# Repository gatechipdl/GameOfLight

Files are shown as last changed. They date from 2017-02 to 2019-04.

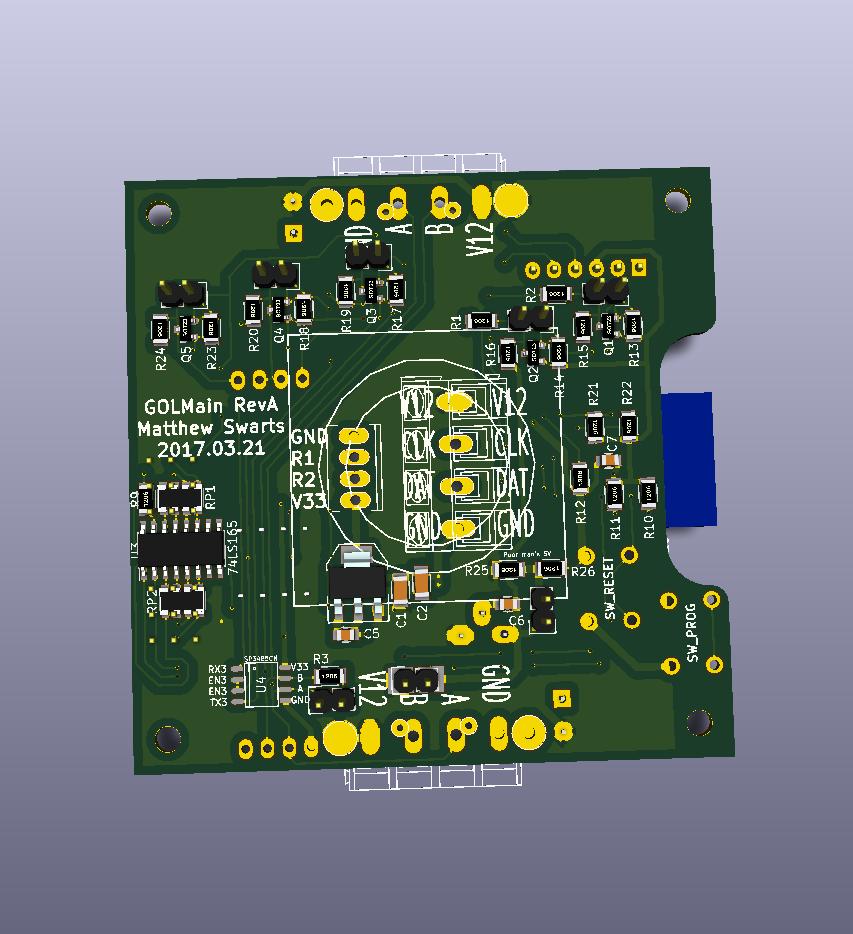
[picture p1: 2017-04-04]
electronics/GOLMain_RevA/GOLMain_RevA-render1.jpg

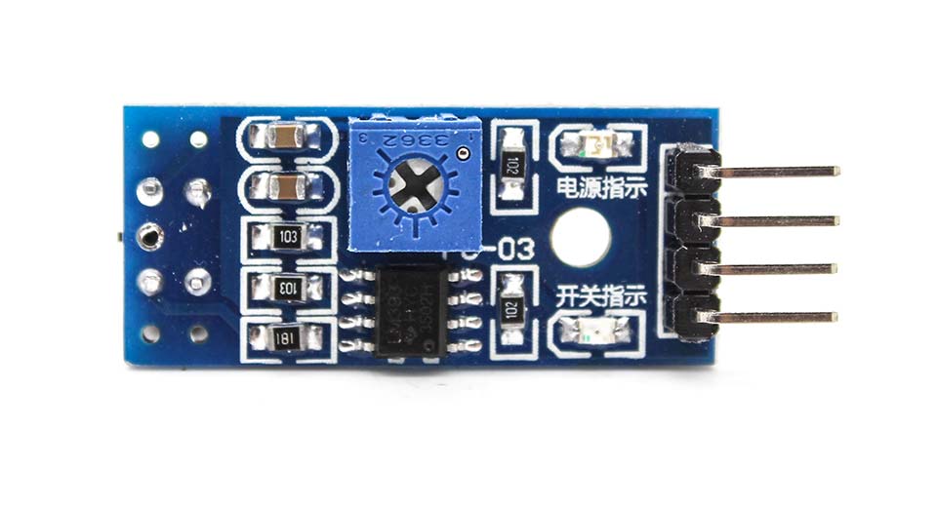
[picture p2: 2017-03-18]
electronics/TCRT5000/1506503-1.jpg

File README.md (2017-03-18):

# GameOfLight
Game of Light Installation

## Requirements
- 36 stations
- each station 1m in lenght covered in leds
- 5 sections of lamp to create a 'species'
- automatic identification of each lamp 'species'

## Location
- Hyatt Regency Denver at Co Convention Center
    - [Floorplans](https://denver.regency.hyatt.com/hyatt/images/hotels/dencc/floorplan.pdf)

## Main Power Supply
- 12,24V power supply recommended with a buck converter (for leds and mcu) or linear regulator (if for just mcu) at each location
- typical computer psu will have several 12V rails. A [modular](https://www.amazon.com/EVGA-Supernova-120-G1-1000-VR-Modular-Supply/dp/B00CGYCNG2) psu would be best for ensuring enough 12V rails without extra wiring.
- if there is 5m of leds with 30 leds/meter wrapped around a tube, then that is 150 leds. 150 leds at 60mA is 9A running at around 3V. This is around 27-30W assuming an efficient local conversion of power, which is likely embedded within the addressable chip.
- 36 stations of 30W is a total max draw of 1080W. So a 800W-1000W-1200W power supply should be fine.

## Local Power Regulation
- Switch mode power supply for high current, such as this [300W Step Down Regulator](https://www.aliexpress.com/item/DC-CC-12A-300W-Step-Down-Buck-Converter-7-32V-To-0-8-28V-Power-module/32247251105.html)
- Linear regulator for low current needs (eg. if using 12V main power supply and 12V leds)

## Power Distribution Connectors
- ribbon cable (40 pin), using most pins for power and ground
- RJ45 can only handle up to 1A
- RJ11 can only handle up to 1A
- 5557 molex need to crimp; not designed to be removed often;
- DC Barrel Jack 5.5mm, most connectors designed for 3A, but can get special ones for laptaps that can handle 8A
- [6 pin Pluggable Screw Terminal](https://www.aliexpress.com/item/Free-shipping-5-sets-ht5-08-6pin-Terminal-plug-type-300V-10A-5-08mm-pitch-connector/32667091061.html)
    - 12V - GND - DataMinus - DataPlus - GND - 12V
- [7 pin Pluggable Screw Terminal](https://www.aliexpress.com/item/Free-shipping-5-sets-ht5-08-7pin-Terminal-plug-type-300V-10A-5-08mm-pitch-connector/32665369867.html)
    - 12V - GND - DataMinus - GND - DataPlus - GND - 12V
    - extra ground in middle is for connecting ground to the main controller in the case that the main controller is not using the same ground as the stations' ground from the main power supply. For example if the main controller is run by or powered by a laptop.

## Power Distribution Wiring
- [$27 100 ft. 14/2 White Solid SIMpull NM-B Wire](http://www.homedepot.com/p/Romex-100-ft-14-2-White-Solid-SIMpull-NM-B-Wire-28827428/202316379)
- [$38 100 ft. 14-2 Black Stranded Landscape Lighting Cable](http://www.homedepot.com/p/Southwire-100-ft-14-2-Black-Stranded-Landscape-Lighting-Cable-55213243/202316247)
- [$16 100' Feet 14 Gauge Red Black Stranded 2 Conductor Speaker Wire Car Home Audio Ga](https://www.amazon.com/Gauge-Black-Stranded-Conductor-Speaker/dp/B00J36SUWC)
- [$26 eXtreme Products 2 Conductor 14 Gauge Stranded Copper Core Speaker Wire (No Aluminum Core) for Home Theater Speakers Radio Speakers Car Audio or Any Audio Interface - 100 Foot Clear Coat](https://www.amazon.com/eXtreme-Conductor-Speaker-Wire-Interface/dp/B01HBWJ1HM)

## Signal Distribution Wiring
- for RS485 we need overall impedance of 120 ohms. For our distances, lighter gauges are fine, but [this](http://www.chipkin.com/rs485-cables-why-you-need-3-wires-for-2-two-wire-rs485/) recommends 24AWG or heavier. [Here are more recommendations](http://www.bb-elec.com/Learning-Center/All-White-Papers/Serial/Cable-Selection-for-RS422-and-RS485-Systems/Cable-Selection-for-RS-422-and-RS-485-Systems.PDF).
- Two wire or Three wire. May need three wire to include an additional ground in the case that the main controller is not using the same ground as the stations' power ground from the main power supply. This could be the case with a laptop for example.
- [$13 Ethernet Cable (100 Feet)](https://www.amazon.com/Mediabridge-Ethernet-Cable-100-Feet/dp/B003RCEAB8), cut and pull out twisted pair wires
- [$23 100-Feet 24-Gauge 4 Pair Cat 5e](https://www.amazon.com/Southwire-56917643-100-Feet-Outdoor-CMR-75-Degree/dp/B005V0BJ1S)

## LEDs
- addressable color leds
- could use 1 2m strip folded over
- could use 1 5m strip wrapped around a pole (this will provide more light)
- WS2811 with 3 color leds on each section, each led is rgb, but in clusters of 3. This is fine for our applications. Also these are 12V, which is better for current draw. [$8-10 per 5m strip](https://www.aliexpress.com/item/best-price-5m-DC12V-ws2811ic-5050-RGB-SMD-individually-addressable-ws2811-led-pixels-strip/32385533484.html)

## Control
- recommended individual controller for each station; otherwise refresh rate is likely to be very slow
- attiny85 possible? may not have enough pins; but might
- atmega328p?
- arduino pro mini clone ($1-2)
- 1 master device with 36 other devices. The master controls the CA simulation and dictates the animation colors and patterns to each of the 36 stations.
    - however, it is possible to have the 36 devices run the simulation themselves, with each device getting data about it's neighbors, and computing the next step and selecting it's own animation. This would also require that they all synchronize, to some degree on an update algorithm. This could be done. Would be really nice to have. This is something we could first develop in the master/slave configuration, and then later spend time developing the slave-only method if there is time. The slave-only would really connect conceptually rather than having any kind of single master.

## Recognition
- manual input (what a drag)
- infrared linear quadrature encoder or similar to recognize the lamp 'species' as a barcode when the lamp shade is slide over the rod
    - this would argue for a separate controller on each station
- IR Distance Sensor
    - [XK-GK-5010A](https://www.aliexpress.com/item/Hot-Sale-Short-Distance-Sensor-Induction-Switch-Dual-Functions-Ir-Sensor-Switch-Active-Performance-Modules-Board/32769983297.html)
    - [TCRT5000 Sensor](https://www.aliexpress.com/item/20-pcs-TCRT5000L-TCRT5000-Reflective-Optical-Sensor-Infrared-IR-Photoelectric-Switch/1909098476.html)
    - [TCRT5000 Module with Pot](https://www.aliexpress.com/item/Free-shipping-Line-Track-Sensor-TCRT5000-Infrared-Reflective-IR-Photoelectric-Switch-Barrier/32517344067.html) [3D model](http://www.stlfinder.com/model/line-finder-tcrt5000/4505787) 32mmx14mm
    - [TCRT5000 Module Digital Only](https://www.aliexpress.com/item/New-TCRT5000-Line-Track-Sensor-Module-Reflection-Infrared-Sensor-Switch-Module-For-Arduino-5pcs-lot-Free/32359412782.html)
    - [TCRT5000 Module Analog Only](https://www.aliexpress.com/item/10PCS-IR-Infrared-Line-Track-Follower-Sensor-TCRT5000-Obstacle-Avoidanc-For-Arduino/32672744833.html)
    - [4 Channel Line Follower](https://www.aliexpress.com/item/Free-shipping-4-way-infrared-tracing-line-follow-tracking-obatacle-avoidance-Sensor-Module-for-Aduino-Robot/32645816426.html)
    - [8 Channel Line Follower](https://www.aliexpress.com/item/8-Channel-High-Precision-Infrared-Detection-Tracking-Sensor-Moudle-For-Arduino-Raspberry-Pi-Car-Robot-TCRT5000/32714804808.html)

## Communication
- if using multiple controllers, one on each station, using a [multidrop bus](https://en.wikipedia.org/wiki/Multidrop_bus) rather than a shift/ring topology
- I2C can go about [20ft](http://forum.arduino.cc/index.php?topic=57604.0) without additional driver or buffers
- RS-232 can go about [50ft](https://www.lammertbies.nl/comm/info/RS-232_specs.html)
- RS-422 can go about 5000ft, but is single driver/master, and up to 10 receivers. It is differential, so it's more noise immune than rs232, but the primary downside is it is one directional communcation
- RS-485 can go about [4000ft](http://www.bb-elec.com/Learning-Center/All-White-Papers/Serial/Basics-of-the-RS-485-Standard.aspx)
    - RS-485 to ttl converter using the MAX485CSA
    - $0.38 [Module](https://www.aliexpress.com/item/MAX485-Module-RS-485-TTL-to-RS485-MAX485CSA-Converter-Module-For-Arduino-Integrated-Circuits-Products/32667981058.html)
    - needs twisted pair wire (same as RS422); actually can go without twisted pair if run is shorter, so this isn't completely necessary
    - downside is that RS485 supports up to 32 devices. But I don't think that is built into the protocol. We should be able to go over that. As each device will have it's own way of identifying itself. I think 32 devices is more of a guideline.
    - RS-485 might need a 3.3V version like the [SP3485 Module](https://www.aliexpress.com/item/3-3V-UART-serial-to-RS485-SP3485-Transceiver-Converter-Communication-Module/32224154908.html). This board is lower cost than if we were to purchase just the chip and integrate it into our own design.

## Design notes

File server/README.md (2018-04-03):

# Light Orchard Server
Light Orchard Server

## System Architecture
### Components
|Component|Purpose|
|---|---|
|Web Client|Connects to Web Server through Socket.IO and POST|
|Web Server|Routes requests between Web Clients and Stations|
|Station|Displays colors and senses capcitive touch leves|
### Orchard Analogy?
|Analogy|System Component|
|---|---|
|Orchard|System|
|Orchardist|Web Server|
|Tree|Station|
|Branch/Frond/Fruit|Pixel (5/Station)|
|Leaf/Frond/Fruit/Seed/Bud|LED (45/Station)|

## Web Client API
### Helper/Wrapper Methods (actual API)
|Status|Method Name|Description|
|---|---|---|
|planned1|RGB2HSV()|or just use npm color|
|planned1|HSV2RGB()|or just use npm color|
|planned2|orchard-client.setStationColors()||
|planned2|orchard-client.setStationColor()||
|planned2|orchard-client.setPixelColor()||
|planned2|orchard-client.listGroup()||
|planned2|orchard-client.listGroups()||
|planned2|orchard-client.createGroup()||
|planned2|orchard-client.renameGroup()||
|planned2|orchard-client.deleteGroup()||
|planned2|orchard-client.addToGroup()||
|planned2|orchard-client.setGroupColor()||
|planned2|orchard-client.requestDataModel()||
|planned2|orchard-client.setCapMode()||
|planned2|orchard-client.setCapFreq()||
|planned2|orchard-client.onCapSenseTouch(<event handler delegate>)||
|planned2|orchard-client.onCapSenseUnTouch(<event handler delegate>)||
|planned2|orchard-client.onCapSenseHold(<event handler delegate>)||
|planned2|orchard-client.onCapSenseUnHold(<event handler delegate>)||
|planned2|orchard-client.onCapSenseDoubleTap(<event handler delegate>)||
|planned2|orchard-client.onGroupList(<event handler delegate>=)||
|planned2|orchard-client.onDataModel(<event handler delegate>=)||
### Incoming Socket.IO Events from Web Server
see Web Server API - Outgoing Socket.IO Events
### Outgoing Socket.IO Events to Web Server
see Web Server API - Incoming Socket.IO Events
### Example Use
```javascript
var socket = io.connect('/');

socket.on('connect', function() {
    socket.emit('subscribe', 'browsers'); //to receive CapSenseEvent, CapSenseTouch, CapSenseUnTouch
});

function setStationColor() {
    var tData = {};
    tData['station_id'] = '1'; //station number 1; strings allow more flexibility in naming
    tData['colors'] = [
        [255,0,0], //bottom is red
        [255,255,0], //yellow
        [0,255,0], //green
        [0,255,255], //cyan
        [0,0,255] //top is blue
        ];
    socket.emit('SetFiveColors', tData);
}
setStationColor();

function CapSenseEventListener(socket){
    socket.on('CapSenseEvent', function(data) {
        console.log(
            'station '+data['station_id']+
            ' on sensor '+data['sensor_id']+
            ' has a value of '+data['value']
        );
    });
}
CapSenseEventListener(socket);

function CapSenseTouchListener(socket){
    socket.on('CapSenseTouch', function(data) {
        console.log(
            'station '+data['station_id']+
            ' on sensor '+data['sensor_id']+
            ' was touched'
        );
    });
}
CapSenseTouchListener(socket);
```

## Web Server API
### Incoming Socket.IO Events from Web Client
|Status|Message Name|Description|
|---|---|---|
|active|'SetFiveColors'|{'station_id":<#>, 'colors':[ [255(R),255(G),255(B)](bottom),[0,0,0],[0,0,0],[0,0,0],[0,0,0] ]}|
|active|'SetMode'||
|planned1|'setStationColors'|renaming of 'SetFiveColors'|
|planned1|'setMode'|renaming of 'setMode'|
|planned2|'setStationColor'|just one color|
|planned2|'setPixelColor'|just one pixel on one station|
|planned2|'listGroup'|list members of one group|
|planned2|'listGroups'|list groups|
|planned2|'createGroup'|create group|
|planned2|'renameGroup'|rename group|
|planned2|'deleteGroup'|delete group|
|planned2|'addToGroup'|add stations and/or pixels to a group|
|planned2|'setGroupColor'|change color of pixels in stations in the group|
|planned2|'requestDataModel'|submits request for current data model with pixel colors, groups, states, and capsense values|
|planned2|'setCapMode'|Set capsense mode between event based or stream. Default is event based.|
|planned2|'setCapFreq'|Set capsense emission frequency. Default 10 Hz|
### Outgoing Socket.IO Events to Web Client
|Status|Message Name|Description|
|---|---|---|
|active|'CapSenseEvent'|{'station_id':<#>,'sensor_id':<#>,'value':<#>}|
|active|'CapSenseTouch'|{'station_id':<#>,'sensor_id':<#>}|
|active|'CapSenseUnTouch'|{'station_id':<#>,'sensor_id':<#>}|
|planned1|'capSenseTouch'|rename from 'CapSenseTouch'|
|planned1|'capSenseUnTouch'|rename from 'CapSenseUnTouch'|
|planned1|'capSenseHold'||
|planned1|'capSenseUnHold'||
|planned1|'capSenseDoubleTap'||
|planned2|'groupList'||
|planned2|'dataModel'|emits current data model with pixel colors, groups, states, and capsense values|
### Incoming Socket.IO Events from Stations
see Firmware Level API - Outgoing Socket.IO Events
### Outgoing Socket.IO Events to Stations
see Firmware Level API - Incoming Socket.IO Events
### Incoming UDP Events from Stations
see Firmware Level API - Outgoing UDP Events
### Outgoing UDP Events to Stations
see Firmware Level API - Incoming UDP Events

## Firmware Level API
### Incoming Socket.IO Events from Web Server
|Status|Message Name|Description|
|---|---|---|
|active|'connect'|Called on connection to websocket server. Emits "subscribeStation" message with station ID.|
|active|'getInfo'|Request to send "idhostnameipmac"|
|active|'clear'|Sets all colors to black and does FastLED.show()|
|active|'fillSolid'|Sets all 45 leds to same color using FastLED.fill_solid()|
|active|'setColor'|Sets one led to one color using leds[index].r,leds[index].g,leds[index].b|
|active|'setColors'|Sets a set of leds to colors based on sets of 3 bytes in the payload|
|active|'setFives'|Sets groups of 9 leds to one of 5 colors from a 15 byte payload|
|active|'checkForUpdate'|Calls ESPhttpUpdate.update() to check for new firmware|
|active|'setMode'|Changes the Operate function deleate to a new operationMode index|
|active|'setStationId'|Sets the provided 16 bit integer at the new stationId and commits it to EEPROM|
|planned1|'getNetworkInfo'|request network settings of the station|
|planned1|'setUDP'|Set UDP port and addresses|
|planned2|'setCapMode'|Set capsense mode between event based or stream. Default is event based.|
|planned2|'setCapFreq'|Set capsense emission frequency. Default 10 Hz|
### Outgoing Socket.IO Events to Web Server
|Status|Message Name|Description|
|---|---|---|
|active|'capSense'|Sends current value of a changed capsense along with stationId|
|active|'subscribeStation'|Sends request to Subscribe to the stationId channel and the 'station' channel too|
|active|'idhostnameipmac'|Message with station Id, hostname, IP address, mac address, and firmware version.|
|planned1|'networkInfo'|sent network settings|
### Incoming UDP Events from Web Server
|Status|Message Name|Description|
|---|---|---|
|planned1|SetFivesUDP(data)|{'station_id":<#>, 'colors':[ [255(R),255(G),255(B)](bottom),[0,0,0],[0,0,0],[0,0,0],[0,0,0] ]}|
|planned2|SetOneUDP(data)|Set 1 of 5 pixels on the station|
### Outgoing UDP Events to Web Server
|Status|Message Name|Description|
|---|---|---|
|planned1|onTouchTrigger|Send capsense id with a value of 255|
|planned1|onUnTouchTrigger|Send capsense id with a value of 0|
|planned2|onCapsense|Stream out all capsense values at specified frequency|

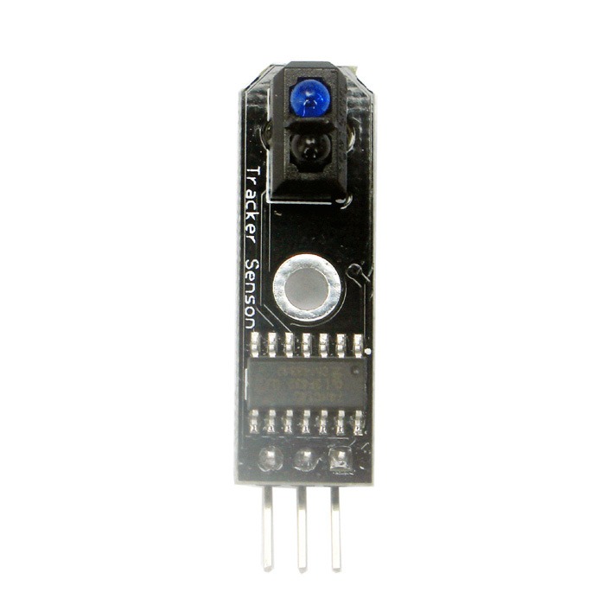
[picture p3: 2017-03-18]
electronics/TCRT5000/edd2342158aee075606fc3c7e305d2cc.jpeg

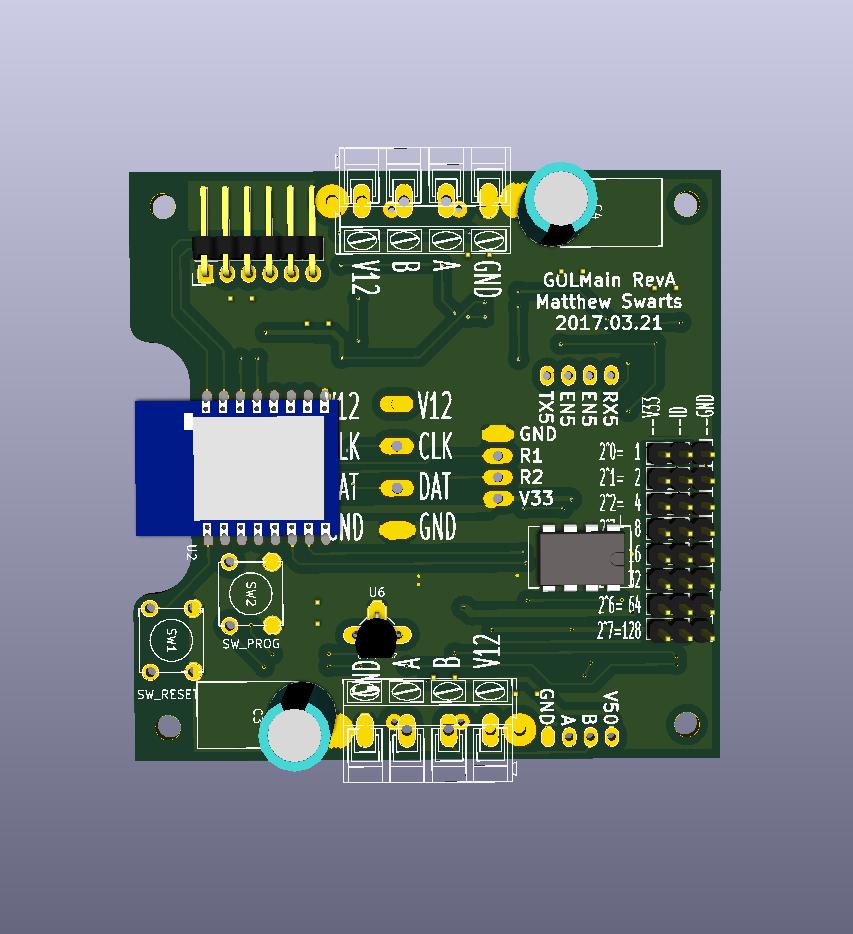
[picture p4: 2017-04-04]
electronics/GOLMain_RevA/GOLMain_RevA-render2.jpg

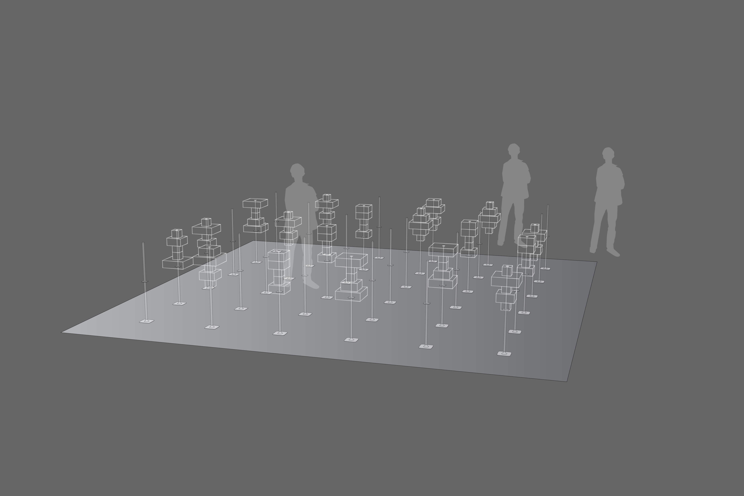
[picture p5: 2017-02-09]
idea renders/standing game of light_render-02.png

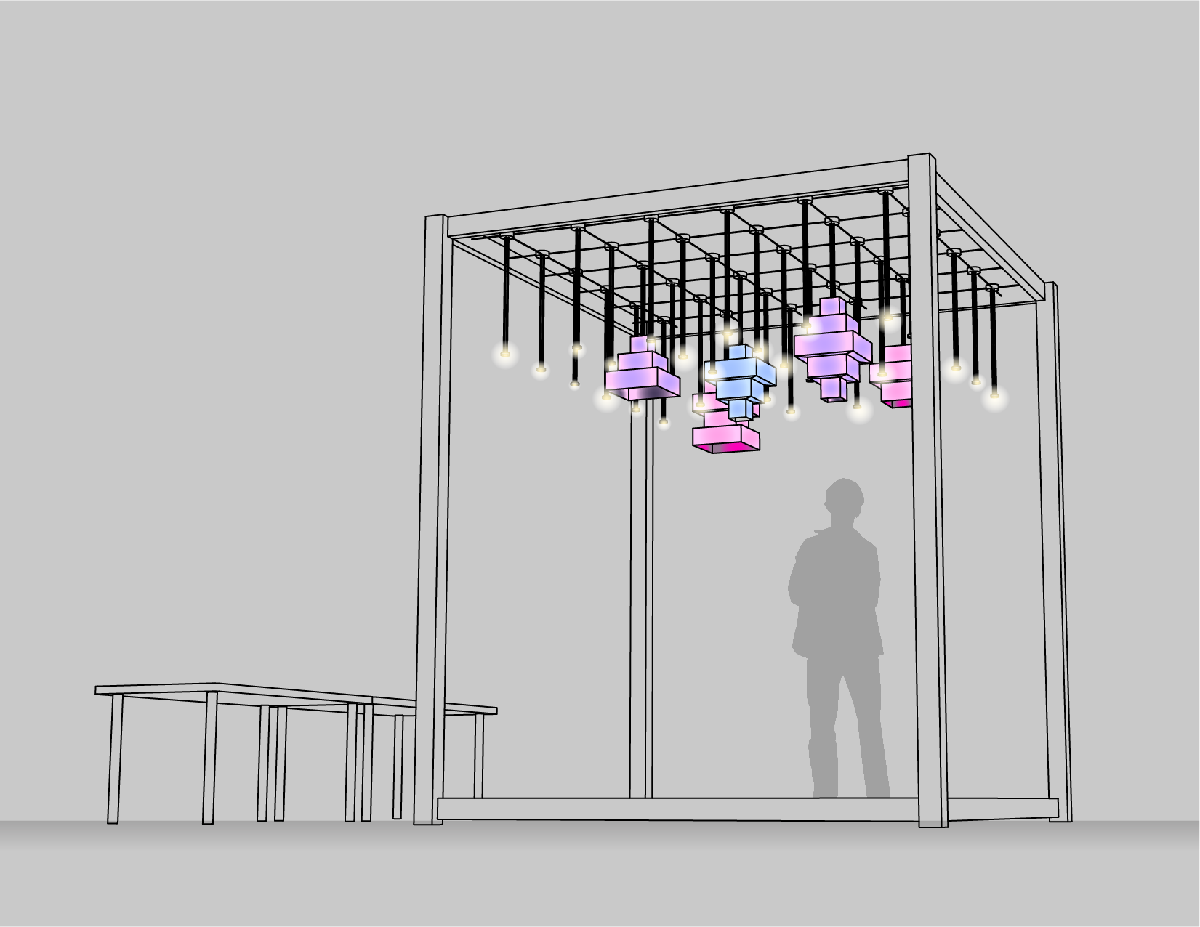
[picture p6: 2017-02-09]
idea renders/hanging game of light_render-02.png

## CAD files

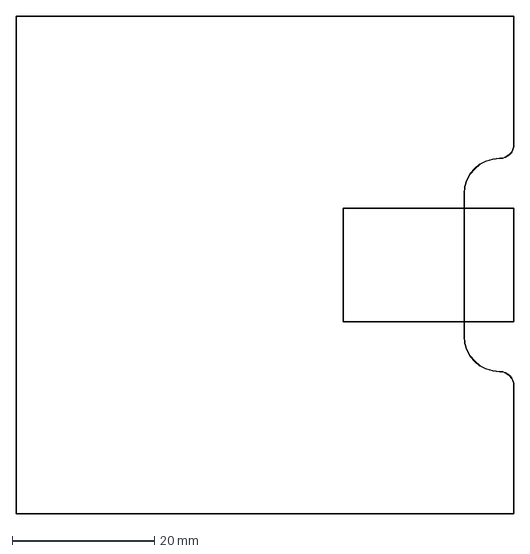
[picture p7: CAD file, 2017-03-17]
electronics/LO_Main_RevB/LO_Main_RevB-outline.dxf
70.0 x 70.0 mm

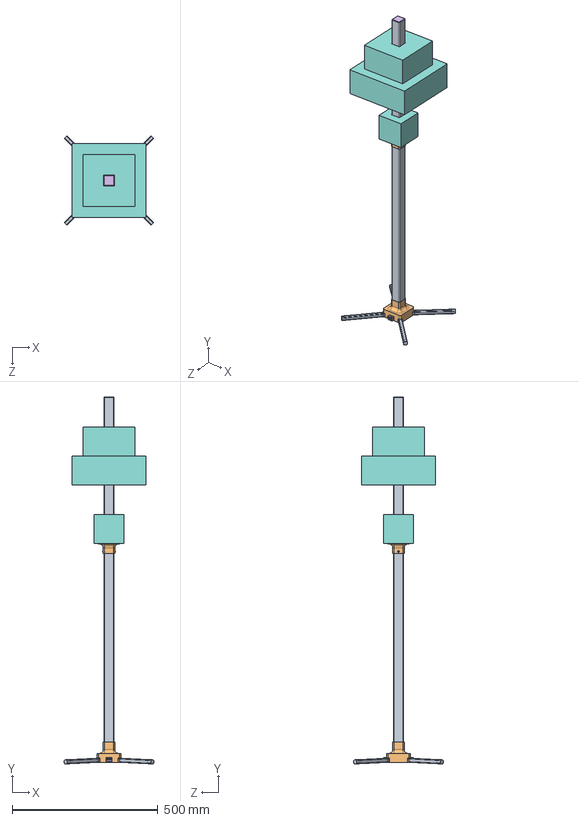
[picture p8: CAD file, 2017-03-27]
Solidworks/LampV3/GameOfLightLamp_V3.SLDASM
307.2 x 1257.8 x 307.2 mm
Tube
BottomCap^GameOfLightLamp_V3
MainBoard
Part1^MainBoard
BottomLid^GameOfLightLamp_V3
TopCap^GameOfLightLamp_V3
PVC^GameOfLightLamp_V3
LegTube x 3
HoldingCap^GameOfLightLamp_V3
94500A223_TYPE 316 SS BUTTON-HEAD SOCKET CAP SCREW x 6

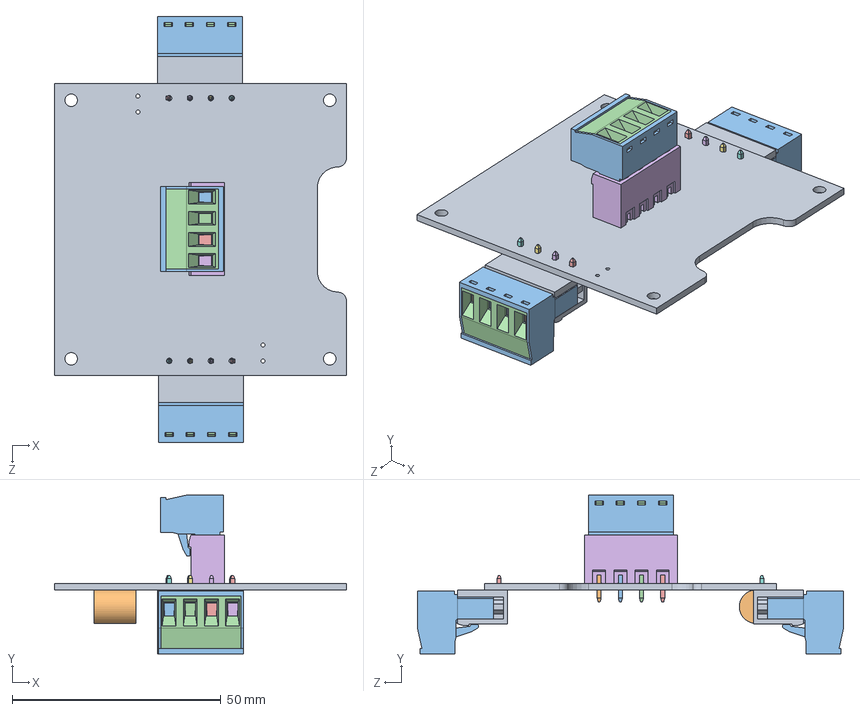
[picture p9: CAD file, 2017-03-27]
Solidworks/LampV3/MainBoard.SLDASM
70.0 x 38.1 x 102.2 mm
MainBoard
Part1^MainBoard

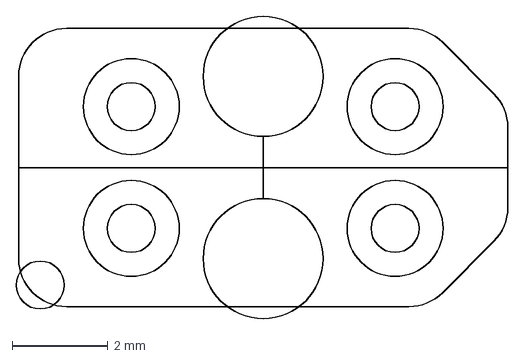
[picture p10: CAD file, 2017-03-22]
electronics/TCRT5000/TCRT5000-comp.dxf
10.2 x 6.30 mm

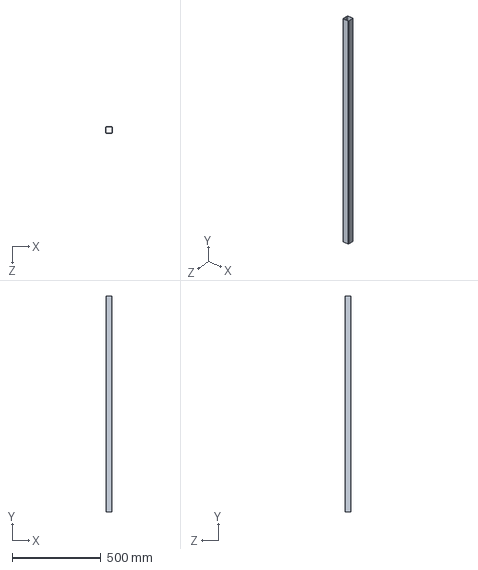
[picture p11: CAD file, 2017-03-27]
Solidworks/LampV3/Tube.SLDPRT
35.6 x 1219.2 x 35.6 mm

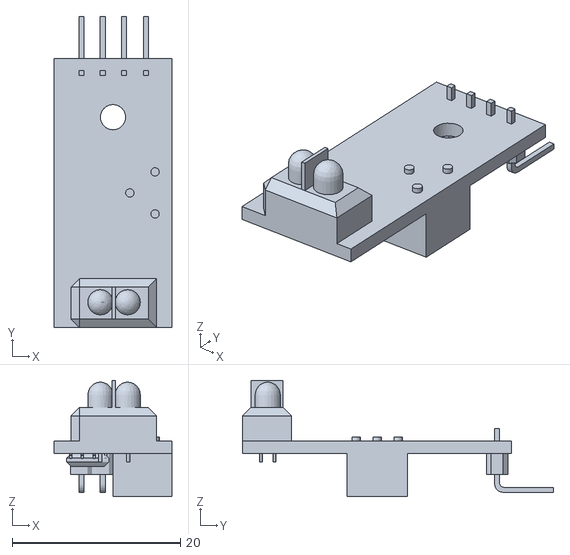
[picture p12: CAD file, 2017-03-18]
electronics/TCRT5000/TCRT5000.stl
14.0 x 37.0 x 13.8

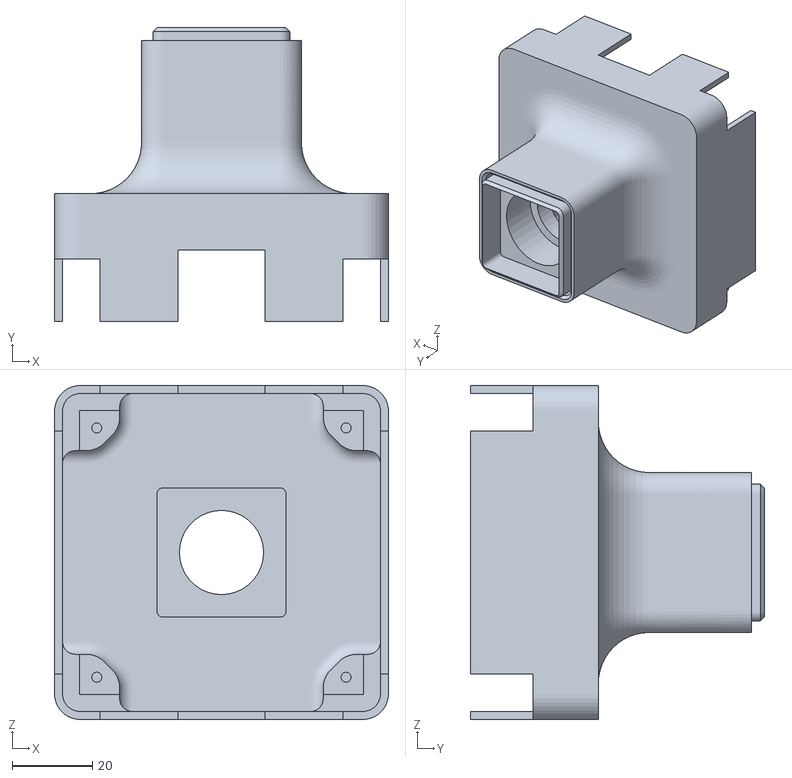
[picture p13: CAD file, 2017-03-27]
Solidworks/LampV3/GameOfLightLamp_V3 - BottomCap^GameOfLightLamp_V3-1.STL
83.0 x 73.0 x 83.0

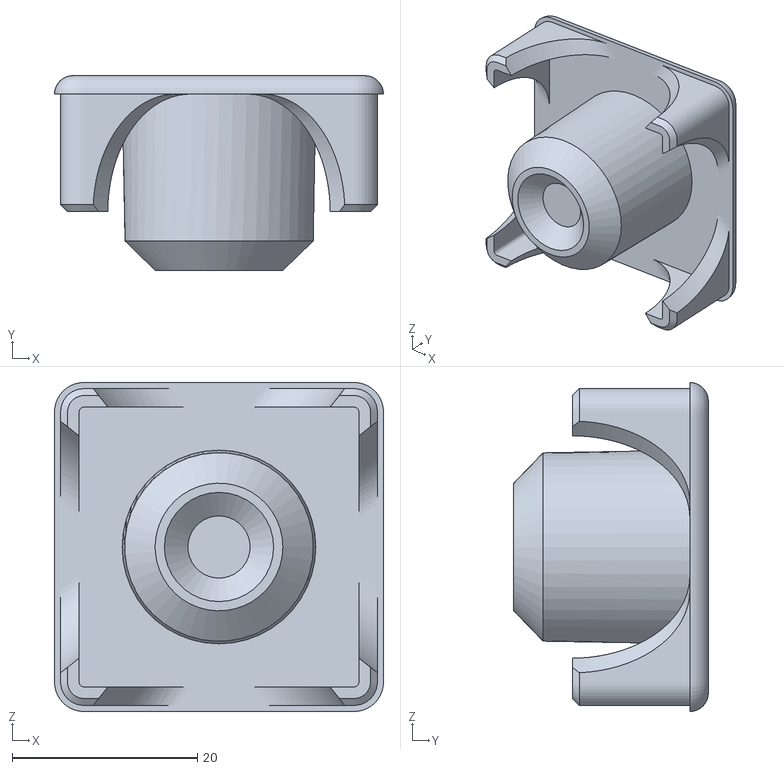
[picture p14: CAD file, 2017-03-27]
Solidworks/LampV3/GameOfLightLamp_V3 - TopCap^GameOfLightLamp_V3-1.STL
35.6 x 21.0 x 35.6

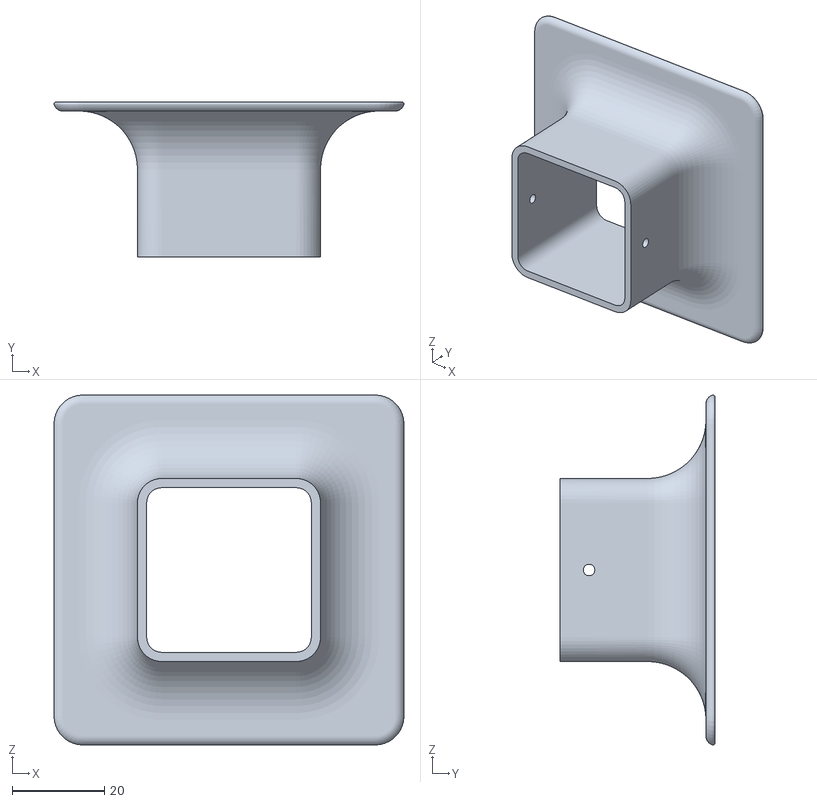
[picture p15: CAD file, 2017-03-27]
Solidworks/LampV3/GameOfLightLamp_V3 - HoldingCap^GameOfLightLamp_V3-1.STL
76.0 x 33.8 x 76.0

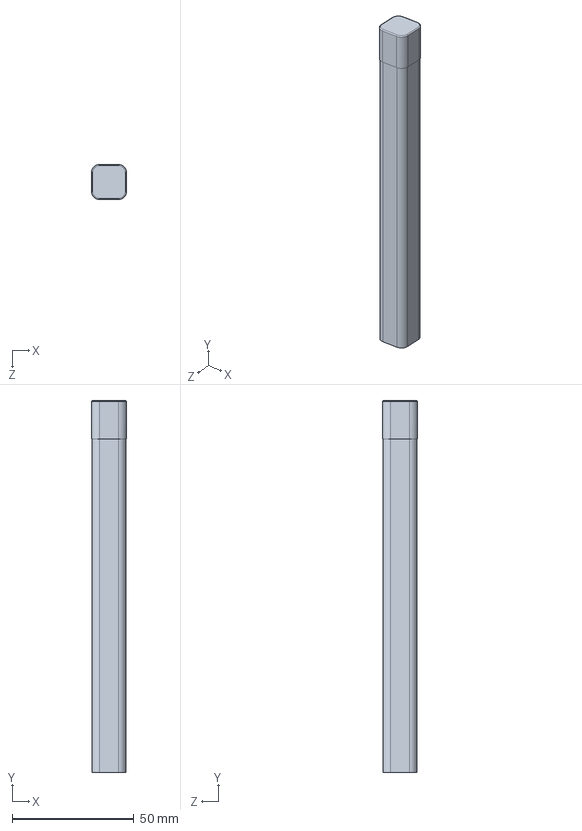
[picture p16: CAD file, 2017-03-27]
Solidworks/LampV3/LegTube.SLDPRT
14.5 x 152.9 x 14.5 mm

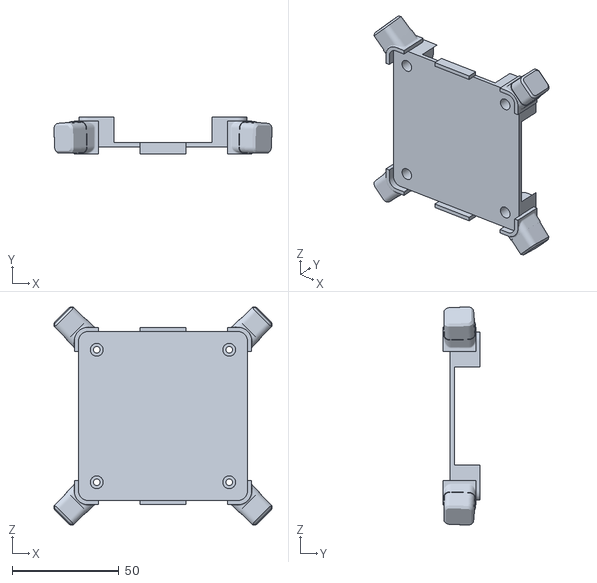
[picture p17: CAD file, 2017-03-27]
Solidworks/LampV3/GameOfLightLamp_V3 - BottomLid^GameOfLightLamp_V3-1.STL
102.0 x 17.3 x 102.0

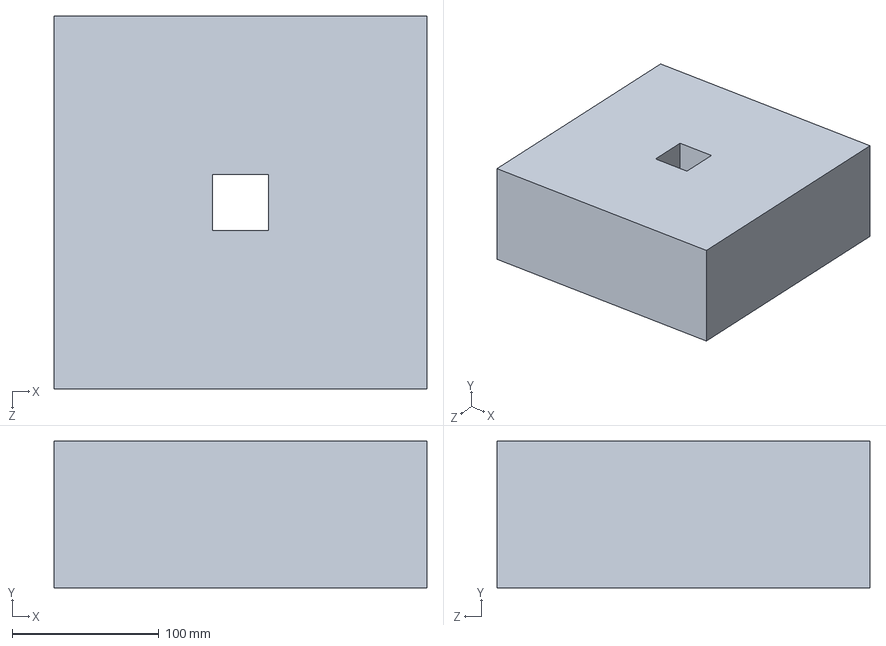
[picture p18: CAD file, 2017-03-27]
Solidworks/LampV3/LampShade.SLDPRT
254.0 x 100.0 x 254.0 mm

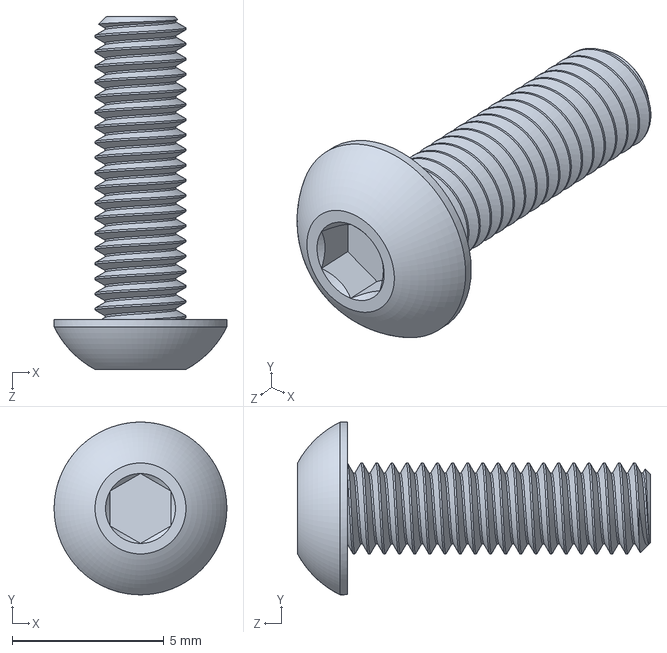
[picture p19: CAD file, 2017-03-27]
Solidworks/LampV3/94500A223_TYPE 316 SS BUTTON-HEAD SOCKET CAP SCREW.SLDPRT
5.70 x 5.70 x 11.6 mm

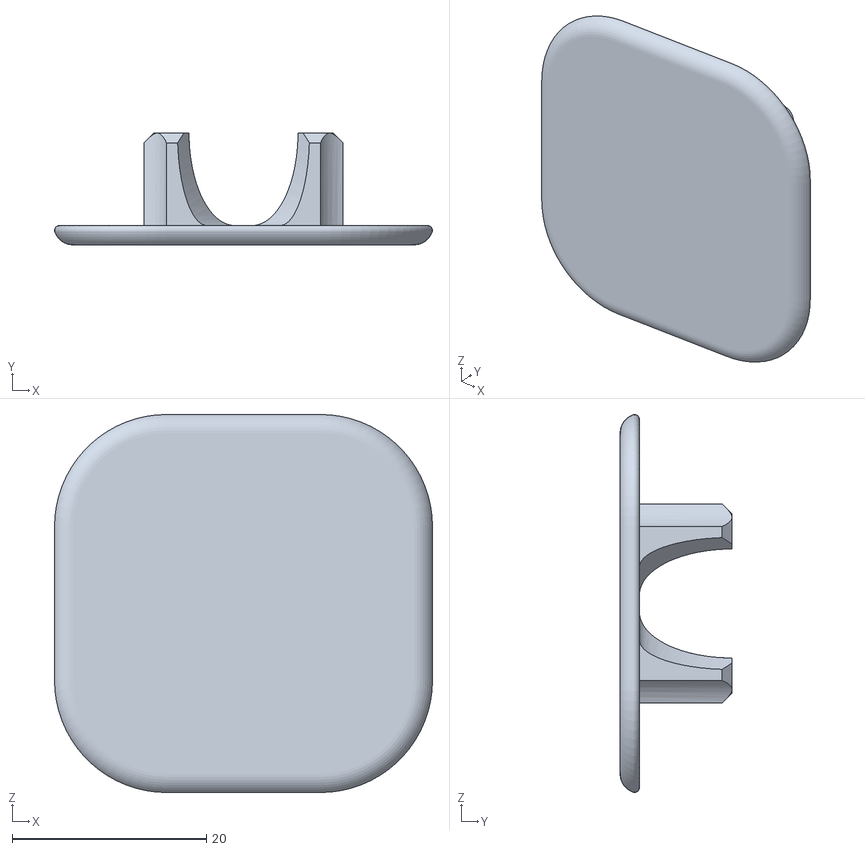
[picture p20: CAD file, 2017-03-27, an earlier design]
Solidworks/LampV2/LampBlock_V2_BottomPlate_Fuller.STL
39.0 x 11.5 x 39.0

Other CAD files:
electronics/TCRT5000/TCRT5000-layout.dwg
Solidworks/LampV1/LampBlock_V1_Top.sldprt
Solidworks/LampV2/LampBlock_V2_Bottom.sldprt
Solidworks/LampV1/LampBlock_V1_Hook.sldprt
Solidworks/LampV1/LampBlock_V1.SLDPRT
Solidworks/LampV1/LampBlock_V1_Bottom.STL
Solidworks/LampV1/LampBlock_V1_Bottom.sldprt
Solidworks/LampV1/LampBlock_V1_Hook.STL
Solidworks/LampV1/LampBlock_V1_Top.STL
Solidworks/LampV2/LampBLock_V2_Hook4.STL
Solidworks/LampV2/LampBLock_V2_Hook4.sldprt
Solidworks/LampV2/LampBLock_V2_PlateSupport.STL
Solidworks/LampV2/LampBLock_V2_PlateSupport.sldprt
Solidworks/LampV2/LampBlock_V2.SLDPRT
Solidworks/LampV2/LampBlock_V2_Bottom.STL
Solidworks/LampV2/LampBlock_V2_BottomPlate.STL
Solidworks/LampV2/LampBlock_V2_BottomPlate.sldprt
Solidworks/LampV2/LampBlock_V2_BottomPlate_Draft.STL
Solidworks/LampV2/LampBlock_V2_BottomPlate_DraftPart.STL
Solidworks/LampV2/LampBlock_V2_BottomPlate_Fillet.STL
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

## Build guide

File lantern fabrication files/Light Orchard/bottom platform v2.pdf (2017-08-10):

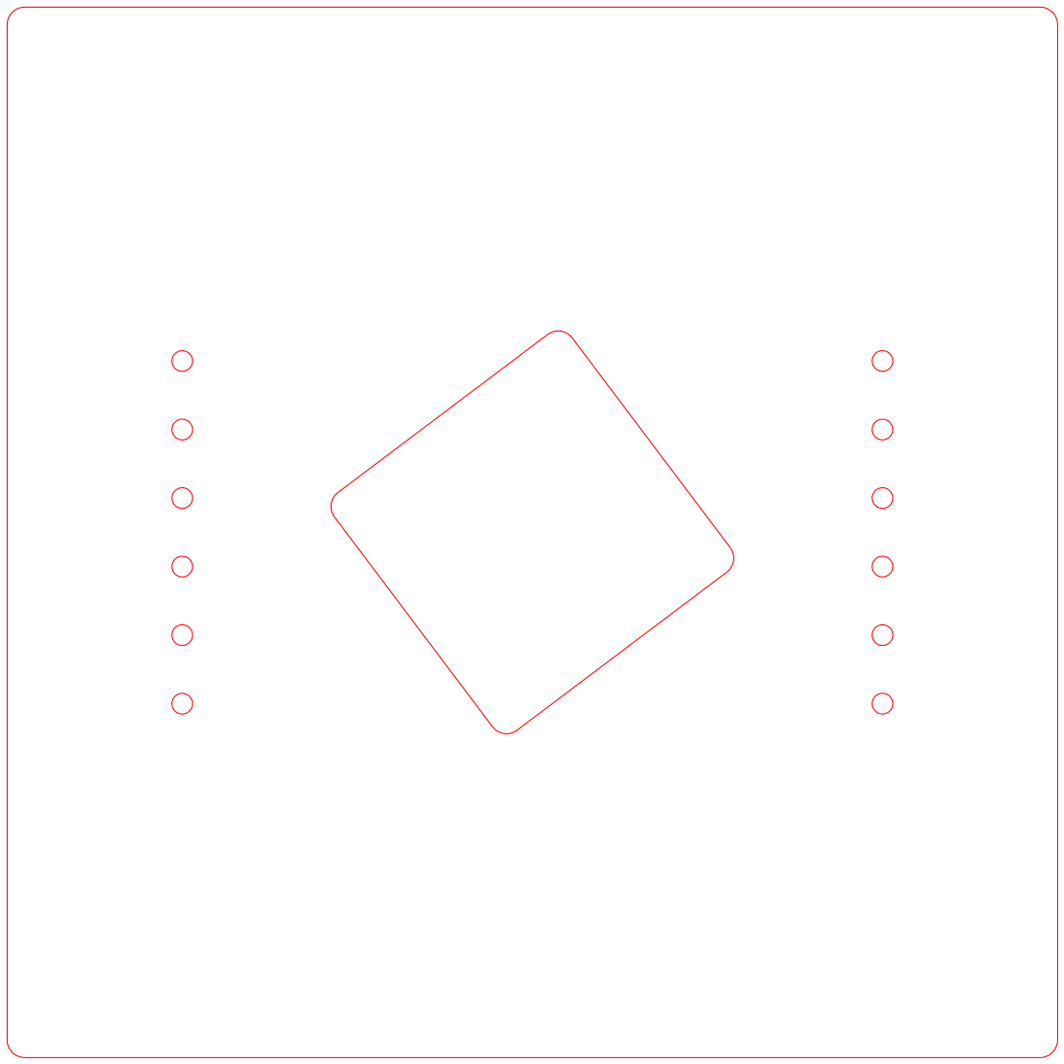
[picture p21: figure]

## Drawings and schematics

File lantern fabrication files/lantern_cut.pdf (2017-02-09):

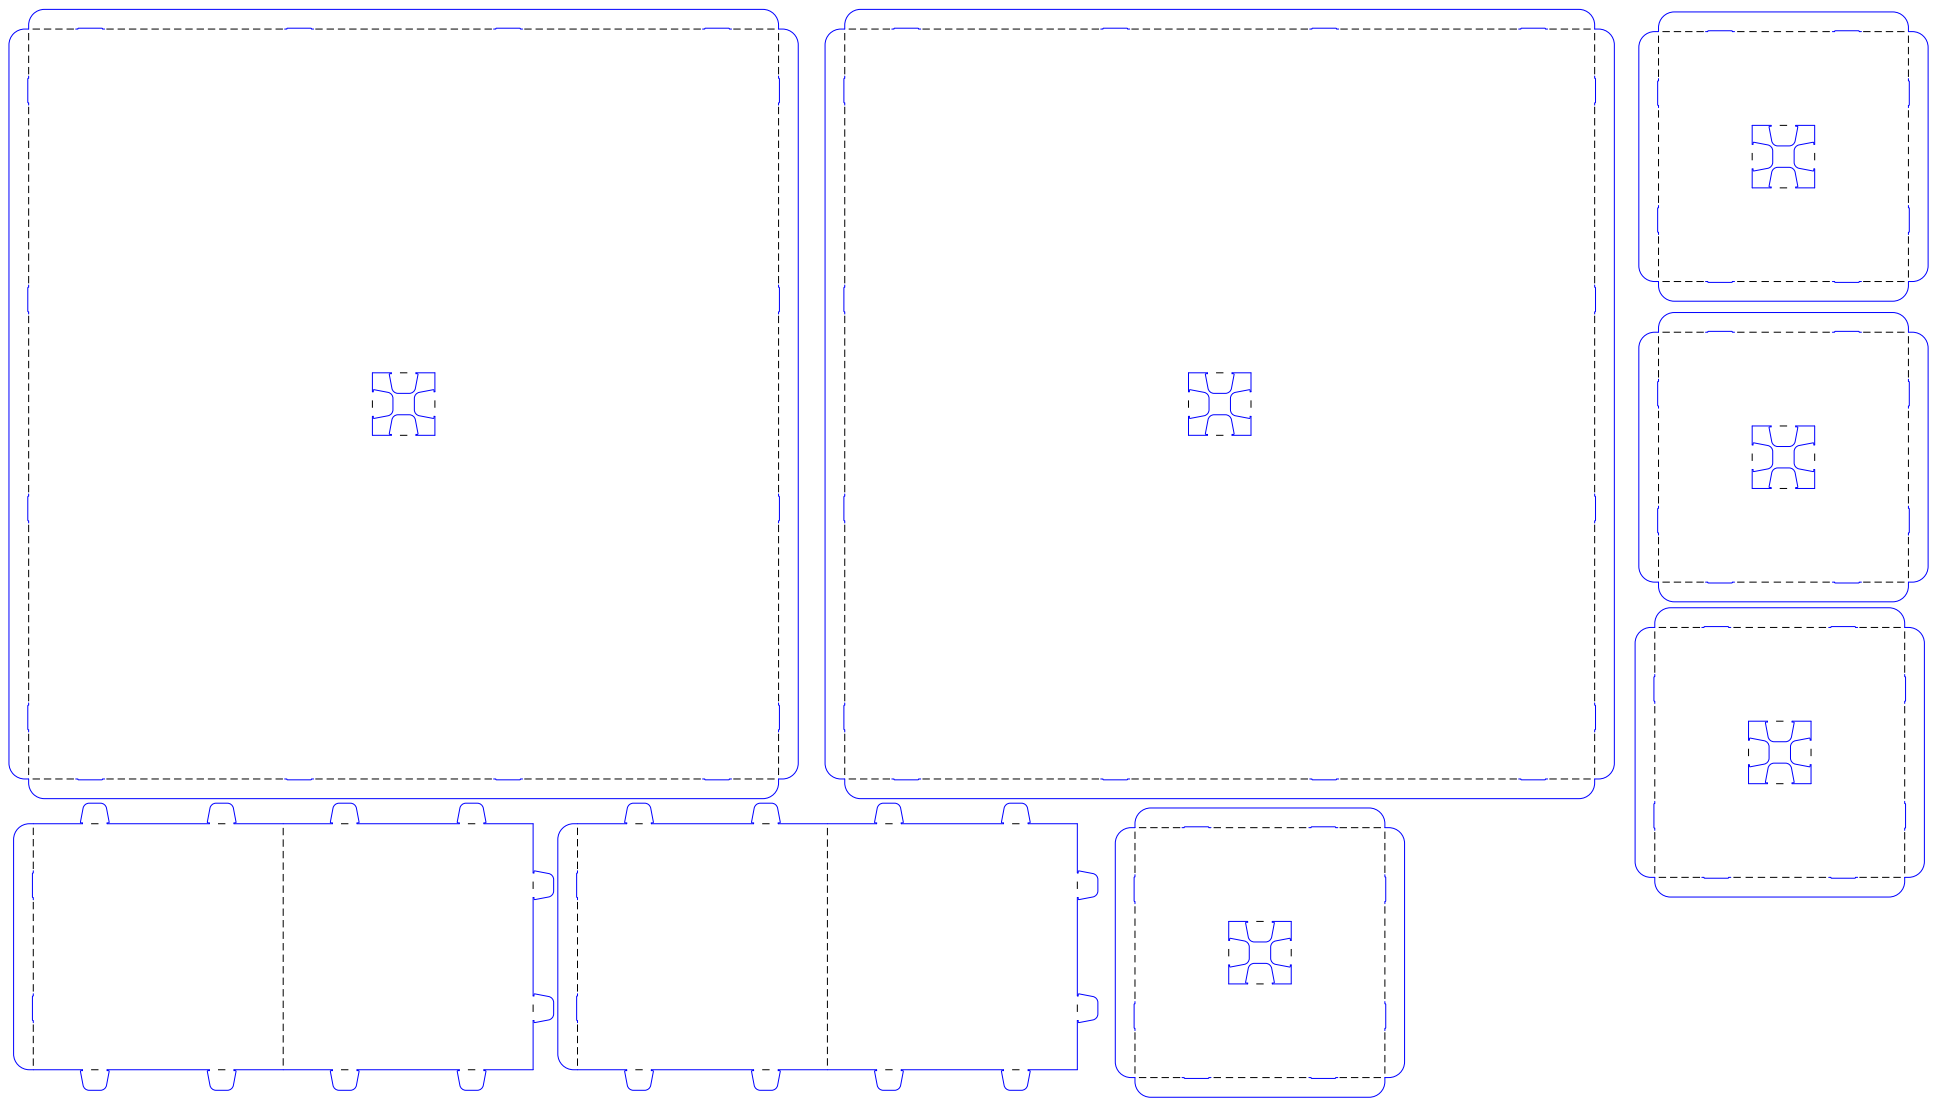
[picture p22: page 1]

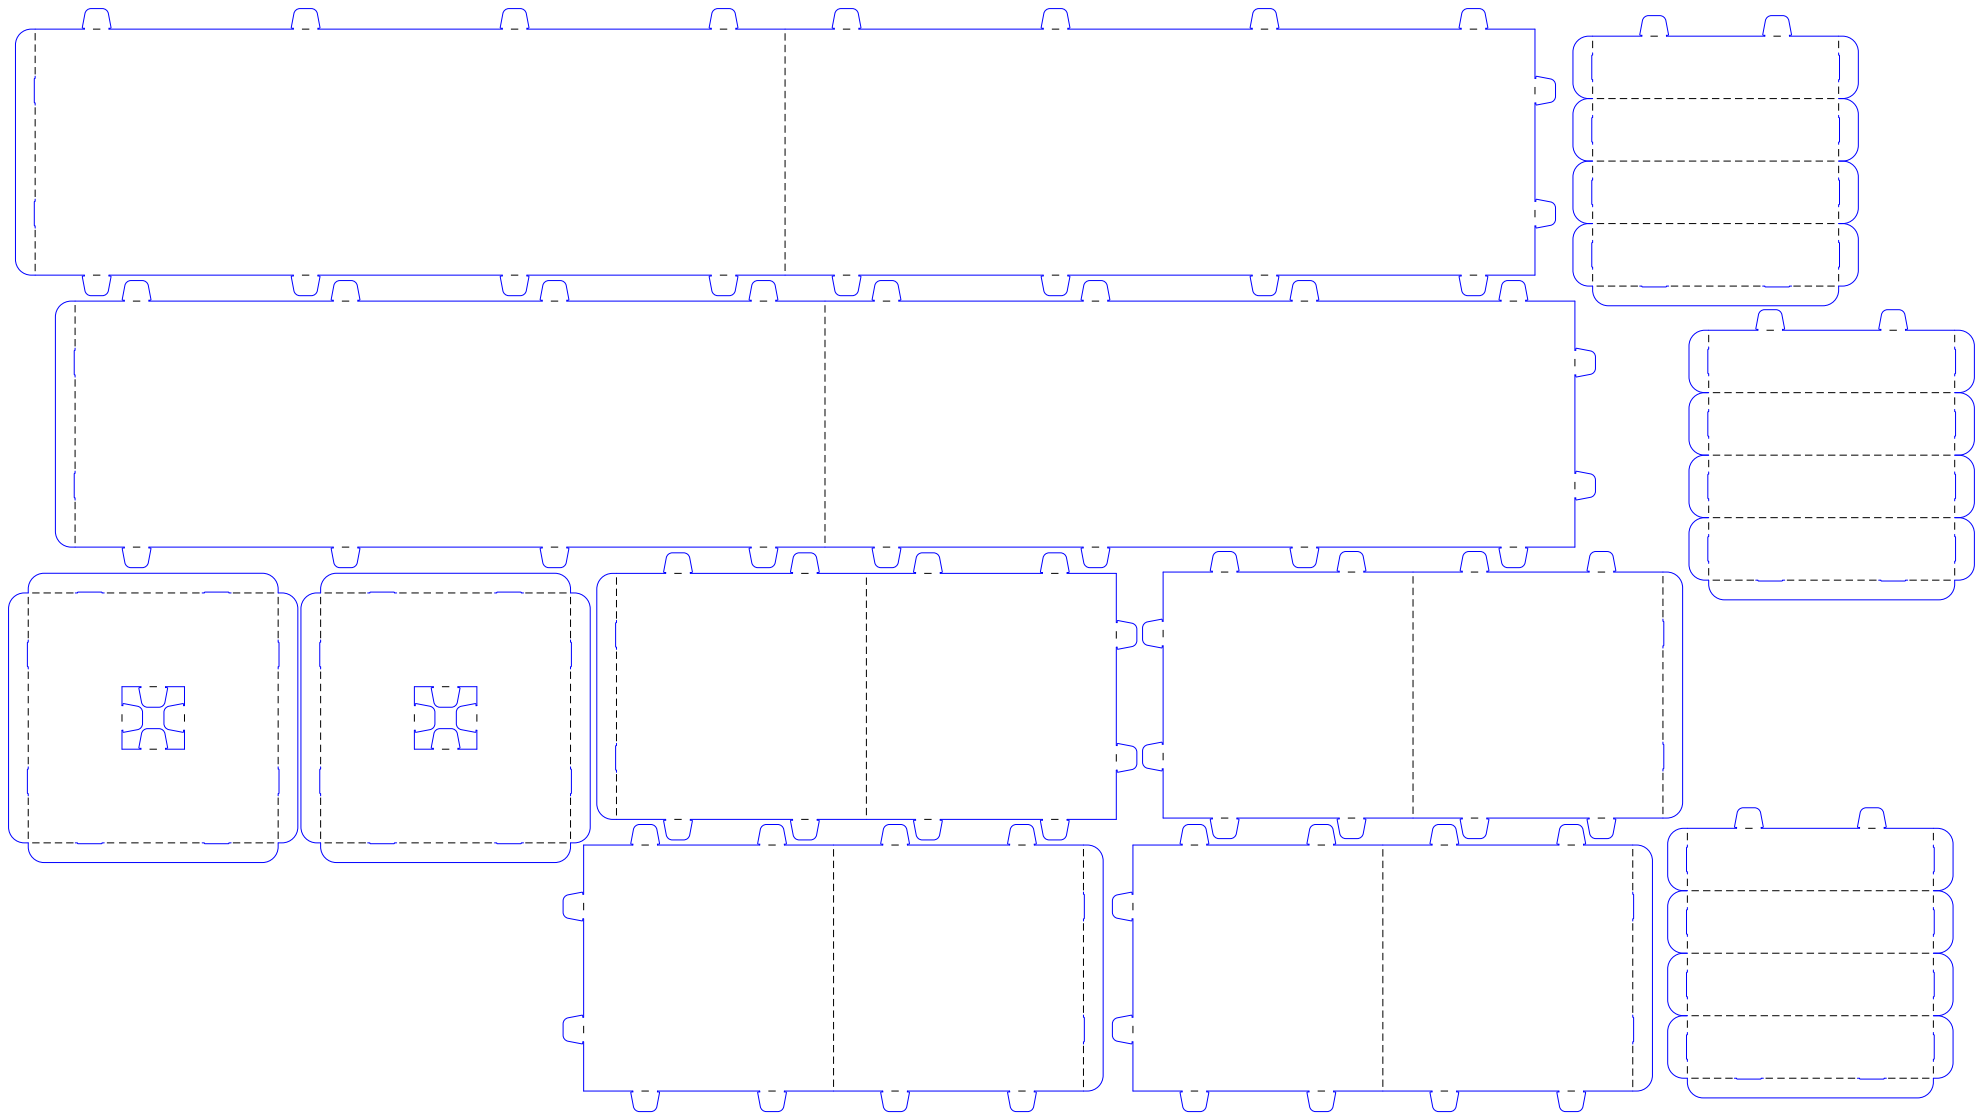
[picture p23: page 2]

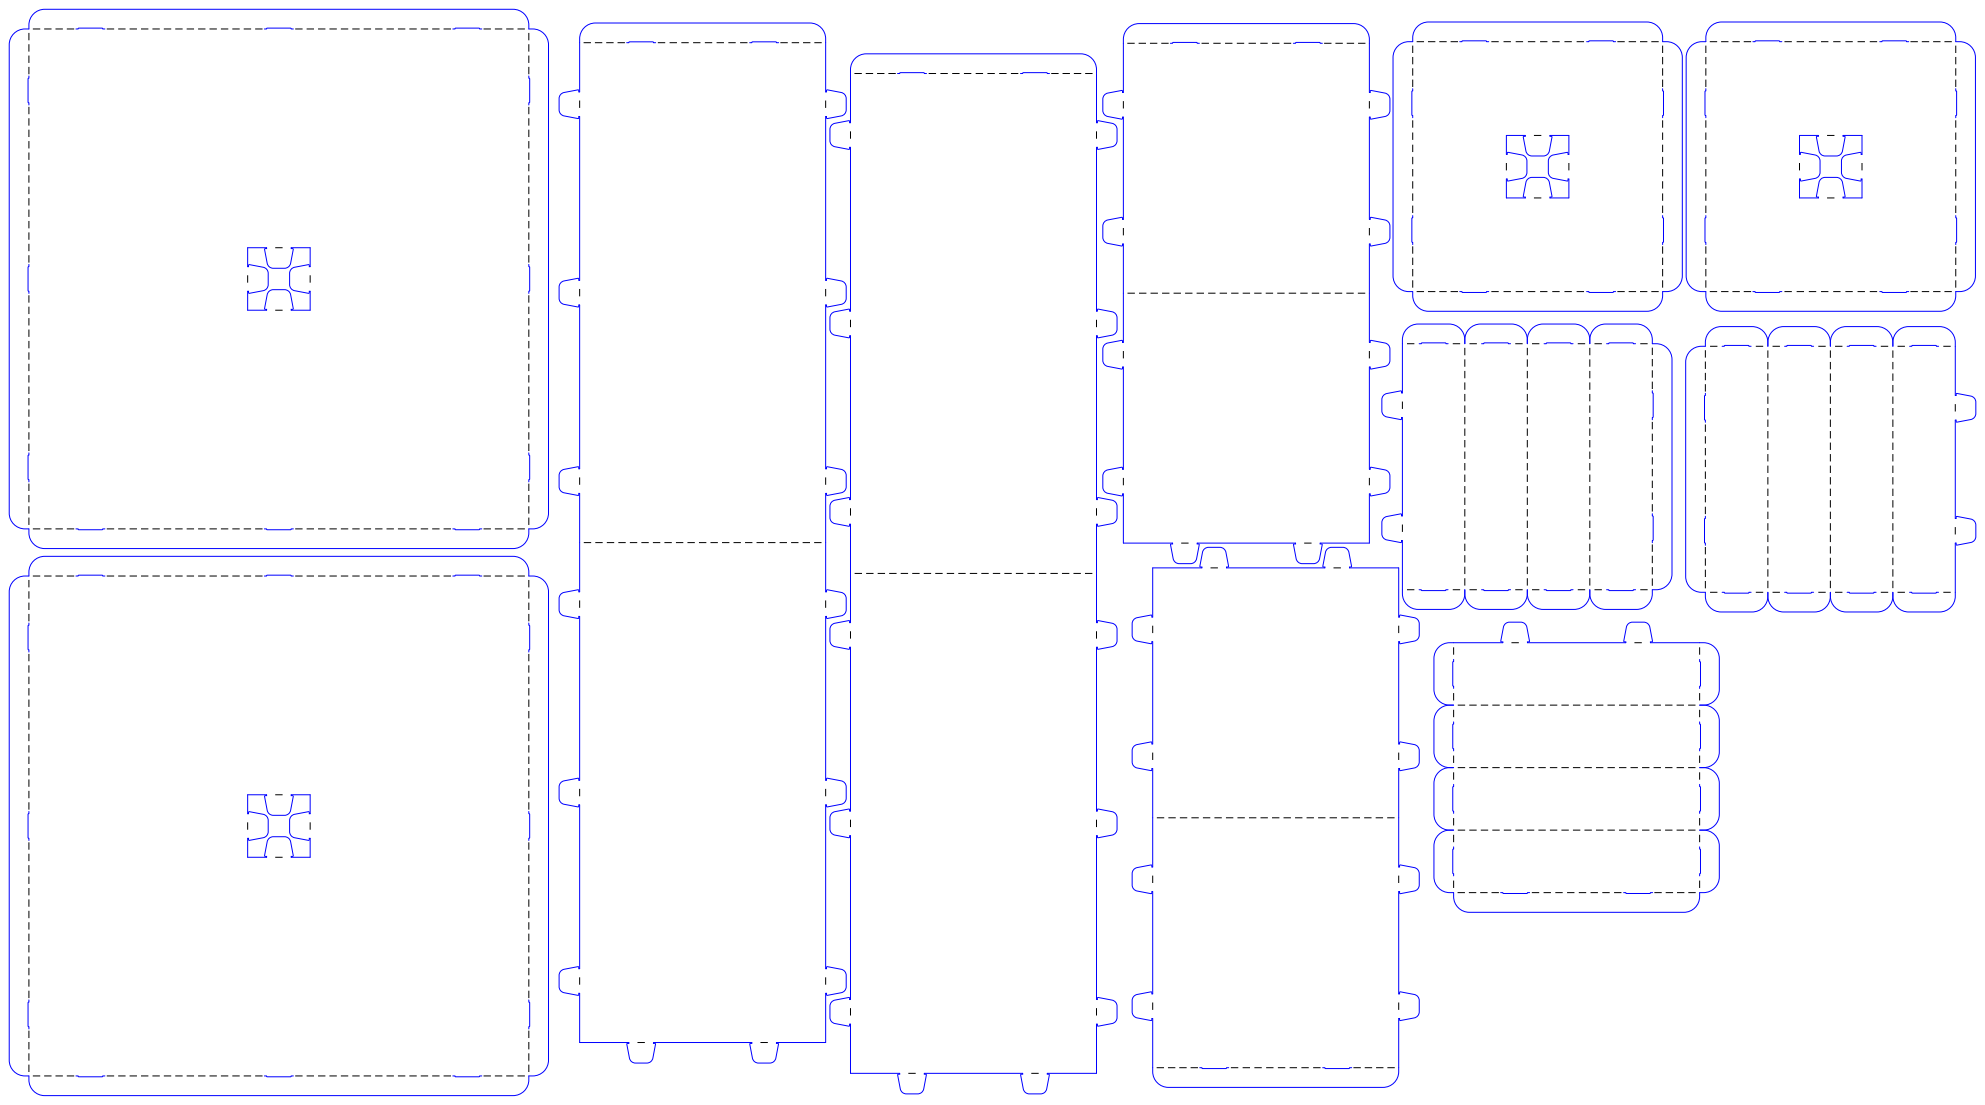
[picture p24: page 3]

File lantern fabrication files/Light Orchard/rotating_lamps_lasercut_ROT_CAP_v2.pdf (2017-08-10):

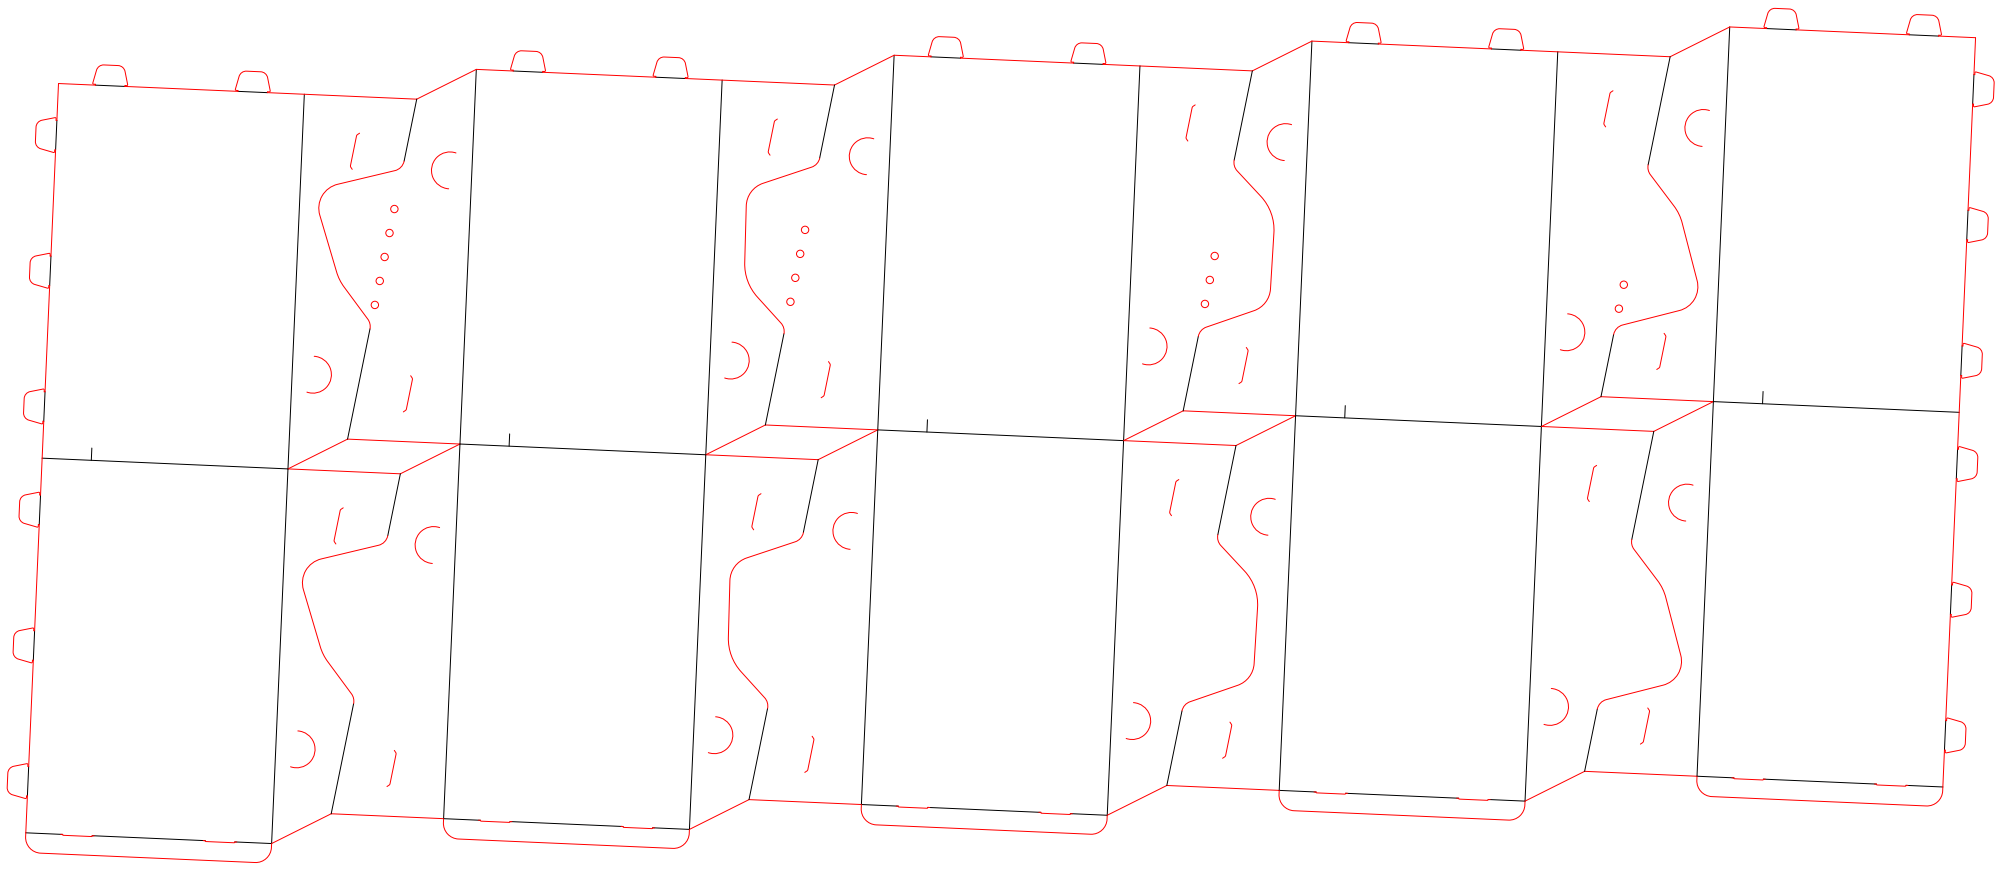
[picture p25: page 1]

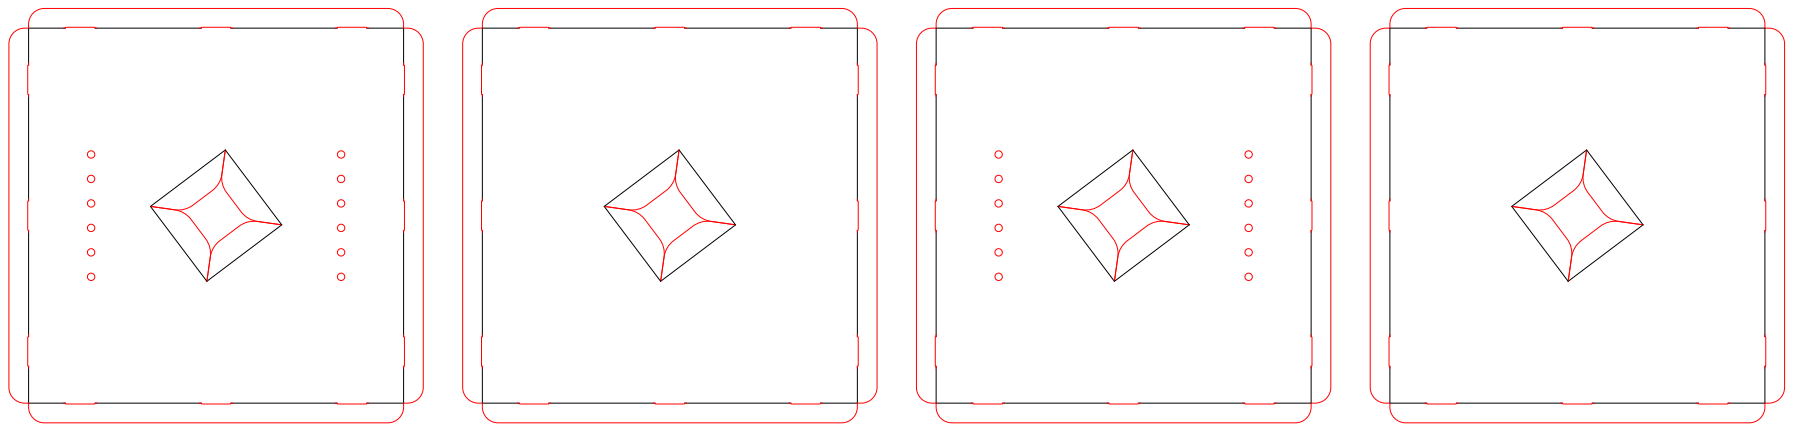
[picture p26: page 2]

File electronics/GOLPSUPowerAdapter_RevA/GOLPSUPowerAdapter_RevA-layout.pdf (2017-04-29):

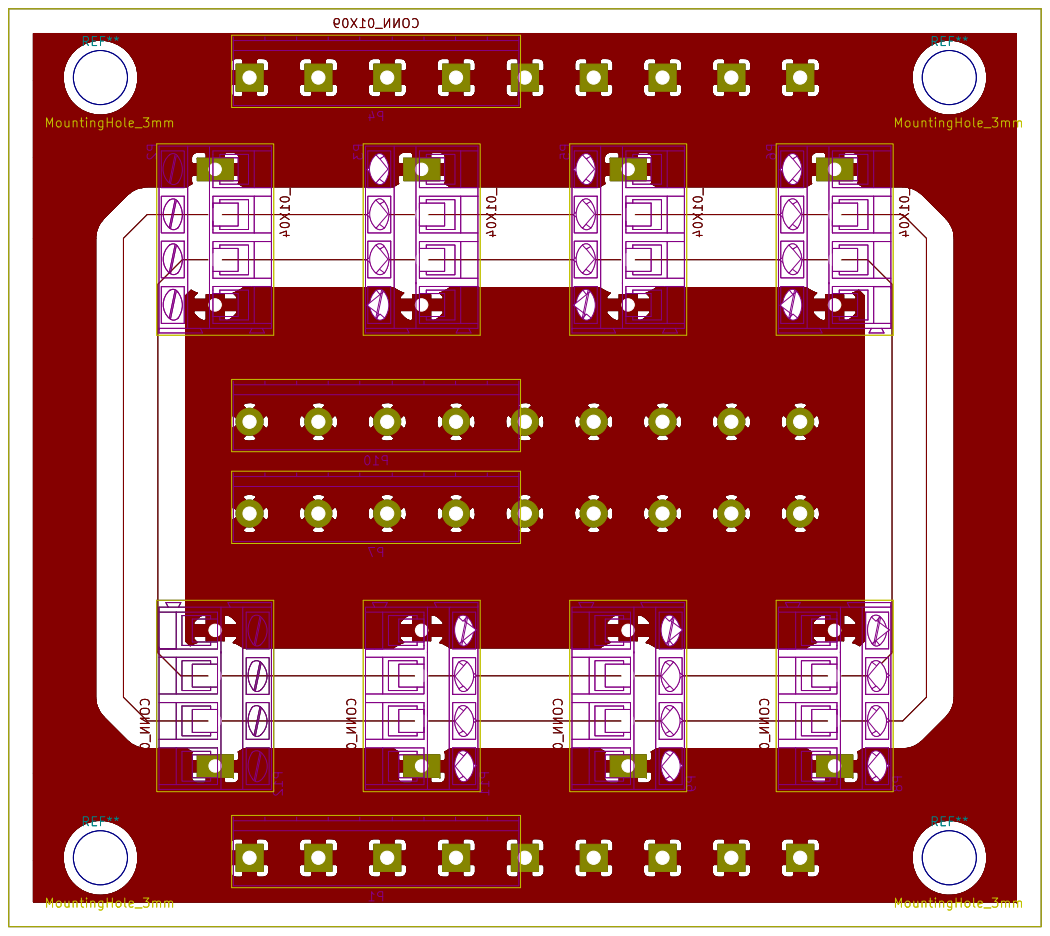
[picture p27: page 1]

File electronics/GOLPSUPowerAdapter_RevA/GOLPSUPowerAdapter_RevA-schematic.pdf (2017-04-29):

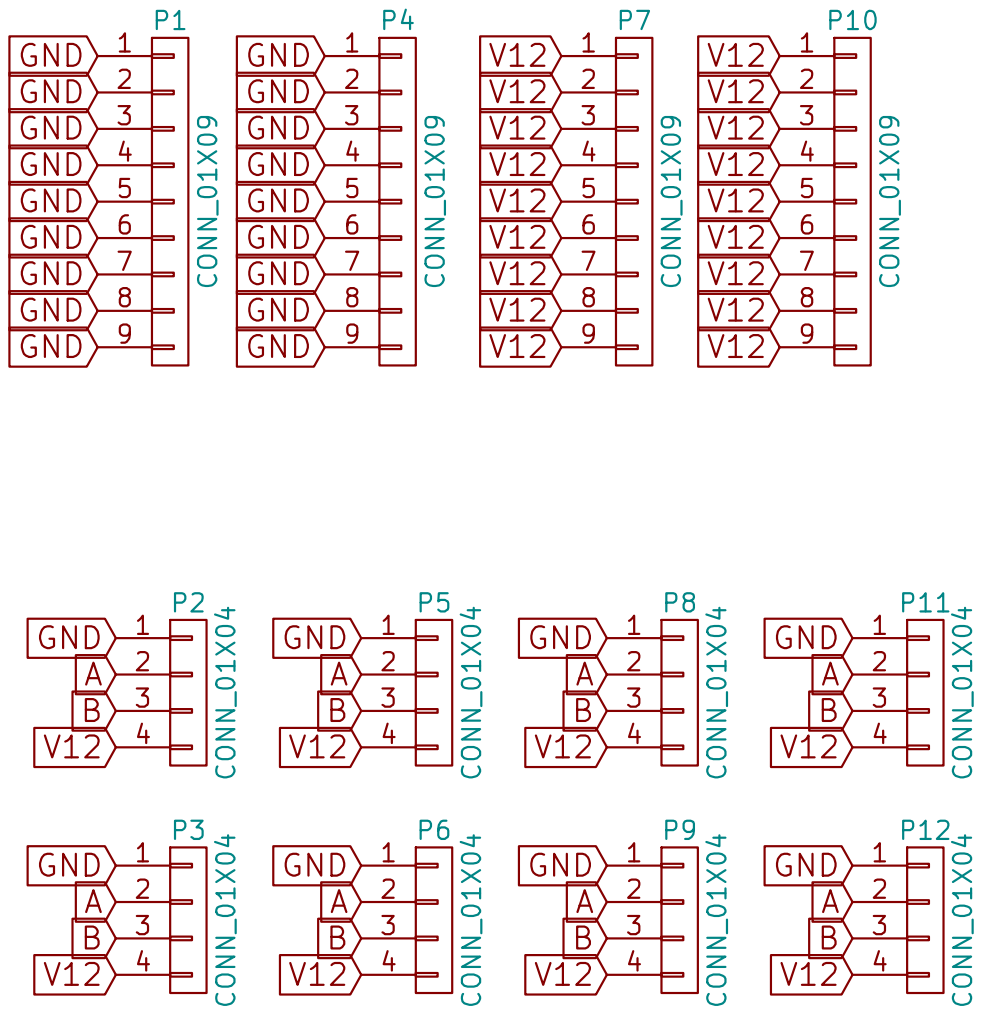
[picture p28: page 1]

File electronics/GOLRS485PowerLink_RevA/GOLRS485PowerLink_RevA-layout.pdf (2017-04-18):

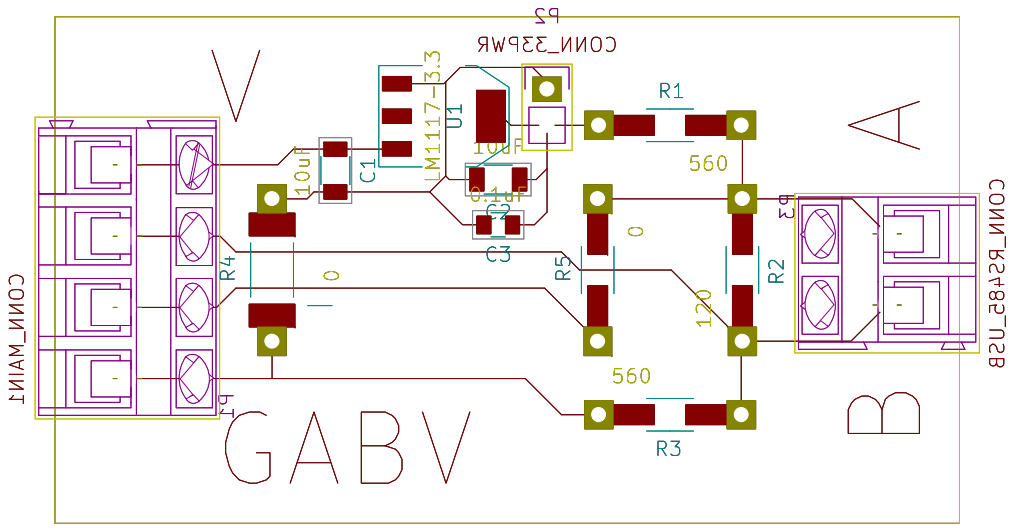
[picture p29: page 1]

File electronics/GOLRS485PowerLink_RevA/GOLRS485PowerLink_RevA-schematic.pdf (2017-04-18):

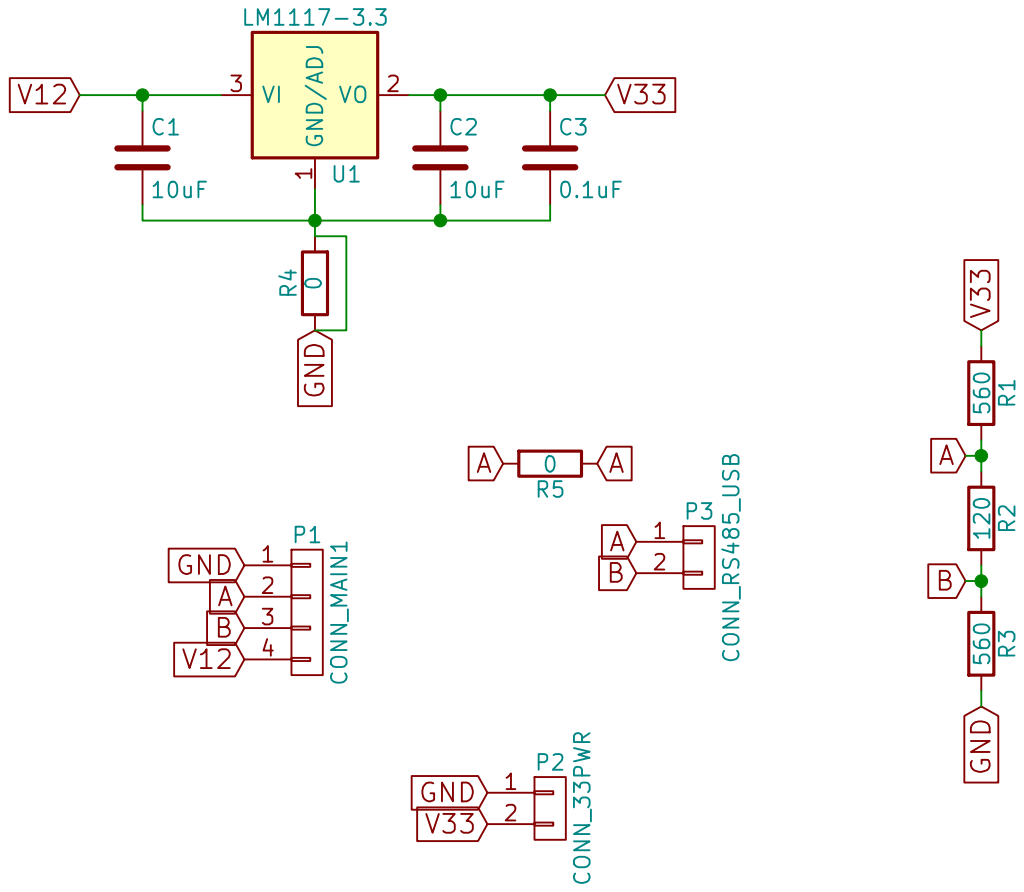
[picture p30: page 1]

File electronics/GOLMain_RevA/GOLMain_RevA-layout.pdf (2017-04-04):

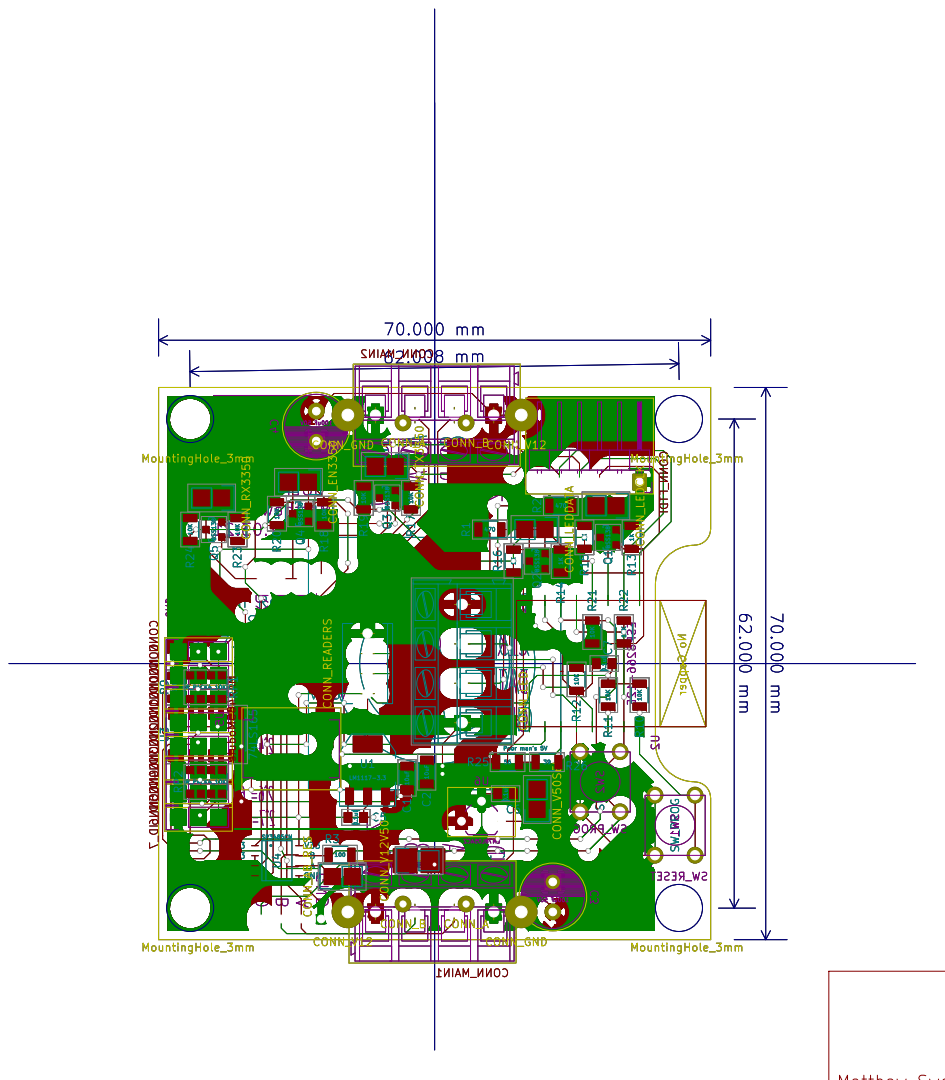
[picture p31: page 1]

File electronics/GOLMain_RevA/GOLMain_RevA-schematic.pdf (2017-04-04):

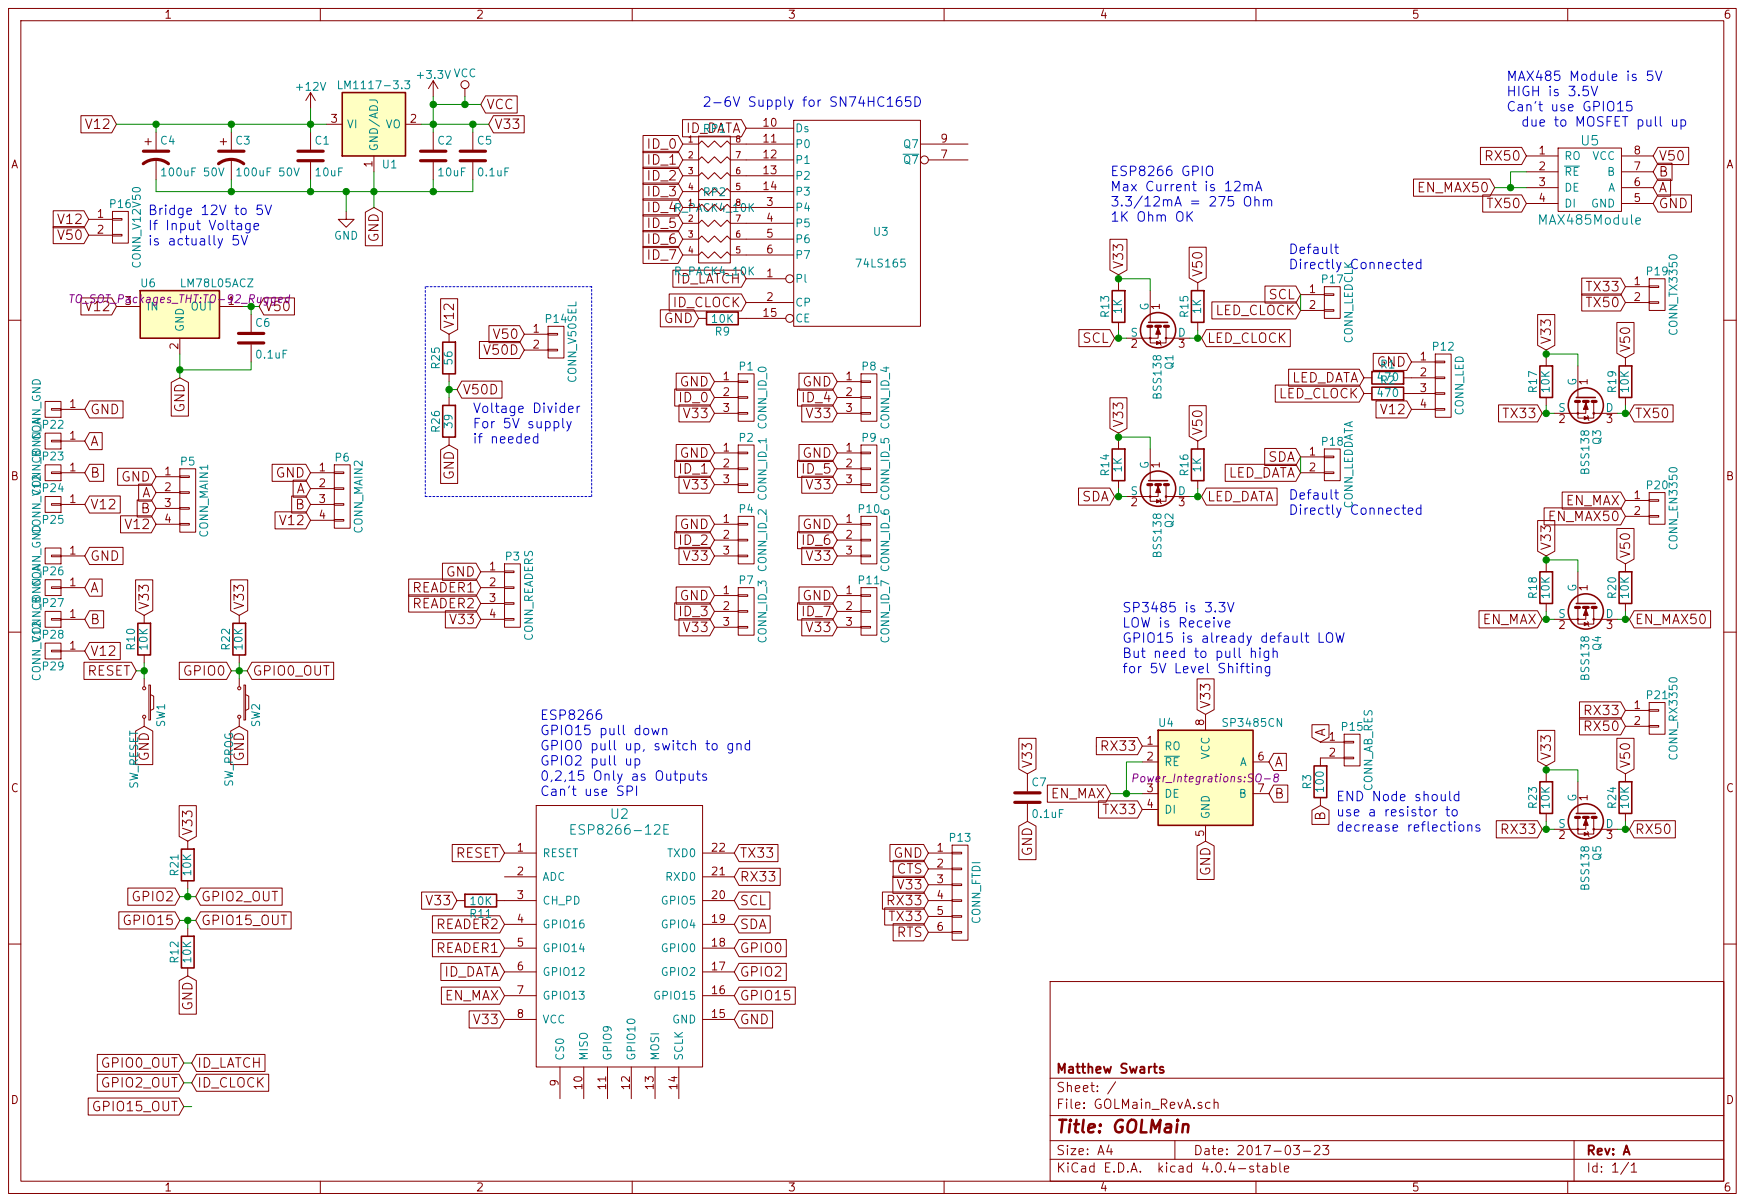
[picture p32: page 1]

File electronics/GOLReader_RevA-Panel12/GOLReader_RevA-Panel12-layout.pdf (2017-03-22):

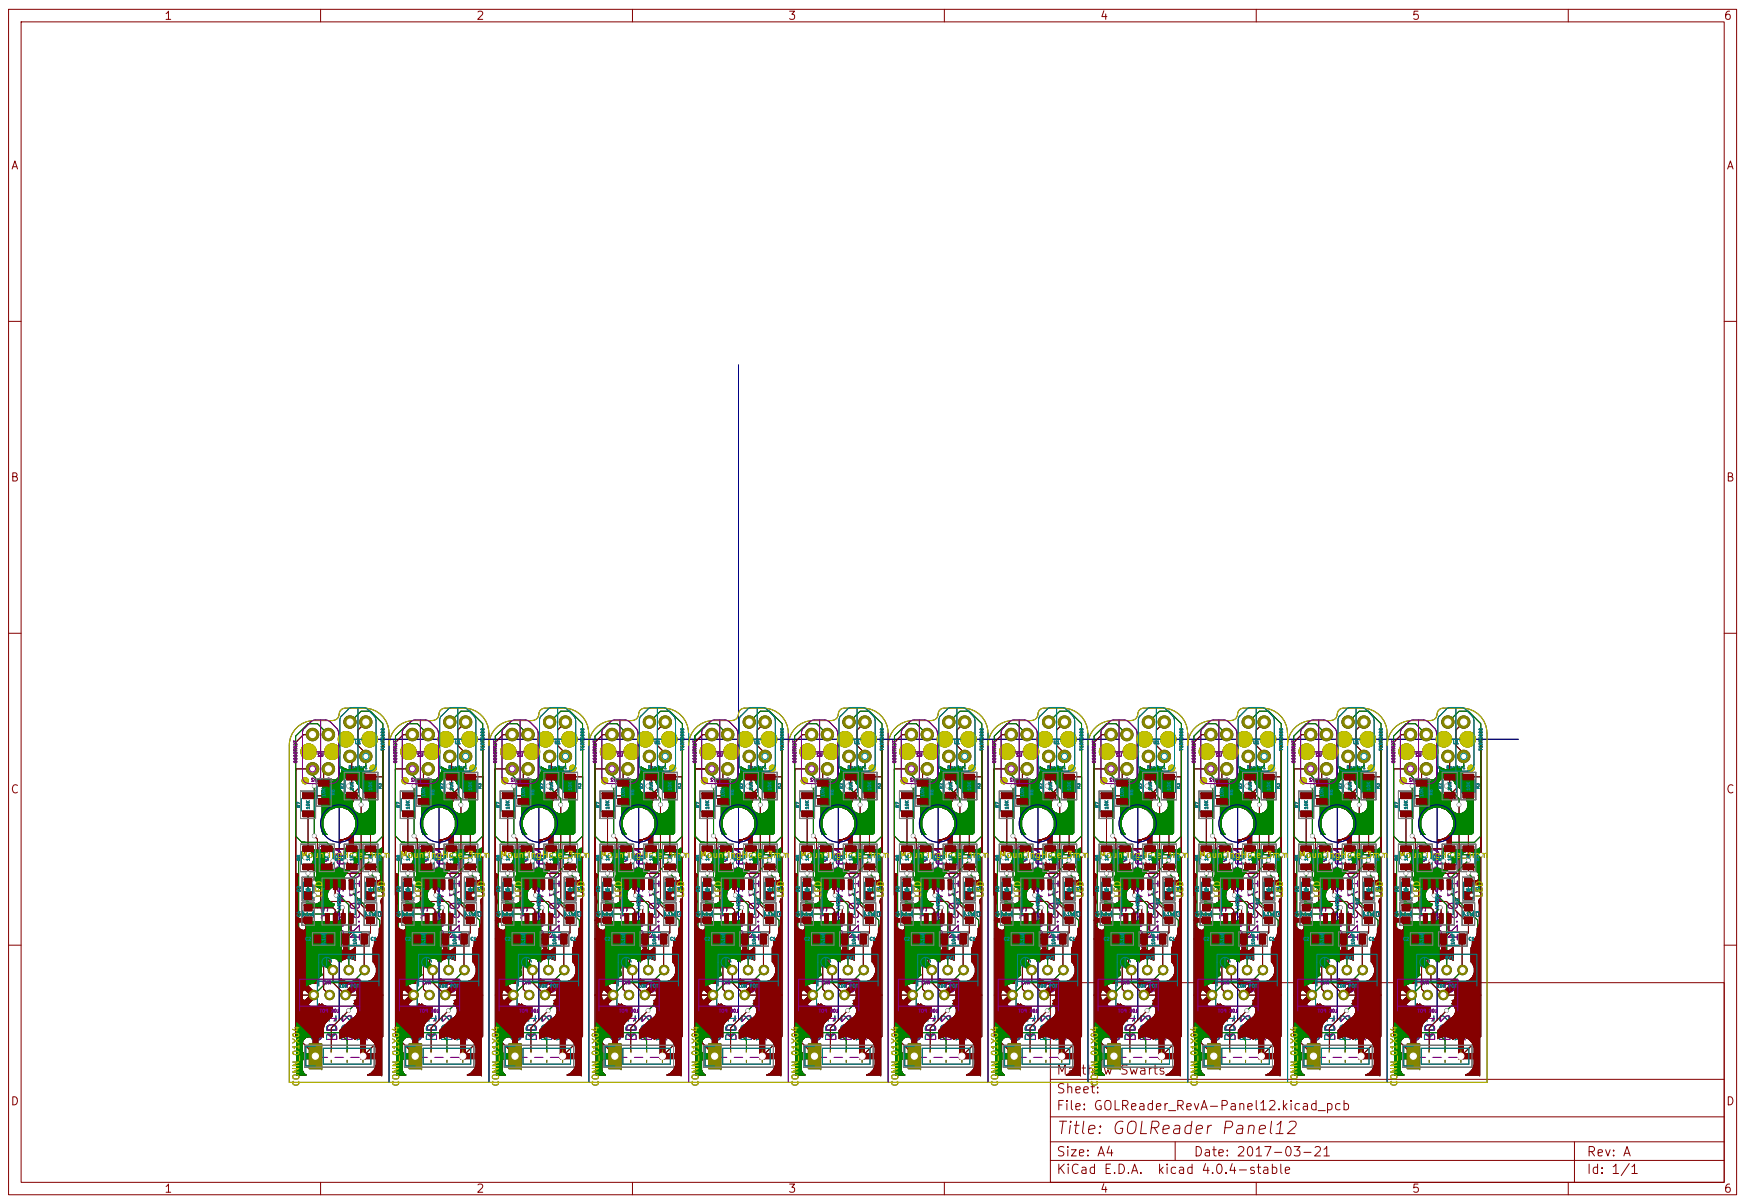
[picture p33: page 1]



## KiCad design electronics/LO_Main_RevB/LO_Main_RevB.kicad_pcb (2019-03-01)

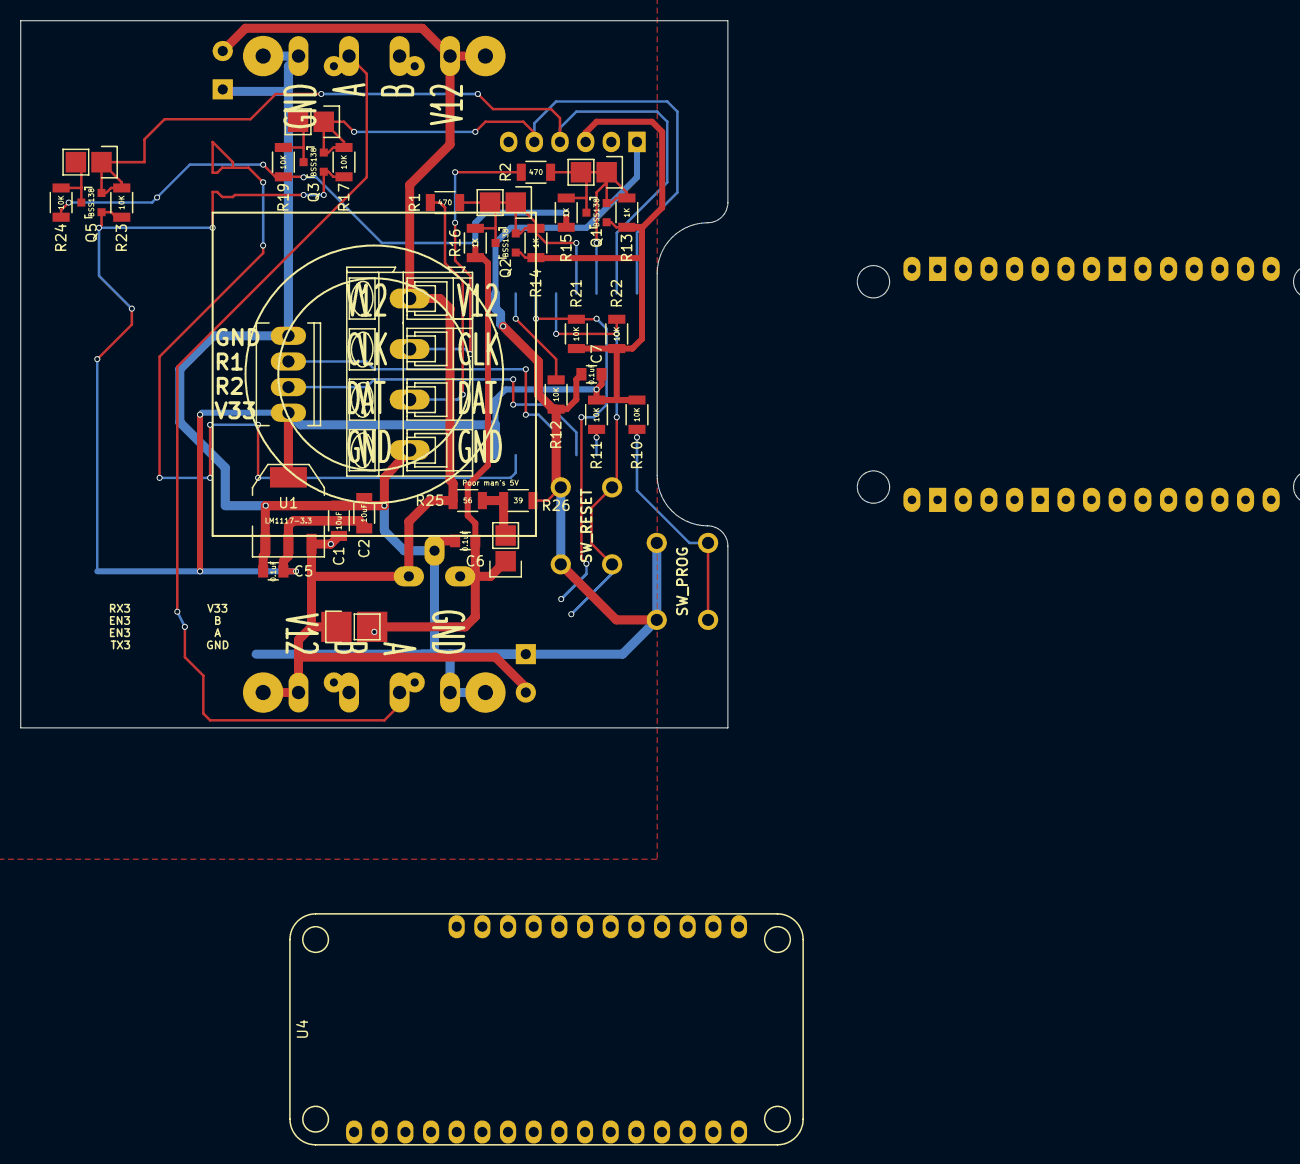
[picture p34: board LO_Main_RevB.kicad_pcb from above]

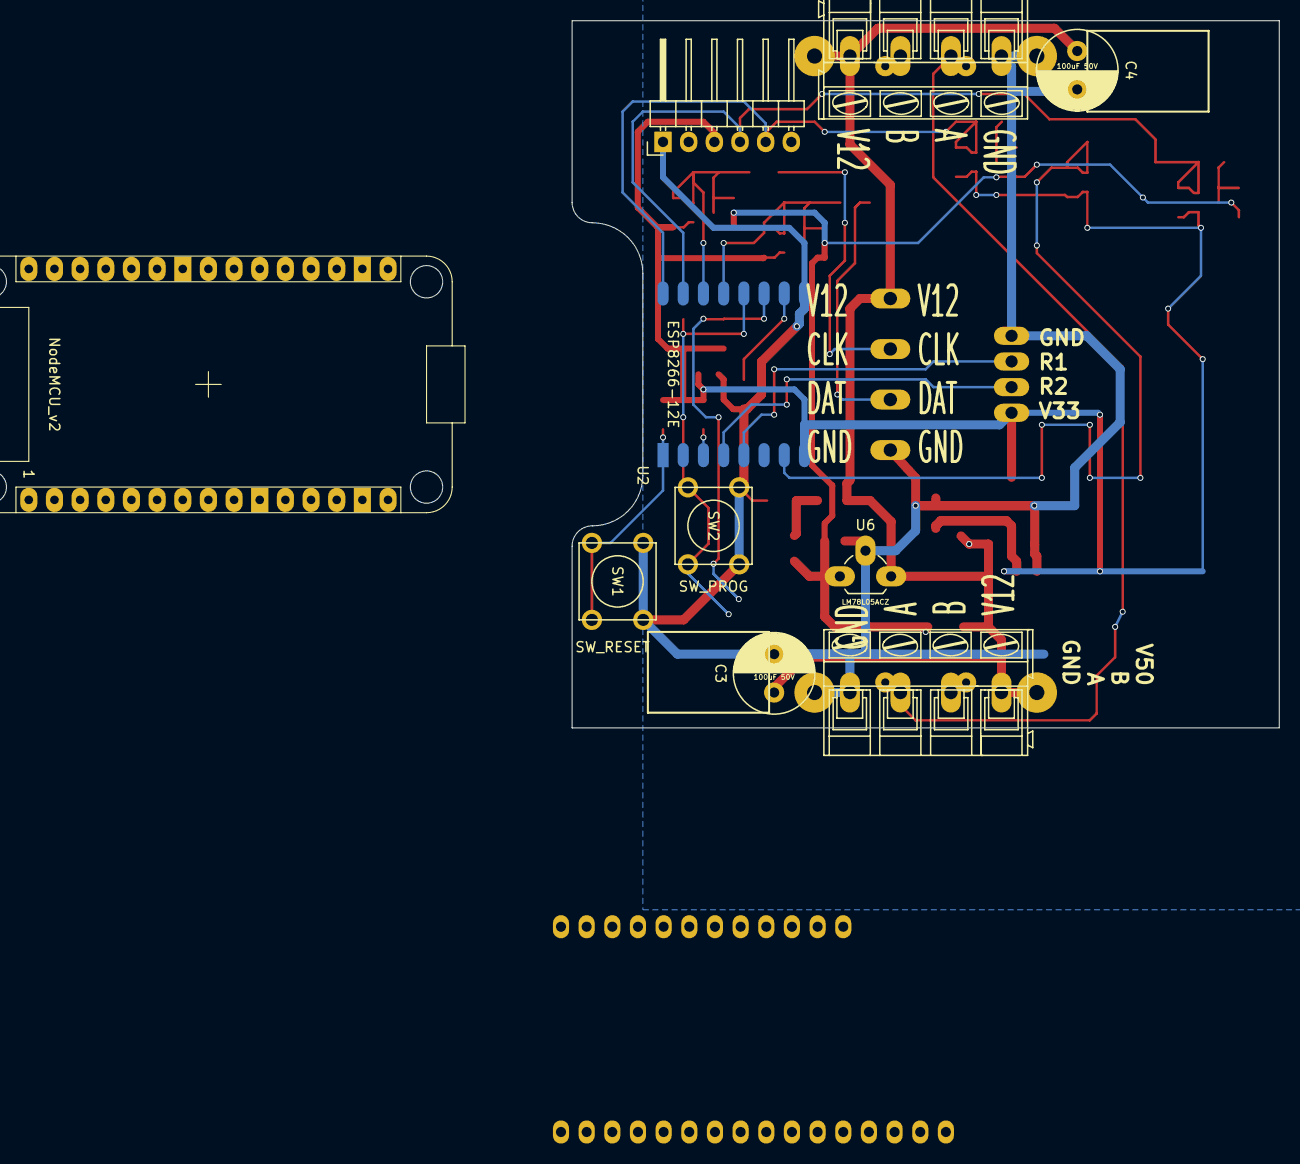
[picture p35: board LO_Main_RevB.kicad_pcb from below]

Board: 2 copper layers, 70.0 x 70.0 mm, 54 parts (10 on the bottom side), 20 nets.

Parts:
C1, C2: 10uF; C_1206
C3, C4: 100uF 50V; C_Radial_D8_L13_P3.8
C5, C6, C7: 0.1uF; C_0805
P3: CONN_READERS; Socket_MOLEX-KK-RM2-54mm_Lock_4pin_straight
P5: CONN_MAIN1; AK300-4
P6: CONN_MAIN2; AK300-4
P12: CONN_LED; AK300-4
P13: FTDI; Pin_Header_Angled_1x06
P14: CONN_V50SEL; Pin_Header_Straight_1x02
P16: CONN_V12V50; Pin_Header_Straight_1x02
P17: CONN_LEDCLK; Pin_Header_Straight_1x02
P18: CONN_LEDDATA; Pin_Header_Straight_1x02
P19: CONN_TX3350; Pin_Header_Straight_1x02
P21: CONN_RX3350; Pin_Header_Straight_1x02
P22, P26: CONN_GND; SolderWirePad_single_1-5mmDrill
P23, P27: CONN_A; SolderWirePad_single_0-8mmDrill
P24, P28: CONN_B; SolderWirePad_single_0-8mmDrill
P25, P29: CONN_V12; SolderWirePad_single_1-5mmDrill
Q1, Q2, Q3, Q5: BSS138; SOT-23
R1, R2: 470; R_1206
R10, R11, R12, R17, R19, R21, R22, R23, R24: 10K; R_1206
R13, R14, R15, R16: 1K; R_1206
R25: 56; R_1206
R26: 39; R_1206
SW1: SW_RESET; SW_PUSH_SMALL
SW2: SW_PROG; SW_PUSH_SMALL
U1: LM1117-3.3; SOT-223
U2: ESP8266-12E; ESP-12E
U3: NodeMCU_v2
U4: HUZZAH_Feather
U6: LM78L05ACZ; TO-92_Rugged

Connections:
GND: C1.2, C2.2, C3.2, C4.2, C5.2, C6.2, C7.2, P3.1, P5.1, P6.1, P12.1, P13.1, P22.1, P26.1, R12.1, R26.1, SW1.2, SW2.2, U1.1, U2.15, U6.2
GPIO0: R22.1, SW2.1, U2.18
GPIO2: R21.1, U2.17
GPIO15: R12.2, U2.16
LED_CLOCK: P17.1, P17.2, Q1.2, Q1.3, R2.1, R13.1, R15.1, U2.20
LED_DATA: P18.1, P18.2, Q2.2, Q2.3, R1.1, R14.1, R16.1, U2.19
unnamed: P12.2, R1.2
unnamed: P12.3, R2.2
unnamed: R11.1, U2.3
READER1: P3.2, U2.5
READER2: P3.3, U2.4
RESET: R10.1, SW1.1, U2.1
RX33: P13.4, P21.1, Q5.2, R23.1, U2.21
RX50: P21.2, Q5.3, R24.1
TX33: P13.5, P19.1, Q3.2, R17.1, U2.22
TX50: P19.2, Q3.3, R19.1
V12: C1.1, C3.1, C4.1, P5.4, P6.4, P12.4, P16.1, P25.1, P29.1, R25.2, U1.3, U6.3
V33: C2.1, C5.1, C7.1, P3.4, P13.3, Q1.1, Q2.1, Q3.1, Q5.1, R10.2, R11.2, R13.2, R14.2, R17.2, R21.2, R22.2, R23.2, U1.2, U1.4, U2.8
V50: C6.1, P14.1, P16.2, R15.2, R16.2, R19.2, R24.2, U6.1
V50D: P14.2, R25.1, R26.2

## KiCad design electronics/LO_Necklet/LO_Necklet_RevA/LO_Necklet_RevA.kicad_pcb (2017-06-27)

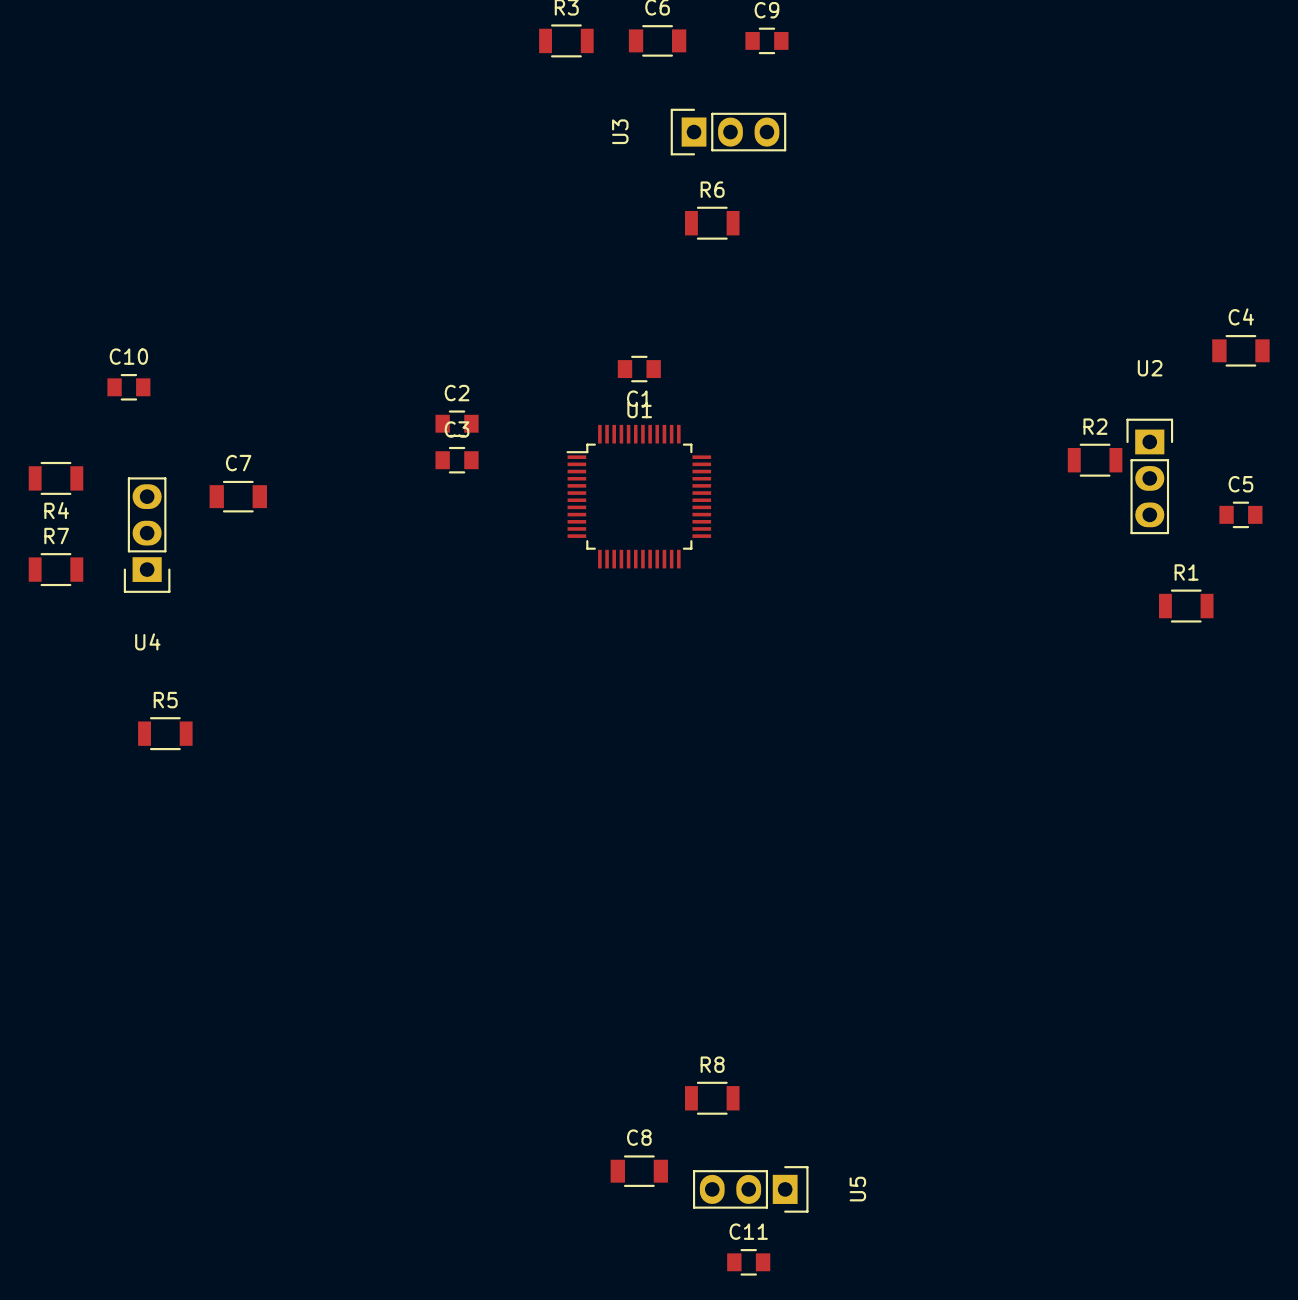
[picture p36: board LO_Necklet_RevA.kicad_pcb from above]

Board: 2 copper layers, 24 parts (0 on the bottom side), 13 nets, no tracks yet.

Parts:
C1: 1uF; C_0805
C2, C3: 22pF; C_0805
C4, C6, C7, C8: 100uF; C_1206
C5, C9, C10, C11: 0.1uF; C_0805
R1, R3, R4, R5: 100; R_1206
R2, R6, R7, R8: 10K; R_1206
U1: SAMD20G18A-A; TQFP-48_7x7mm_Pitch0.5mm
U2, U3, U4, U5: VS18388; Pin_Header_Straight_1x03

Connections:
GND: C1.1, C2.1, C3.1, C4.2, C5.2, C6.2, C7.2, C8.2, C9.2, C10.2, C11.2, U1.5, U1.18, U1.35, U1.42, U2.2, U3.2, U4.2, U5.2
IRIN1: R2.2, U2.1
IRIN2: R6.2, U3.1
IRIN3: R7.2, U4.1
IRIN4: R8.2, U5.1
unnamed: C1.2, U1.43
unnamed: C2.2, U1.1
unnamed: C3.2, U1.2
unnamed: C4.1, C5.1, R1.2, R2.1, U2.3
unnamed: C6.1, C9.1, R3.2, R6.1, U3.3
unnamed: C7.1, C10.1, R4.2, R7.1, U4.3
unnamed: C8.1, C11.1, R5.2, R8.1, U5.3
V33: R1.1, R3.1, R4.1, R5.1, U1.6, U1.17, U1.36, U1.44

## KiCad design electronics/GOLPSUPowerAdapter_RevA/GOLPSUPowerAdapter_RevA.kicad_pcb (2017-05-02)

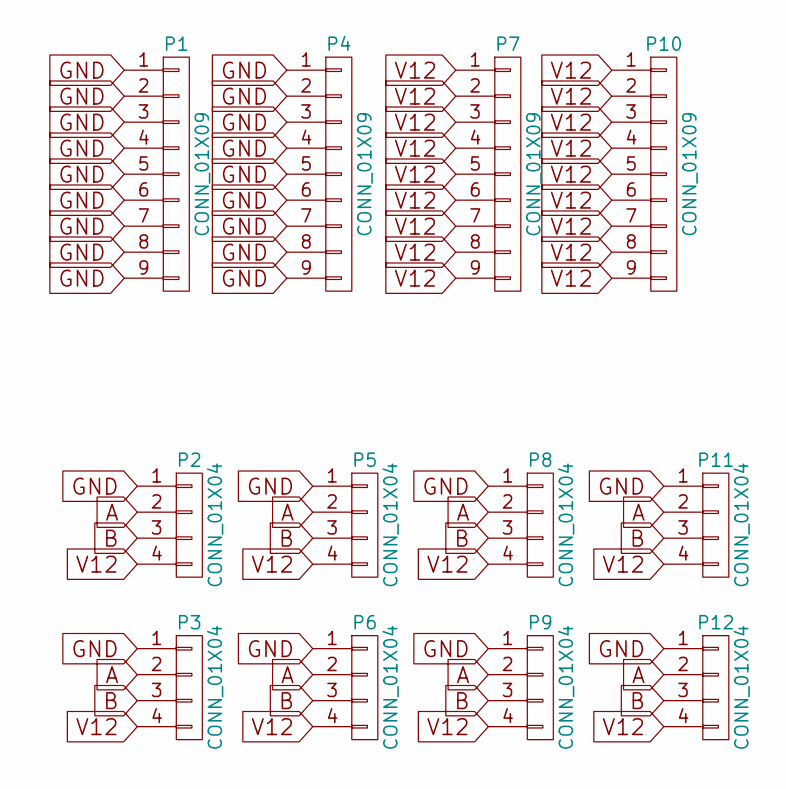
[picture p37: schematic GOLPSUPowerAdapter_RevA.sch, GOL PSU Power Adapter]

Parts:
P1, P4, P7, P10: CONN_01X09; TerminalBlock_Pheonix_PT-3.5mm_9pol
P2, P3, P5, P6, P8, P9, P11, P12: CONN_01X04; AK300-4

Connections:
A: P2.2, P3.2, P5.2, P6.2, P8.2, P9.2, P11.2, P12.2
B: P2.3, P3.3, P5.3, P6.3, P8.3, P9.3, P11.3, P12.3
GND: P1.1, P1.2, P1.3, P1.4, P1.5, P1.6, P1.7, P1.8, P1.9, P2.1, P3.1, P4.1, P4.2, P4.3, P4.4, P4.5, P4.6, P4.7, P4.8, P4.9, P5.1, P6.1, P8.1, P9.1, P11.1, P12.1
V12: P2.4, P3.4, P5.4, P6.4, P7.1, P7.2, P7.3, P7.4, P7.5, P7.6, P7.7, P7.8, P7.9, P8.4, P9.4, P10.1, P10.2, P10.3, P10.4, P10.5, P10.6, P10.7, P10.8, P10.9, P11.4, P12.4

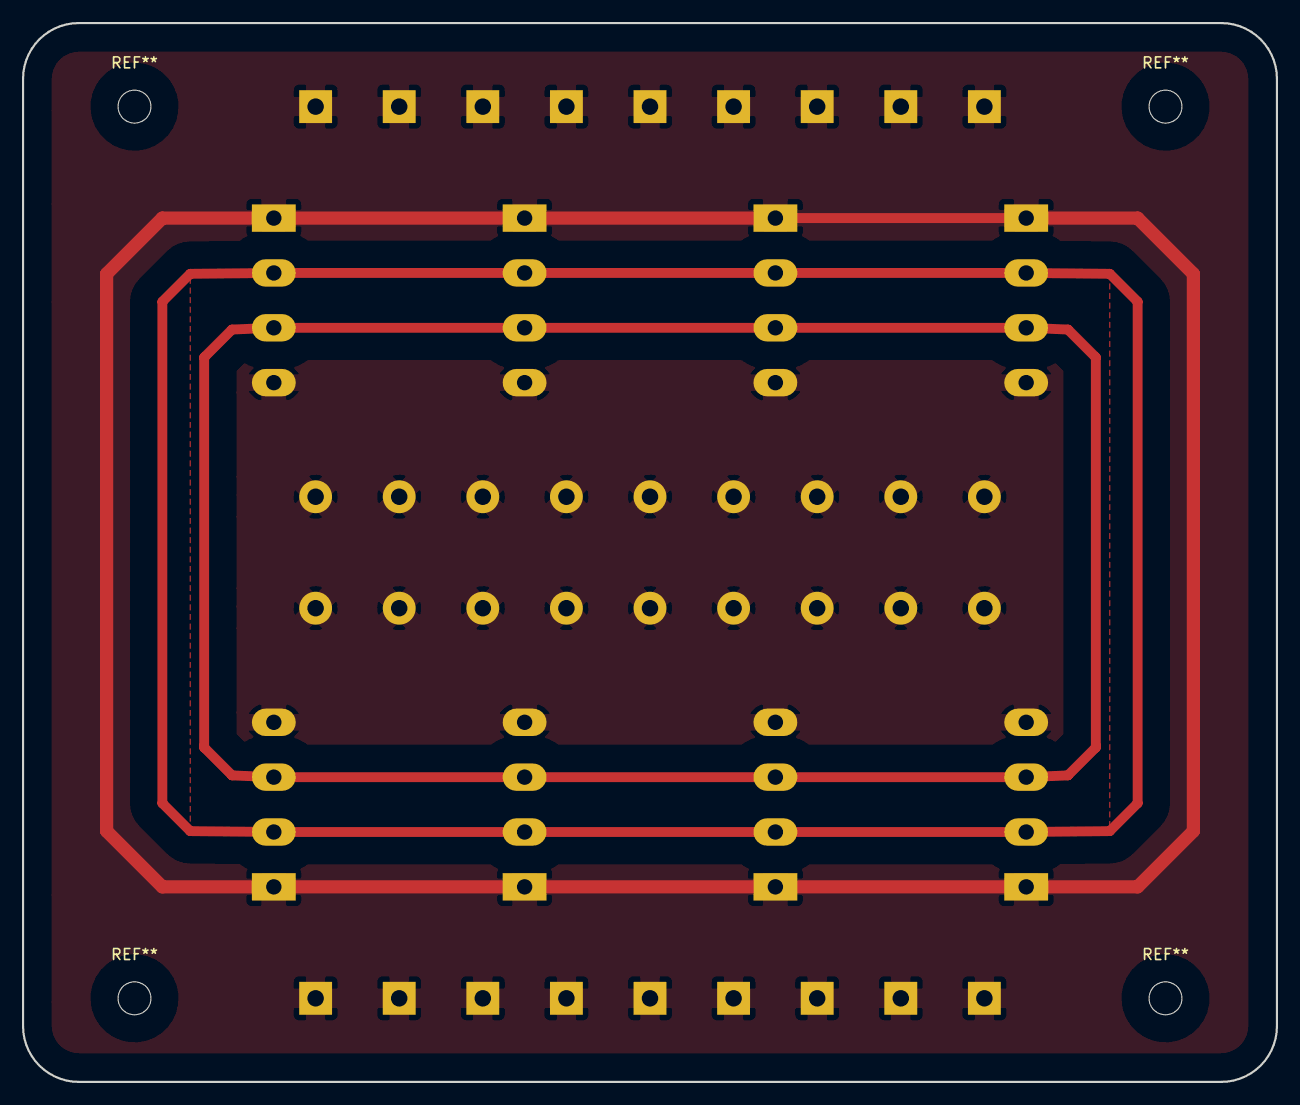
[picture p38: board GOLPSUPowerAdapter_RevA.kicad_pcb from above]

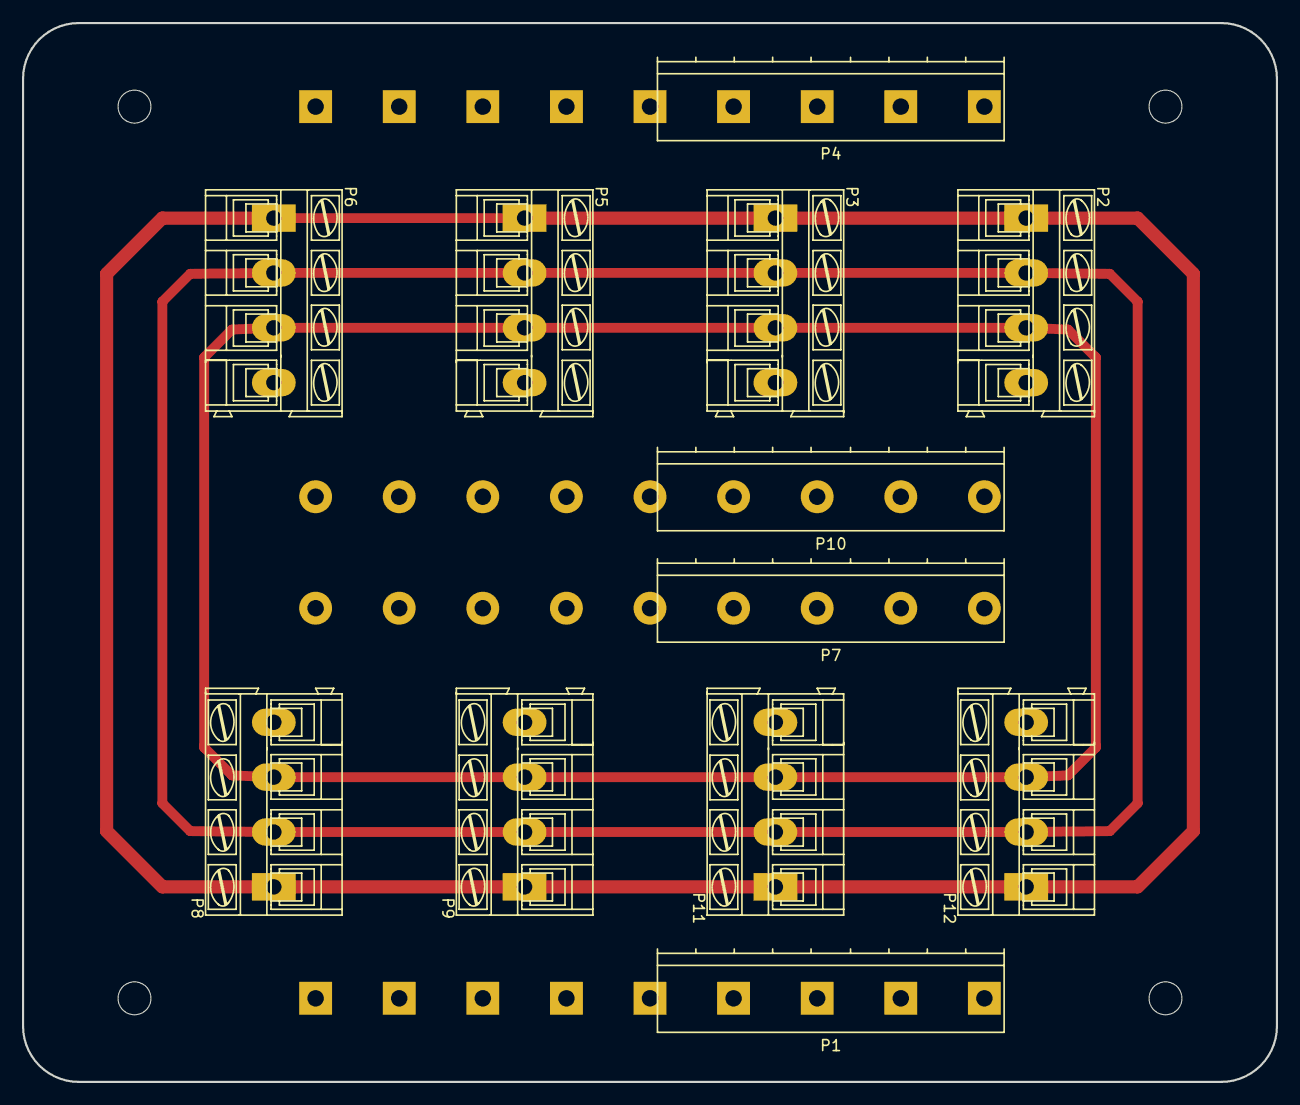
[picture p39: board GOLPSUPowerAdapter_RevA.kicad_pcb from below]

Board: 2 copper layers, 114.3 x 96.5 mm, 12 parts (12 on the bottom side), 4 nets.

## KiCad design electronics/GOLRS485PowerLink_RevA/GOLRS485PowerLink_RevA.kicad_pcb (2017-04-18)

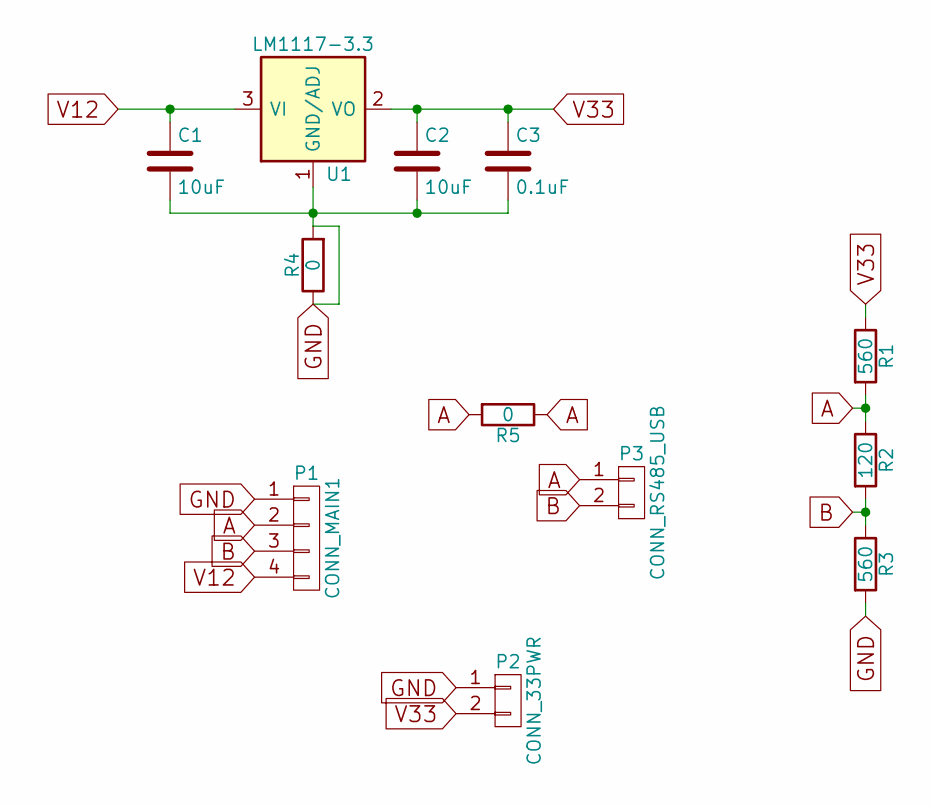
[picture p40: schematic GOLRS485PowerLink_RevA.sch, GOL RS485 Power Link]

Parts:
C1, C2: 10uF; C_1206
C3: 0.1uF; C_0805
P1: CONN_MAIN1; AK300-4
P2: CONN_33PWR; Pin_Header_Straight_1x02
P3: CONN_RS485_USB; AK300-2
R1, R3: 560; Resistor_SMD+THTuniversal_1206_RM10_HandSoldering
R2: 120; Resistor_SMD+THTuniversal_1206_RM10_HandSoldering
R4: 0; Resistor_SMD+THTuniversal_2512_RM10_HandSoldering
R5: 0; Resistor_SMD+THTuniversal_1206_RM10_HandSoldering
U1: LM1117-3.3; SOT-223

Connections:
A: P1.2, P3.1, R1.2, R2.1, R5.1, R5.2
B: P1.3, P3.2, R2.2, R3.1
GND: C1.2, C2.2, C3.2, P1.1, P2.1, R3.2, R4.1, R4.2, U1.1 (GND/ADJ)
V12: C1.1, P1.4, U1.3 (VI)
V33: C2.1, C3.1, P2.2, R1.1, U1.2 (VO), U1.4 (VO)

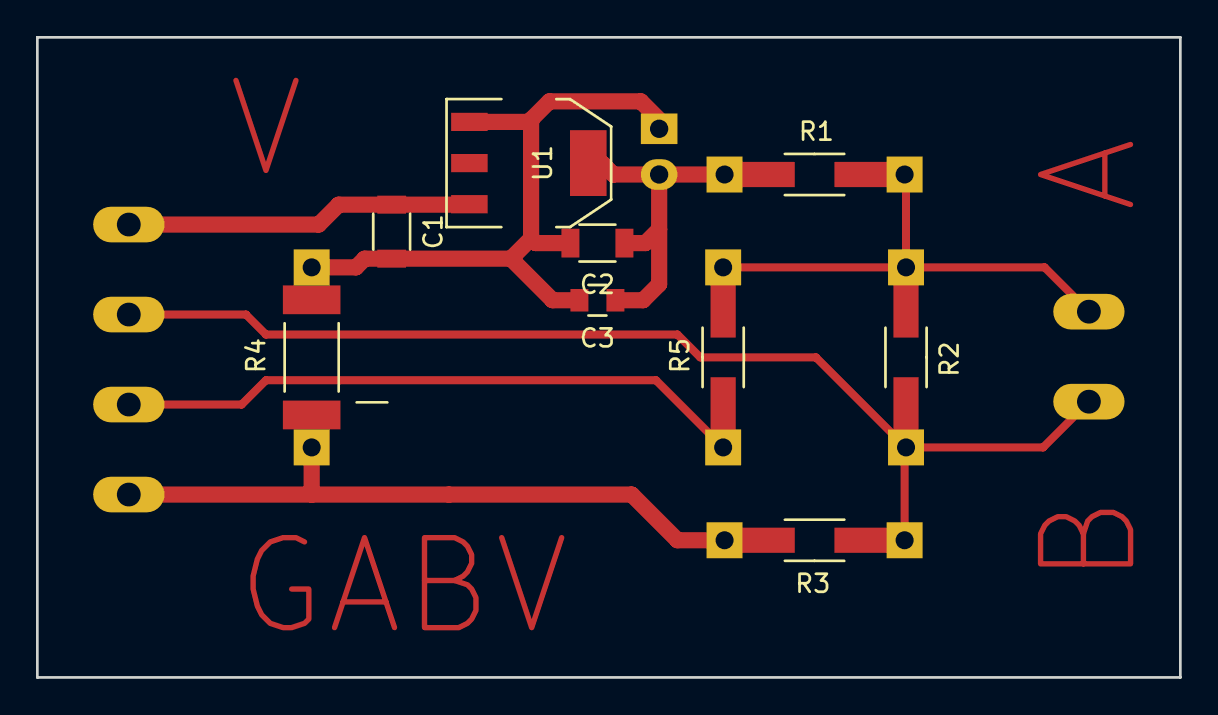
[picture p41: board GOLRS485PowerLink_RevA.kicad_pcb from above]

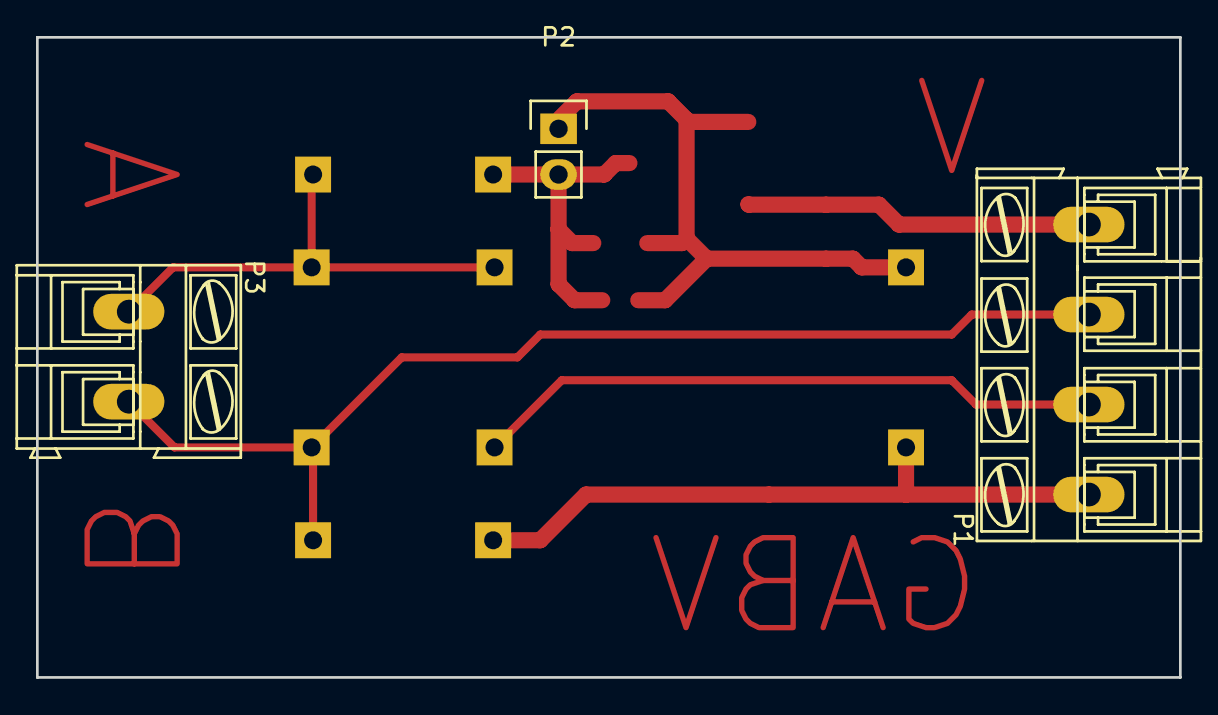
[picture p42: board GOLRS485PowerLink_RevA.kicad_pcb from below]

Board: 2 copper layers, 63.5 x 35.6 mm, 12 parts (3 on the bottom side), 5 nets.

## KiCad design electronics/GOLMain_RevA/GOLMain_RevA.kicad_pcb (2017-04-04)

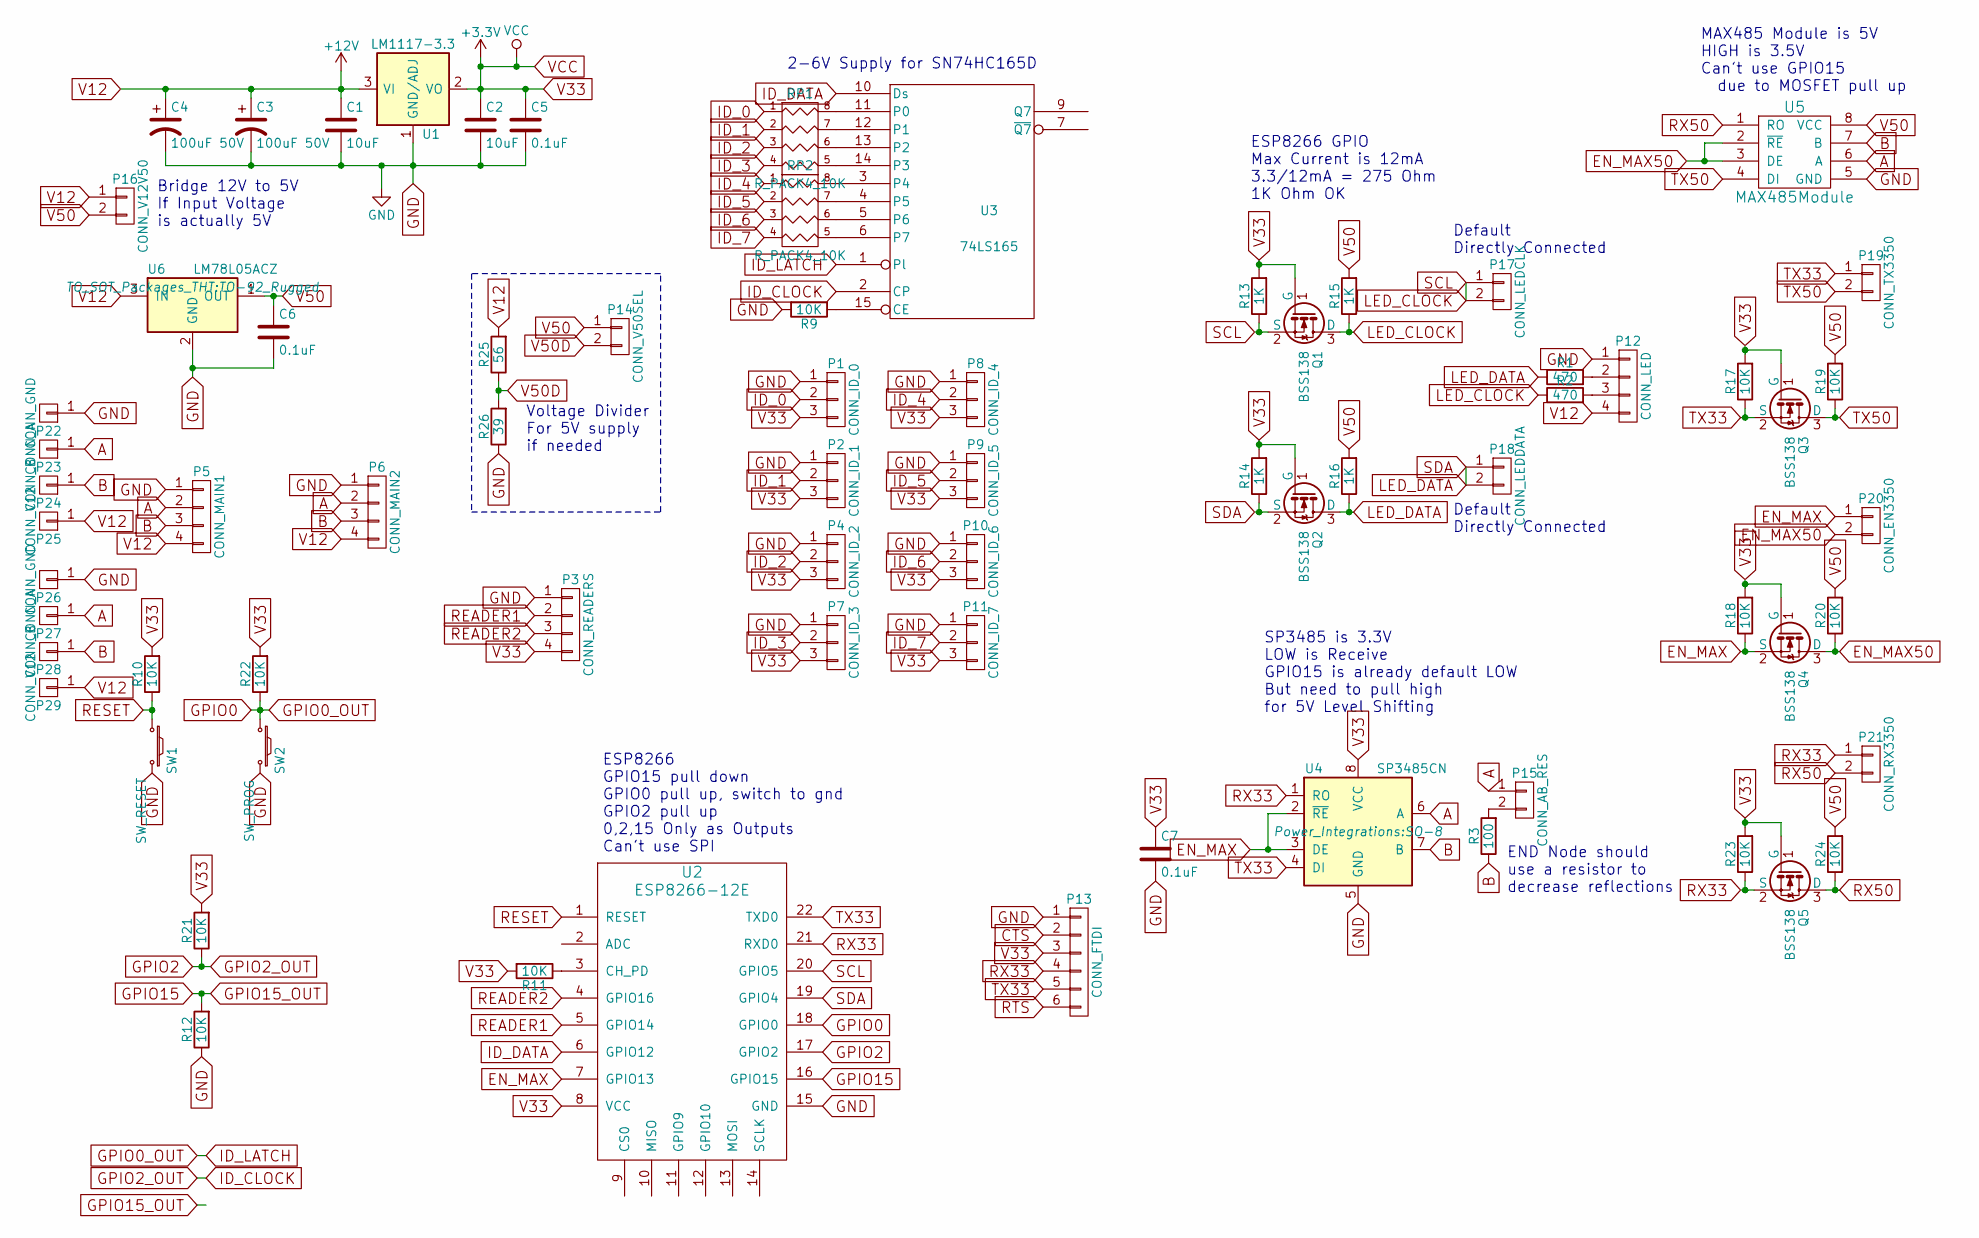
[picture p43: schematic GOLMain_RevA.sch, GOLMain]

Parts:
C1, C2: 10uF; C_1206
C3, C4: 100uF 50V; C_Radial_D8_L13_P3.8
C5, C6, C7: 0.1uF; C_0805
P1: CONN_ID_0; Pin_Header_Straight_1x03
P2: CONN_ID_1; Pin_Header_Straight_1x03
P3: CONN_READERS; Socket_MOLEX-KK-RM2-54mm_Lock_4pin_straight
P4: CONN_ID_2; Pin_Header_Straight_1x03
P5: CONN_MAIN1; AK300-4
P6: CONN_MAIN2; AK300-4
P7: CONN_ID_3; Pin_Header_Straight_1x03
P8: CONN_ID_4; Pin_Header_Straight_1x03
P9: CONN_ID_5; Pin_Header_Straight_1x03
P10: CONN_ID_6; Pin_Header_Straight_1x03
P11: CONN_ID_7; Pin_Header_Straight_1x03
P12: CONN_LED; AK300-4
P13: CONN_FTDI; Pin_Header_Angled_1x06
P14: CONN_V50SEL; Pin_Header_Straight_1x02
P15: CONN_AB_RES; Pin_Header_Straight_1x02
P16: CONN_V12V50; Pin_Header_Straight_1x02
P17: CONN_LEDCLK; Pin_Header_Straight_1x02
P18: CONN_LEDDATA; Pin_Header_Straight_1x02
P19: CONN_TX3350; Pin_Header_Straight_1x02
P20: CONN_EN3350; Pin_Header_Straight_1x02
P21: CONN_RX3350; Pin_Header_Straight_1x02
P22, P26: CONN_GND; SolderWirePad_single_1-5mmDrill
P23, P27: CONN_A; SolderWirePad_single_0-8mmDrill
P24, P28: CONN_B; SolderWirePad_single_0-8mmDrill
P25, P29: CONN_V12; SolderWirePad_single_1-5mmDrill
Q1, Q2, Q3, Q4, Q5: BSS138; SOT-23
R1, R2: 470; R_1206
R3: 100; R_1206
R9, R10, R11, R12, R17, R18, R19, R20, R21, R22, R23, R24: 10K; R_1206
R13, R14, R15, R16: 1K; R_1206
R25: 56; R_1206
R26: 39; R_1206
RP1, RP2: R_PACK4_10K; R_Array_Convex_4x1206
SW1: SW_RESET; SW_PUSH_SMALL
SW2: SW_PROG; SW_PUSH_SMALL
U1: LM1117-3.3; SOT-223
U2: ESP8266-12E; ESP-12E
U3: 74LS165; SOIC-16_3.9x9.9mm_Pitch1.27mm
U4: SP3485CN; SO-8
U5: MAX485Module; DIP-8_W7.62mm_LongPads
U6: LM78L05ACZ; TO-92_Rugged

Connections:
A: P5.2, P6.2, P15.1, P23.1, P27.1, U4.6 (A), U5.6 (A)
B: P5.3, P6.3, P24.1, P28.1, R3.1, U4.7 (B), U5.7 (B)
EN_MAX: P20.1, Q4.2 (S), R18.1, U2.7 (GPIO13), U4.2 (~RE~), U4.3 (DE)
EN_MAX50: P20.2, Q4.3 (D), R20.1, U5.2 (~RE), U5.3 (DE)
GND: C1.2, C2.2, C3.2, C4.2, C5.2, C6.2, C7.2, P1.1, P2.1, P3.1, P4.1, P5.1, P6.1, P7.1, P8.1, P9.1, P10.1, P11.1, P12.1, P13.1, P22.1, P26.1, R9.2, R12.1, R26.1, SW1.2, SW2.2, U1.1 (GND/ADJ), U2.15 (GND), U3.8 (GND), U4.5 (GND), U5.5 (GND), U6.2 (GND)
GPIO0: R22.1, SW2.1, U2.18 (GPIO0), U3.1 (Pl)
GPIO2: R21.1, U2.17 (GPIO2), U3.2 (CP)
GPIO15: R12.2, U2.16 (GPIO15)
ID_0: P1.2, RP1.1
ID_1: P2.2, RP1.2
ID_2: P4.2, RP1.3
ID_3: P7.2, RP1.4
ID_4: P8.2, RP2.1
ID_5: P9.2, RP2.2
ID_6: P10.2, RP2.3
ID_7: P11.2, RP2.4
ID_DATA: U2.6 (GPIO12), U3.10 (Ds)
LED_CLOCK: P17.1, P17.2, Q1.2 (S), Q1.3 (D), R2.1, R13.1, R15.1, U2.20 (GPIO5)
LED_DATA: P18.1, P18.2, Q2.2 (S), Q2.3 (D), R1.1, R14.1, R16.1, U2.19 (GPIO4)
unnamed: P12.2, R1.2
unnamed: P12.3, R2.2
unnamed: P15.2, R3.2
unnamed: R9.1, U3.15 (CE)
unnamed: R11.1, U2.3 (CH_PD)
unnamed: RP1.5 (R4), U3.14 (P3)
unnamed: RP1.6 (R3), U3.13 (P2)
unnamed: RP1.7 (R2), U3.12 (P1)
unnamed: RP1.8 (R1), U3.11 (P0)
unnamed: RP2.5 (R4), U3.6 (P7)
unnamed: RP2.6 (R3), U3.5 (P6)
unnamed: RP2.7 (R2), U3.4 (P5)
unnamed: RP2.8 (R1), U3.3 (P4)
READER1: P3.2, U2.5 (GPIO14)
READER2: P3.3, U2.4 (GPIO16)
RESET: R10.1, SW1.1, U2.1 (RESET)
RX33: P13.4, P21.1, Q5.2 (S), R23.1, U2.21 (RXD0), U4.1 (RO)
RX50: P21.2, Q5.3 (D), R24.1, U5.1 (RO)
TX33: P13.5, P19.1, Q3.2 (S), R17.1, U2.22 (TXD0), U4.4 (DI)
TX50: P19.2, Q3.3 (D), R19.1, U5.4 (DI)
V12: C1.1, C3.1, C4.1, P5.4, P6.4, P12.4, P16.1, P25.1, P29.1, R25.2, U1.3 (VI), U6.3 (IN)
V33: C2.1, C5.1, C7.1, P1.3, P2.3, P3.4, P4.3, P7.3, P8.3, P9.3, P10.3, P11.3, P13.3, Q1.1 (G), Q2.1 (G), Q3.1 (G), Q4.1 (G), Q5.1 (G), R10.2, R11.2, R13.2, R14.2, R17.2, R18.2, R21.2, R22.2, R23.2, U1.2 (VO), U1.4 (VO), U2.8 (VCC), U3.16 (VCC), U4.8 (VCC)
V50: C6.1, P14.1, P16.2, R15.2, R16.2, R19.2, R20.2, R24.2, U5.8 (VCC), U6.1 (OUT)
V50D: P14.2, R25.1, R26.2

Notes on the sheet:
2-6V Supply for SN74HC165D
ESP8266 GPIO15 pull down GPIO0 pull up, switch to gnd GPIO2 pull up 0,2,15 Only as Outputs Can't use SPI
SP3485 is 3.3V LOW is Receive GPIO15 is already default LOW But need to pull high for 5V Level Shifting
MAX485 Module is 5V HIGH is 3.5V Can't use GPIO15 due to MOSFET pull up
Voltage Divider For 5V supply if needed
ESP8266 GPIO Max Current is 12mA 3.3/12mA = 275 Ohm 1K Ohm OK
Bridge 12V to 5V If Input Voltage is actually 5V
END Node should use a resistor to decrease reflections
Default Directly Connected

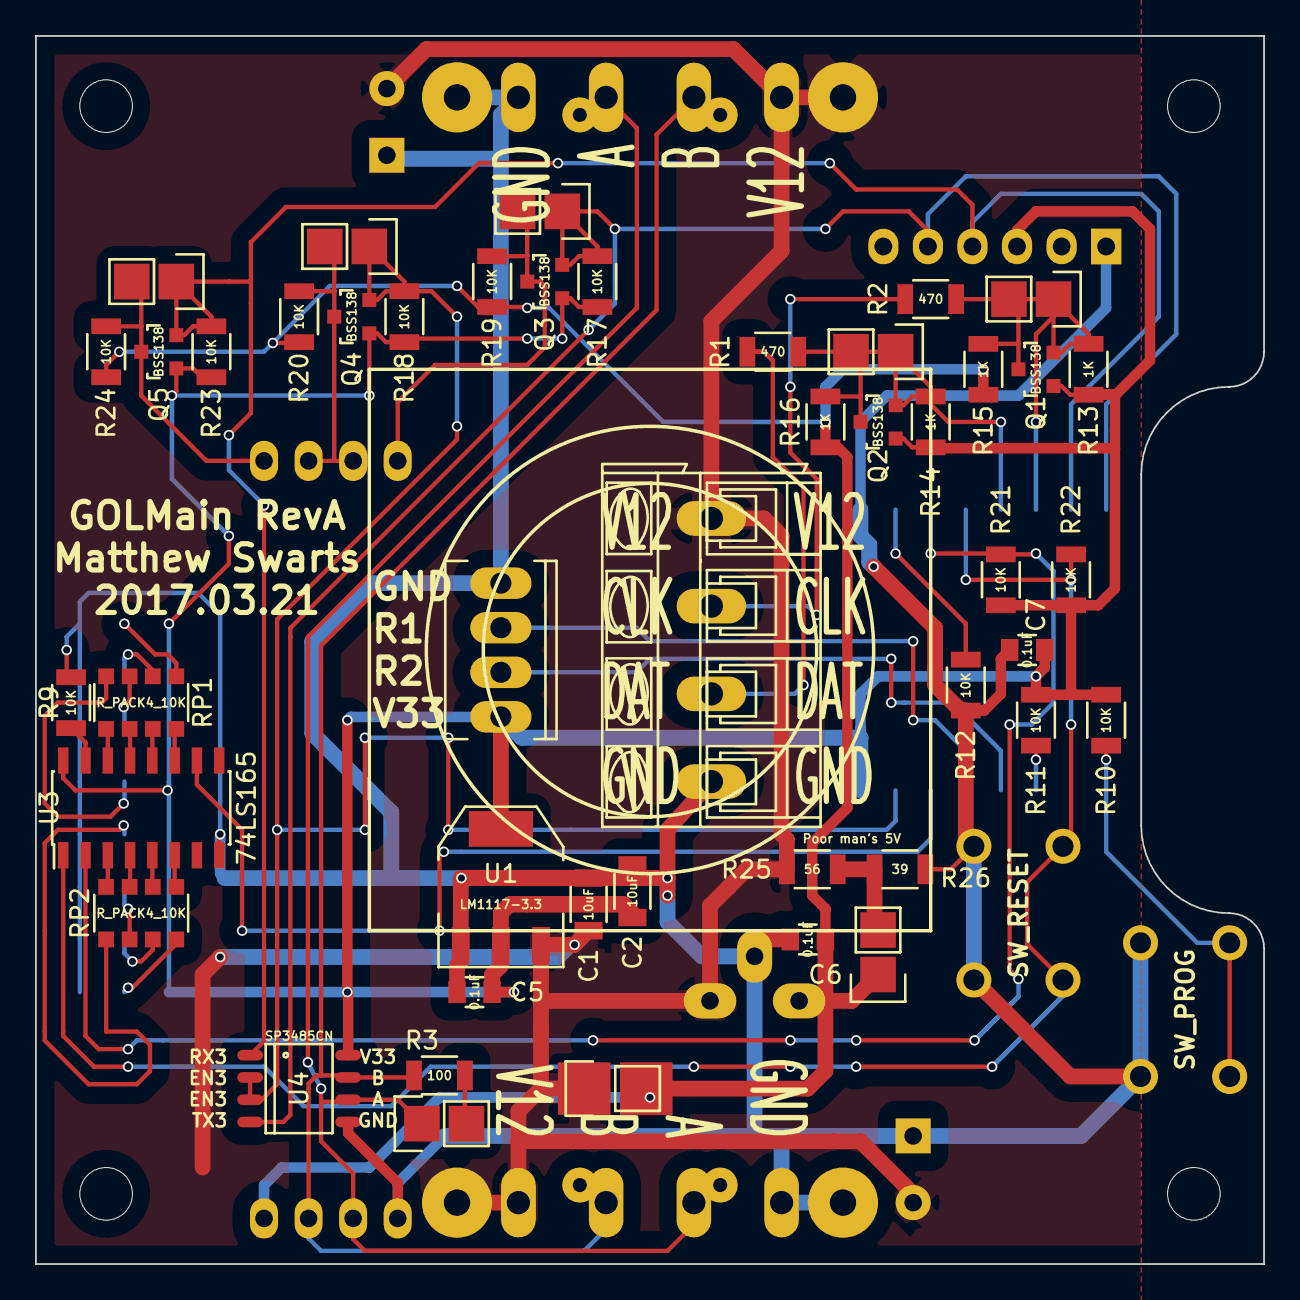
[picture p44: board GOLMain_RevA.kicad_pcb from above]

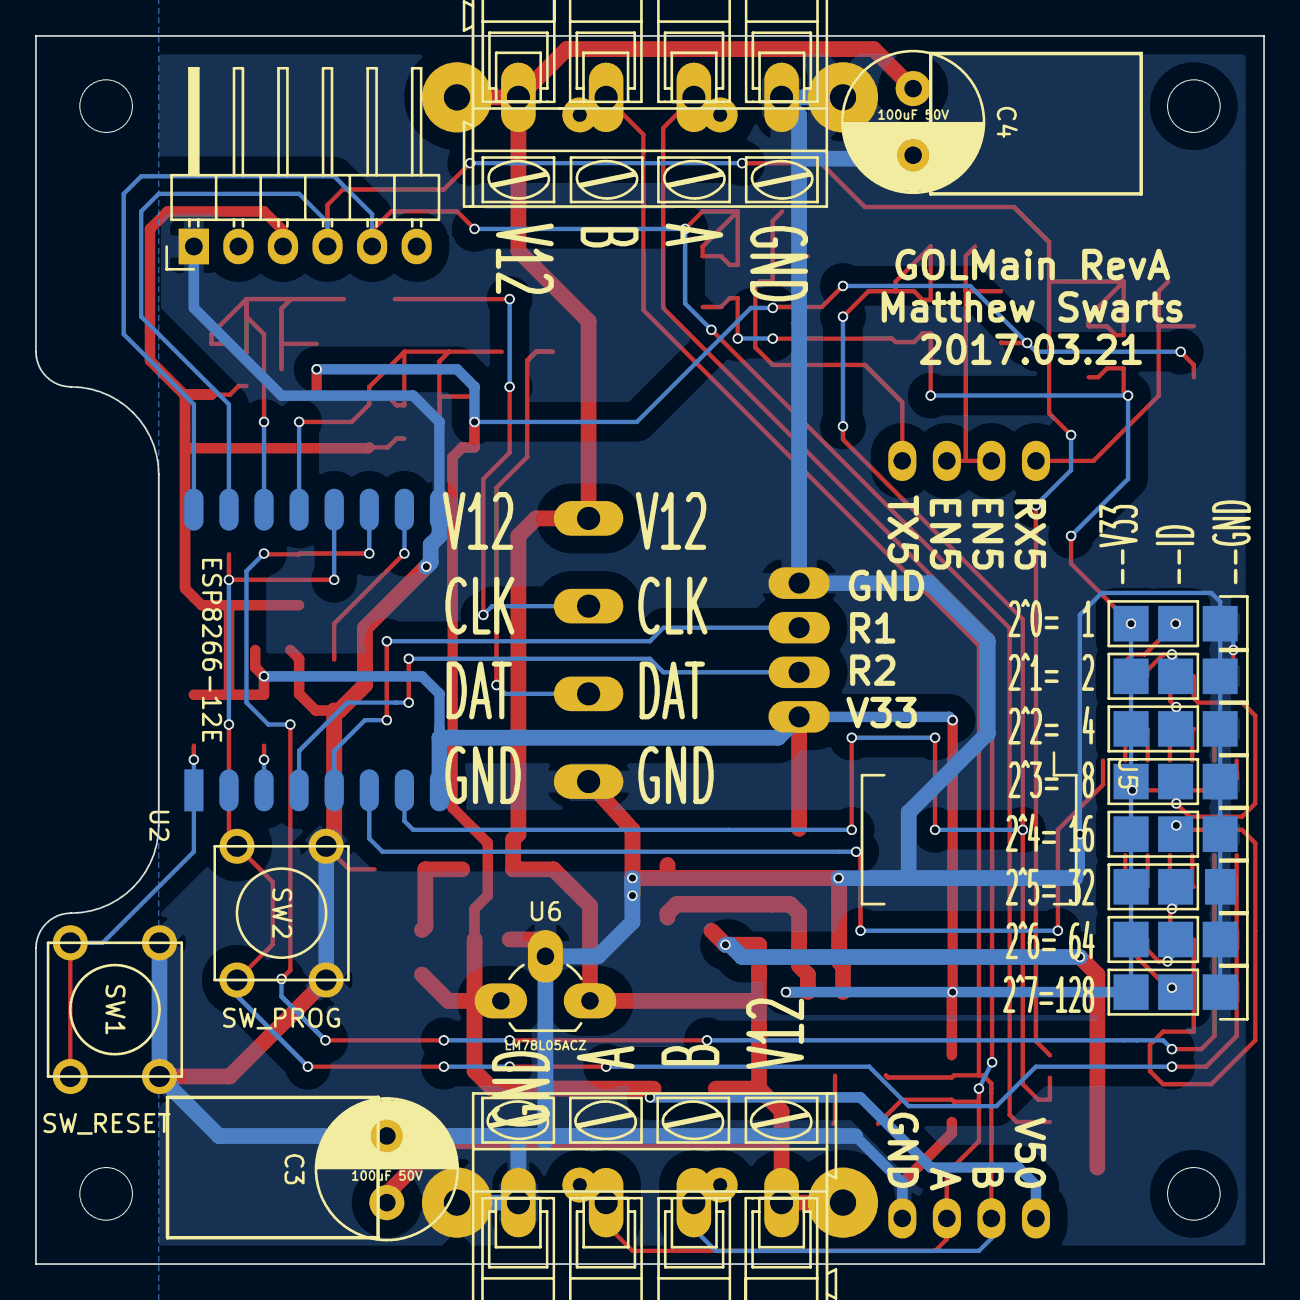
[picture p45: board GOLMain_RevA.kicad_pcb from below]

Board: 2 copper layers, 70.0 x 70.0 mm, 72 parts (18 on the bottom side), 43 nets.

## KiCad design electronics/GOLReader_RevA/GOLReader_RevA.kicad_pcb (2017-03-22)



Board: 2 copper layers, 16.0 x 60.0 mm, 20 parts (2 on the bottom side), 12 nets.

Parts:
C1: 10uF; C_1206
C2, C3, C4: 0.1uF; C_0805
D1, D2: LED; LED-0805
P1: CONN_01X04; Pin_Header_Straight_1x04
R1, R4, R5, R8: 1K; R_1206
R2, R3, R6, R7: 10K; R_1206
RV1, RV2: 10K POT; Potentiometer_Bourns_3296W_3-8Zoll_Inline_ScrewUp
U1, U2: TCRT5000
U3: LM393; SOIC-8_3.9x4.9mm_Pitch1.27mm

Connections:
GND: C1.2, C2.2, C3.2, C4.2, P1.1, RV1.3, RV2.3, U1.2, U1.3, U2.2, U2.3, U3.4
unnamed: C3.1, R2.2, U1.4, U3.2
unnamed: C4.1, R6.2, U2.4, U3.6
unnamed: D1.1, R4.1
unnamed: D2.1, R8.1
unnamed: R1.2, U1.1
unnamed: R5.2, U2.1
unnamed: RV1.2, U3.3
unnamed: RV2.2, U3.5
READER1: P1.2, R3.2, R4.2, U3.1
READER2: P1.3, R7.2, R8.2, U3.7
V33: C1.1, C2.1, D1.2, D2.2, P1.4, R1.1, R2.1, R3.1, R5.1, R6.1, R7.1, RV1.1, RV2.1, U3.8

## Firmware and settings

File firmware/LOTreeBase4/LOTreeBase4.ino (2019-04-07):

///////////////////////////////////////////////////////////////////////////////////////////////////
//***use Flash size 4MB (1M SPIFFS)
///////////////////////////////////////////////////////////////////////////////////////////////////
//Flash real id:   001640EF
///////////////////////////////////////////////////////////////////////////////////////////////////
//Flash real size: 4194304
///////////////////////////////////////////////////////////////////////////////////////////////////
//Using Arduino ESP8266 Library version 2.5
///////////////////////////////////////////////////////////////////////////////////////////////////

const char* baseVersion = "4026";

#include <EEPROM.h>
#include <ESP8266WiFi.h>
#include <WiFiUdp.h>

#define FASTLED_ALLOW_INTERRUPTS 0
#include <FastLED.h>
//https://github.com/BareConductive/mpr121/blob/public/MPR121/MPR121.h
#include <MPR121.h>
#include <Wire.h>
#include <ESP8266HTTPClient.h>
#include <ESP8266httpUpdate.h>
#include <SocketIoClient.h>
#include "base64.h"
#include <ArtnetWifi.h>
extern "C" {
  #include "user_interface.h"
}


FASTLED_USING_NAMESPACE

#define LED_DATA_PIN 4
#define BAUD_RATE 115200
#define LED_TYPE    WS2811
#define LED_COLOR_ORDER GRB
//#define LED_OFFSET 1
#define LED_COUNT    45
#define LED_SEGMENT_COUNT 5
#define LED_PER_SEGMENT_COUNT 9
#define COLOR_BYTE_COUNT      3

#define PIN_SDA 14
#define PIN_SCL 5

uint16_t stationId = 0; //need to pull from EEPROM asap

CRGB leds[LED_COUNT];
float segmentHues[LED_SEGMENT_COUNT];
float segmentSats[LED_SEGMENT_COUNT];
float hueStep = 0.002;
float satStepMag = 0.008;//0.003;
float satSteps[LED_SEGMENT_COUNT];
float briStep1 = 0.03;//brightness off off speed
float briStep2 = 0.007;//recovery
float segmentBris[LED_SEGMENT_COUNT];

uint8_t gHue = 0; // rotating "base color" used by many of the patterns

#define CAPSENSE_COUNT 12
#define CAPSENSE_TOP 11

// this is the touch threshold - setting it low makes it more like a proximity trigger
// default value is 40 for touch
const int touchThreshold = 40;
// this is the release threshold - must ALWAYS be smaller than the touch threshold
// default value is 20 for touch
const int releaseThreshold = 20;
int cap_dev[CAPSENSE_COUNT];
int cap_threshold = 2;
int cap_sum = 0;
bool cap_last[CAPSENSE_COUNT]; //last state
bool cap_curr[CAPSENSE_COUNT]; //curr state

const char* wifi_ssid     = "Orchard";
const char* wifi_pass = "";
const char* server_ip = "192.168.1.100"; //make sure to change this in the checkUpdate() method too
SocketIoClient webSocket;


WiFiUDP _udp;
boolean _udpIsRunning=false;
unsigned int _localUdpPort = 30000; //+stationId?
#define UDP_MAX_INPUT_BYTE_COUNT  32
char _udpIncomingPacket[UDP_MAX_INPUT_BYTE_COUNT];
#define UDP_COMMAND_SETFIVES  5


// Art-Net settings
ArtnetWifi artnet;
int startUniverse = 0; // CHANGE FOR YOUR SETUP most software this is 1, some software send out artnet first universe as 0.

// Check if we got all universes
const int numberOfChannels = LED_COUNT * 3; // Total number of channels you want to receive (1 led = 3 channels)
const int maxUniverses = numberOfChannels / 512 + ((numberOfChannels % 512) ? 1 : 0);
bool universesReceived[maxUniverses];
bool sendFrame = 1;
int previousDataLength = 0;

void initWiFi();
void startWiFi();

void initWebSocket();
void startWebSocket();

void initUDP();
void startUDP();
//void flushUDP();
void stopUDP();

void initArtNet();
void startArtNet();
//void flushArtNet();
void stopArtNet();

void chunkedDelay(int ms, int chunkSize);
//void redraw();
void checkForUpdate();
void EEPROMWriteInt(int p_address, int p_value);
uint16_t EEPROMReadInt(int p_address);
void udpEvent();
void readCapSenseInputs();
void capSenseLEDUpdate();
void PostSetupInitialization();
void SlaveListenUDP();
void StrandTest1();
void StrandTest2();
void StrandTest3();
void CapSenseStandAlone();
void CapSenseControl();
void CapSenseControlTop();
void ArtNetControlled();
void connectSocketEventHandler(const char * payload, size_t payloadLength);
void clearSocketEventHandler(const char * payload, size_t payloadLength);
void fillSolidSocketEventHandler(const char * payload, size_t payloadLength);
void setColorSocketEventHandler(const char * payload, size_t payloadLength);
void setColorsSocketEventHandler(const char * payload, size_t payloadLength);
void setFivesSocketEventHandler(const char * payload, size_t payloadLength);
void checkForUpdateSocketEventHandler(const char * payload, size_t payloadLength);
void setModeSocketEventHandler(const char * payload, size_t payloadLength);
void setStationIdSocketEventHandler(const char * payload, size_t payloadLength);


// Operation Variables
uint8_t operationMode = 4;
typedef void (*OperationFunction) ();
#define OPERATION_COUNT 8
OperationFunction operations[OPERATION_COUNT] = {
  SlaveListenUDP,            // 0 - listening
  StrandTest1,            // 1 - rainbow
  StrandTest2,            // 2 - another strandtest
  StrandTest3,            // 3 - another strandtest
  CapSenseStandAlone,           // 4 - cap sense test
  CapSenseControl,         // 5 - cap sense controller
  CapSenseControlTop,      // 6 - cap sense controller top
  ArtNetControlled      // 7 - artnet control reading
};
OperationFunction Operate = operations[operationMode]; //default startup operation mode

void capSenseLEDUpdate() {
  for (int i = 0; i < LED_SEGMENT_COUNT; i++) {
    //uint32_t STATION_COLOR = HSV_to_RGB(i);
    uint8_t h = (uint8_t)(segmentHues[i]*255);
    float sat = segmentSats[i];
    sat = 2.0*(sat-0.5); //shift from 0.0:1.0 to -1.0:+1.0
    sat = sin(sat*PI/2);//take sin
    bool wasNeg = sat<0;
    sat = (-1*wasNeg)*sqrt(abs(sat));//take square root to make it even flatter
    sat = (sat/2.0)+0.5; //shift back to 0.0:1.0
    
    uint8_t s = (uint8_t)(sat*255);
    uint8_t v = (uint8_t)(segmentBris[i]*255);
    fill_solid(leds + i*LED_PER_SEGMENT_COUNT, LED_PER_SEGMENT_COUNT, CHSV(h,s,v) );
//    for (int j = 0; j < LED_PER_SEGMENT_COUNT; j++) {
//      leds[i*LED_PER_SEGMENT_COUNT+j].setHSV(int(segmentHues[i]*255), int(segmentSats[i]*255), int(segmentBris[i]*255));
//    }
  }
  FastLED.show();
}

void PostSetupInitialization(){};

void SlaveListenUDP() {
  // 0 - listening
  udpEvent(); //check for udp events
}

void StrandTest1() {
  // 1 - rainbow
  fill_rainbow(leds, LED_COUNT, gHue, 7);
  FastLED.show();
  FastLED.delay(1000 / 120);
  EVERY_N_MILLISECONDS(30) {
    gHue++;
  }
}

void StrandTest2() {
  // 2 - sinelon
  // a colored dot sweeping back and forth, with fading trails
  fadeToBlackBy( leds, LED_COUNT, 20);
  int pos = beatsin16(13, 0, LED_COUNT);
  leds[pos] += CHSV( gHue, 255, 192);
  FastLED.show();
  FastLED.delay(1000 / 120);
  EVERY_N_MILLISECONDS(30) {
    gHue++;
  }
}

void StrandTest3() {
  // 3 - juggle
  // eight colored dots, weaving in and out of sync with each other
  fadeToBlackBy( leds, LED_COUNT, 20);
  byte dothue = 0;
  for ( int i = 0; i < 8; i++) {
    leds[beatsin16(i + 7, 0, LED_COUNT)] |= CHSV(dothue, 200, 255);
    dothue += 32;
  }
  FastLED.show();
  FastLED.delay(1000 / 120);
  EVERY_N_MILLISECONDS(30) {
    gHue++;
  }
}


void CapSenseStandAlone() {
  
  readCapSenseInputs();
  
  if (cap_dev[CAPSENSE_TOP] < cap_threshold) {
    for (int j = 0; j < LED_SEGMENT_COUNT; j++) {
      if (segmentBris[j] < 1.0) {
        segmentBris[j] = segmentBris[j] + briStep2;
        segmentBris[j] = segmentBris[j] >= 1.0 ? 1.0 : segmentBris[j];
        break;
      }
    }
    capSenseLEDUpdate();
  }
  for (uint8_t i = 0; i < CAPSENSE_COUNT; i++) {
    cap_curr[i] = cap_dev[i] > cap_threshold; //greater is true is 1 is "pressed"
    if (cap_curr[i]) {
      int bri_or_sat = i / 5;
      int s = i - 5;
      switch (bri_or_sat) {
        case 0:
          segmentHues[i] = (segmentHues[i] + hueStep);
          segmentHues[i] = segmentHues[i] > 1.0 ? segmentHues[i] - 1.0 : segmentHues[i];
          break;
        case 1:
          segmentSats[s] = (segmentSats[s] + satSteps[s]);
          satSteps[s] = segmentSats[s] >= 1.0 ? satSteps[s] * -1 : segmentSats[s] <= 0.0 ? satSteps[s] * -1 : satSteps[s];
          segmentSats[s] = segmentSats[s] >= 1.0 ? 1.0 : segmentSats[s] <= 0.0 ? 0.0 : segmentSats[s];
          break;
        default: //case 2
          for (int j = LED_SEGMENT_COUNT - 1; j >= 0; j--) {
            if (segmentBris[j] > 0.0) {
              segmentBris[j] = segmentBris[j] - briStep1;
              segmentBris[j] = segmentBris[j] <= 0.0 ? 0.0 : segmentBris[j];
              break;
            } else {
              if (j == 0) {
                for (int k = 0; k < LED_SEGMENT_COUNT; k++) {
                  segmentSats[k] = 1.0;
                }
              }
            }
          }
          break;
      }
    }
    
    cap_last[i] = cap_curr[i]; //reset cap_last
  }

  capSenseLEDUpdate();
}


/*
 * with UDP led controls
 * with Socket.Io CapSense controls
 */
void CapSenseControl() {
  udpEvent(); //check for udp events
  EVERY_N_MILLISECONDS(50) {
    readCapSenseInputs();

    for (uint8_t i = 0; i < CAPSENSE_COUNT; i++) {
      cap_curr[i] = cap_dev[i] > cap_threshold; //greater is true if 1 is "pressed"
      //if there was a state change
      if(cap_curr[i]!=cap_last[i]){
        //send the stationId, the id of the cap sensor, and the current state to which it changed
        webSocket.emit("capSense",("\""+String(stationId, DEC)+","+String(i,DEC)+","+String(cap_curr[i],DEC)+"\"").c_str());
        if(cap_curr[i]>cap_last[i]){
          //change was from touched to released
        }else
        {
          //change was from released to touched
        }
      }
      cap_last[i] = cap_curr[i]; //reset cap_last
    }
  }
}

/*
 * with UDP led controls
 * with Socket.Io CapSense controls
 */
void CapSenseControlTop() {
  udpEvent(); //check for udp events
  EVERY_N_MILLISECONDS(50) {
    readCapSenseInputs();
    
    cap_curr[CAPSENSE_TOP] = cap_dev[CAPSENSE_TOP] > cap_threshold; //greater is true if 1 is "pressed"
    //if there was a state change
    if(cap_curr[CAPSENSE_TOP]!=cap_last[CAPSENSE_TOP]){
      //send the stationId, the id of the cap sensor, and the current state to which it changed
      webSocket.emit("capSense",("\""+String(stationId, DEC)+","+String(CAPSENSE_TOP,DEC)+","+String(cap_curr[CAPSENSE_TOP],DEC)+"\"").c_str());
      if(cap_curr[CAPSENSE_TOP]>cap_last[CAPSENSE_TOP]){
        //change was from touched to released
      }else
      {
        //change was from released to touched
    }
    cap_last[CAPSENSE_TOP] = cap_curr[CAPSENSE_TOP]; //reset cap_last
  }

//  EVERY_N_MILLISECONDS(1000) {
//    webSocket.emit("message",("\""+String(stationId, DEC)+","+String(cap_last[CAPSENSE_TOP],DEC)+","+String(cap_curr[CAPSENSE_TOP],DEC)+"\"").c_str());
//      }
  }
}

/*
 * with led control through ArtNet (UDP specific port)
 * with no CapSense controls yet
 */
void ArtNetControlled(){
  // we call the read function inside the loop
  artnet.read();
}



///////////////////////////////////////////////////////////////////////////////////////////////////
///////////////////////////////////////////////////////////////////////////////////////////////////
///////////////////////////////////////////////////////////////////////////////////////////////////
/*
   OTA Updates
*/
///////////////////////////////////////////////////////////////////////////////////////////////////
///////////////////////////////////////////////////////////////////////////////////////////////////
///////////////////////////////////////////////////////////////////////////////////////////////////

void checkForUpdate() {
  Serial.printf("checking for firmware update\n");
  t_httpUpdate_return ret = ESPhttpUpdate.update("http://192.168.1.100:80/update/base", baseVersion);

  switch (ret) {
    case HTTP_UPDATE_FAILED:
      Serial.printf("HTTP_UPDATE_FAILD Error (%d): %s", ESPhttpUpdate.getLastError(), ESPhttpUpdate.getLastErrorString().c_str());
      break;

    case HTTP_UPDATE_NO_UPDATES:
      Serial.println("HTTP_UPDATE_NO_UPDATES");
      break;

    case HTTP_UPDATE_OK:
      Serial.println("HTTP_UPDATE_OK");
      break;
  }
}


///////////////////////////////////////////////////////////////////////////////////////////////////
///////////////////////////////////////////////////////////////////////////////////////////////////
///////////////////////////////////////////////////////////////////////////////////////////////////
/*
   Helper Functions
*/
///////////////////////////////////////////////////////////////////////////////////////////////////
///////////////////////////////////////////////////////////////////////////////////////////////////
///////////////////////////////////////////////////////////////////////////////////////////////////

void chunkedDelay(int ms = 1000, int chunkSize = 10) {
  ////https://github.com/esp8266/Arduino/issues/34
  int chunks = ms / chunkSize;
  for (int i = 0; i < chunks; i++) {
    delay(chunkSize);
  }
}













///////////////////////////////////////////////////////////////////////////////////////////////////
///////////////////////////////////////////////////////////////////////////////////////////////////
///////////////////////////////////////////////////////////////////////////////////////////////////
/*
   Socket.IO Methods
*/
///////////////////////////////////////////////////////////////////////////////////////////////////
///////////////////////////////////////////////////////////////////////////////////////////////////
///////////////////////////////////////////////////////////////////////////////////////////////////

void initWebSocket(){
  webSocket.on("connect", connectSocketEventHandler);
  webSocket.on("getInfo", getInfoSocketEventHandler);
//  webSocket.on("clear", clearSocketEventHandler); //remove to reduce socket.io load
//  webSocket.on("fillSolid", fillSolidSocketEventHandler); //remove to reduce socket.io load
//  webSocket.on("setColor", setColorSocketEventHandler); //remove to reduce socket.io load
//  webSocket.on("setColors", setColorsSocketEventHandler); //remove to reduce socket.io load
  webSocket.on("setFives", setFivesSocketEventHandler);
  webSocket.on("checkForUpdate", checkForUpdateSocketEventHandler);
  webSocket.on("setMode", setModeSocketEventHandler);
  webSocket.on("setStationId", setStationIdSocketEventHandler);
}

void startWebSocket(){
  webSocket.begin(server_ip);
}
  
void subscribeStation(){
  String stationId_str = String(stationId, DEC);
  const char* stationId_char = stationId_str.c_str();
  webSocket.emit("subscribeStation", stationId_char);
}

void connectSocketEventHandler(const char * payload, size_t payloadLength) {
  Serial.printf("connected to server\n");
  subscribeStation();
}

void getInfoSocketEventHandler(const char * payload, size_t payloadLength) {
  Serial.printf("got getInfo message\n");
  String stationId_str = String(stationId, DEC);
  byte mac[6];
  WiFi.macAddress(mac);
  webSocket.emit("idhostnameipmac",
                 ("\"" + stationId_str + ","
                  + String(WiFi.hostname()) + ","
                  + String(WiFi.localIP().toString()) + ","
                  + String(mac[0], HEX) + ","
                  + String(mac[1], HEX) + ","
                  + String(mac[2], HEX) + ","
                  + String(mac[3], HEX) + ","
                  + String(mac[4], HEX) + ","
                  + String(mac[5], HEX) + ","
                  + String(baseVersion)
                  + "\"").c_str()
                );
}

void clearSocketEventHandler(const char * payload, size_t payloadLength) {
  Serial.printf("got clear message\n");
  fill_solid(leds, LED_COUNT, CRGB(0, 0, 0));
  FastLED.show();//doRedraw = true;
}

void fillSolidSocketEventHandler(const char * payload, size_t payloadLength) {
  
  //Serial.printf("got fillSolid message: %s\n", payload);
  unsigned int output_length = decode_base64_length((unsigned char*)payload);
  unsigned char binPayload[output_length];
  decode_base64((unsigned char*)payload, binPayload);

//  webSocket.emit("message",("\""+String(stationId, DEC)+": ["+
//  String(binPayload[0],DEC)+","+
//  String(binPayload[1],DEC)+","+
//  String(binPayload[2],DEC)+","+
//  String(binPayload[3],DEC)+","+
//  String(binPayload[4],DEC)+"]"+
//  "\"").c_str());

  //startIndex
  //numToFill,
  //ledColor (r,g,b)
  fill_solid(leds + (uint8_t)binPayload[0], (uint8_t)binPayload[1], CRGB((uint8_t)binPayload[2], (uint8_t)binPayload[4], (uint8_t)binPayload[3]));
  //fill_solid(leds+0,45,CRGB(0,0,255));
  FastLED.show();//doRedraw = true;
}

void setColorSocketEventHandler(const char * payload, size_t payloadLength) {
  //Serial.printf("got setColor message: %s\n", payload);

  unsigned int output_length = decode_base64_length((unsigned char*)payload);
  unsigned char binPayload[output_length];
  decode_base64((unsigned char*)payload, binPayload);

  //startIndex
  //ledColor (r,g,b)

  int first = (uint8_t)binPayload[0];
  leds[first].r = (uint8_t)binPayload[1];
  leds[first].g = (uint8_t)binPayload[3];
  leds[first].b = (uint8_t)binPayload[2];

  FastLED.show();//doRedraw = true;
}

void setColorsSocketEventHandler(const char * payload, size_t payloadLength) {
  //Serial.printf("got setColors message: %s\n", payload);

  unsigned int output_length = decode_base64_length((unsigned char*)payload);
  unsigned char binPayload[output_length];
  decode_base64((unsigned char*)payload, binPayload);

  //startIndex
  //colorArray[] (r,g,b)
  int first = (uint8_t)binPayload[0];
  int last = first + (output_length - 1) / 3;
  for (int i = first; i < last; i++) {
    leds[i].r = (uint8_t)binPayload[i * COLOR_BYTE_COUNT + 0];
    leds[i].g = (uint8_t)binPayload[i * COLOR_BYTE_COUNT + 2];
    leds[i].b = (uint8_t)binPayload[i * COLOR_BYTE_COUNT + 1];
  }

  FastLED.show();//doRedraw = true;
}

void setFivesSocketEventHandler(const char * payload, size_t payloadLength) {
  Serial.printf("got setFives message: %s\n", payload);

  unsigned int output_length = decode_base64_length((unsigned char*)payload);

  unsigned char binPayload[output_length];
  decode_base64((unsigned char*)payload, binPayload);

  for (int i = 0; i < LED_COUNT; i++) {
    leds[i].r = (uint8_t)binPayload[(i / LED_PER_SEGMENT_COUNT) * COLOR_BYTE_COUNT + 0];
    leds[i].g = (uint8_t)binPayload[(i / LED_PER_SEGMENT_COUNT) * COLOR_BYTE_COUNT + 2];
    leds[i].b = (uint8_t)binPayload[(i / LED_PER_SEGMENT_COUNT) * COLOR_BYTE_COUNT + 1];
  }

  FastLED.show();//doRedraw = true;
}

void checkForUpdateSocketEventHandler(const char * payload, size_t payloadLength) {
  Serial.printf("got checkForUpdate message: %s\n", payload);
  checkForUpdate();
}

void setModeSocketEventHandler(const char * payload, size_t payloadLength) {
  Serial.printf("got setMode: %s\n", payload);

  unsigned int output_length = decode_base64_length((unsigned char*)payload);

  unsigned char binPayload[output_length];
  decode_base64((unsigned char*)payload, binPayload);


OperationFunction operations[OPERATION_COUNT] = {
  SlaveListenUDP,            // 0 - listening
  StrandTest1,            // 1 - rainbow
  StrandTest2,            // 2 - another strandtest
  StrandTest3,            // 3 - another strandtest
  CapSenseStandAlone,           // 4 - cap sense test
  CapSenseControl,         // 5 - cap sense controller
  CapSenseControlTop,      // 6 - cap sense controller top
  ArtNetControlled      // 7 - artnet control reading
};

  uint8_t newOperationMode = (uint8_t)binPayload[0];
  if(operationMode==0 || operationMode==5 || operationMode==6){
    stopUDP();
  }
  if(operationMode==7){
    stopArtNet();
  }

  operationMode = newOperationMode;
  if(operationMode==0 || operationMode==5 || operationMode==6){
    startUDP();
  }
  if(operationMode==7){
    startArtNet();
  }
  
  Operate = operations[operationMode];
}

void setStationIdSocketEventHandler(const char * payload, size_t payloadLength) {
  Serial.printf("got setStationId: %s\n", payload);

  unsigned int output_length = decode_base64_length((unsigned char*)payload);

  unsigned char binPayload[output_length];
  decode_base64((unsigned char*)payload, binPayload);

  stationId = binPayload[0] + binPayload[1]*256;
  EEPROM.begin(512);
  EEPROMWriteInt(0, stationId);
  
  EEPROM.commit();
  EEPROM.end(); //also commits in addition to release from RAM copy
}





///////////////////////////////////////////////////////////////////////////////////////////////////
///////////////////////////////////////////////////////////////////////////////////////////////////
///////////////////////////////////////////////////////////////////////////////////////////////////
/*
   WiFi Methods
*/
///////////////////////////////////////////////////////////////////////////////////////////////////
///////////////////////////////////////////////////////////////////////////////////////////////////
///////////////////////////////////////////////////////////////////////////////////////////////////

void initWiFi(){
  WiFi.mode(WIFI_OFF);
  WiFi.disconnect(); //in version 2.3.0 of ESP8266 library, can't WiFi.begin if already connected or more than 1 second of delay
  delay(100);
  WiFi.mode(WIFI_STA);
  wifi_set_sleep_type(NONE_SLEEP_T); //70mA power; without this should be 18mA average as it wakes up every <100ms to check for data
  WiFi.setAutoConnect(true);
  WiFi.setAutoReconnect(true);  
}

void startWiFi(){
 WiFi.begin(wifi_ssid, wifi_pass);
}
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
void loop() {
  webSocket.loop();
  Operate();
  
  //check for firmware updates once every ten minutes
  EVERY_N_SECONDS(600) {
    if (WiFi.status() == WL_CONNECTED) {
      checkForUpdate();
    }
  }

  EVERY_N_SECONDS(280) {
    subscribeStation(); //subscribeStation periodically to make sure we can address them in socket.io by station name
  }
}

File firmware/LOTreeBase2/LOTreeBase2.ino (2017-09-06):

///////////////////////////////////////////////////////////////////////////////////////////////////
//use Flash size 4MB (1M SPIFFS)
///////////////////////////////////////////////////////////////////////////////////////////////////
//Flash real id:   001640EF
///////////////////////////////////////////////////////////////////////////////////////////////////
//Flash real size: 4194304
///////////////////////////////////////////////////////////////////////////////////////////////////


const char* baseVersion = "2003";

#include <EEPROM.h>
#include <ESP8266WiFi.h>

#include <ESP8266HTTPClient.h>
#include <ESP8266httpUpdate.h>

//#include <WiFiUDP.h>
//#include <SocketIoClient.h>
//#include "base64.hpp"

//https://github.com/FastLED/FastLED/wiki/Interrupt-problems

//#define FASTLED_INTERRUPT_RETRY_COUNT 1
//#define FASTLED_ALLOW_INTERRUPTS 0
//#include "FastLED.h"
#include <FastLED.h>
//FASTLED_USING_NAMESPACE

//#if defined(FASTLED_VERSION) && (FASTLED_VERSION < 3001000)
//#warning "Requires FastLED 3.1 or later; check github for latest code."
//#endif

#include <MPR121.h>
#include <Wire.h>


#define LED_DATA_PIN          4
#define LED_TYPE              WS2811
#define LED_COLOR_ORDER       GRB
#define LED_COUNT             45
#define LED_SEGMENT_COUNT     5
#define LED_PER_SEGMENT_COUNT 9
// 3 bytes of color, 5 segments, 36 stations = 540 bytes
#define COLOR_BYTE_COUNT      3
#define STATION_BYTE_COUNT    15

#define PIN_SDA               14
#define PIN_SCL               5

int stationId = 0; //need to pull from EEPROM asap

// LED Variables
CRGB leds[LED_COUNT];
CRGB stationColors[LED_SEGMENT_COUNT];
boolean doRedraw = true;
uint8_t gHue = 0; // rotating "base color" used by many of the patterns

// WiFi Variables
//ESP8266WiFiMulti WiFiMulti;
const char* wifi_ssid     = "Orchard";
const char* wifi_pass = "";
const char* server_ip = "192.168.0.100";
//SocketIoClient webSocket;

// UDP Variables
unsigned int udpPort = 60000;
byte packetBytesBuffer[STATION_BYTE_COUNT];
int packetBytesIndex = 0;
int packetLength = 0;
byte packetBytes[STATION_BYTE_COUNT];
bool packetComplete = false;
//WiFiUDP udpSocket;

// CapSense Variables
float segmentHues[LED_SEGMENT_COUNT];
float segmentSats[LED_SEGMENT_COUNT];
float hueStep = 0.002;
float satStepMag = 0.003;
float satSteps[LED_SEGMENT_COUNT];
float briStep1 = 0.03;
float briStep2 = 0.007;
float segmentBris[LED_SEGMENT_COUNT];

// this is the touch threshold - setting it low makes it more like a proximity trigger
// default value is 40 for touch
const int touchThreshold = 40;
// this is the release threshold - must ALWAYS be smaller than the touch threshold
// default value is 20 for touch
const int releaseThreshold = 20;
int cap_dev[12];
int cap_threshold = 2;
int cap_sum = 0;





///////////////////////////////////////////////////////////////////////////////////////////////////
///////////////////////////////////////////////////////////////////////////////////////////////////
///////////////////////////////////////////////////////////////////////////////////////////////////
/*
   Function Definitions
*/
///////////////////////////////////////////////////////////////////////////////////////////////////
///////////////////////////////////////////////////////////////////////////////////////////////////
///////////////////////////////////////////////////////////////////////////////////////////////////


void chunkedDelay(int ms, int chunkSize);
void redraw();
void checkForUpdate();
void EEPROMWriteInt(int p_address, int p_value);
unsigned int EEPROMReadInt(int p_address);
void udpEvent();
void readCapSenseInputs();
void capSenseLEDUpdate();
void PostSetupInitialization();
void StrandTest();
void SlaveListen();
void CapSenseControl();
void StrandTest2();
void StrandTest3();
void connectSocketEventHandler(const char * payload, size_t payloadLength);
void clearSocketEventHandler(const char * payload, size_t payloadLength);
void fillSolidSocketEventHandler(const char * payload, size_t payloadLength);
void setColorSocketEventHandler(const char * payload, size_t payloadLength);
void setColorsSocketEventHandler(const char * payload, size_t payloadLength);
void setFivesSocketEventHandler(const char * payload, size_t payloadLength);
void checkForUpdateSocketEventHandler(const char * payload, size_t payloadLength);
void setModeSocketEventHandler(const char * payload, size_t payloadLength);
void setStationIdSocketEventHandler(const char * payload, size_t payloadLength);




///////////////////////////////////////////////////////////////////////////////////////////////////
///////////////////////////////////////////////////////////////////////////////////////////////////
///////////////////////////////////////////////////////////////////////////////////////////////////
/*
   Poor Man's Base64
*/
///////////////////////////////////////////////////////////////////////////////////////////////////
///////////////////////////////////////////////////////////////////////////////////////////////////
///////////////////////////////////////////////////////////////////////////////////////////////////

const char map64[64] = {
  'A', //  0
  'B', //  1
  'C', //  2
  'D', //  3
  'E', //  4
  'F', //  5
  'G', //  6
  'H', //  7
  'I', //  8
  'J', //  9
  'K', // 10
  'L', // 11
  'M', // 12
  'N', // 13
  'O', // 14
  'P', // 15
  'Q', // 16
  'R', // 17
  'S', // 18
  'T', // 19
  'U', // 20
  'V', // 21
  'W', // 22
  'X', // 23
  'Y', // 24
  'Z', // 25
  'a', // 26
  'b', // 27
  'c', // 28
  'd', // 29
  'e', // 30
  'f', // 31
  'g', // 32
  'h', // 33
  'i', // 34
  'j', // 35
  'k', // 36
  'l', // 37
  'm', // 38
  'n', // 39
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
};

const uint8_t demap64[128] = {
  0, //  0
  0, //  1
  0, //  2
  0, //  3
  0, //  4
  0, //  5
  0, //  6
  0, //  7
  0, //  8
  0, //  9
  0, // 10
  0, // 11
  0, // 12
  0, // 13
  0, // 14
  0, // 15
  0, // 16
  0, // 17
  0, // 18
  0, // 19
  0, // 20
  0, // 21
  0, // 22
  0, // 23
  0, // 24
  0, // 25
  0, // 26
  0, // 27
  0, // 28
  0, // 29
  0, // 30
  0, // 31
  0, // 32
  0, // 33
  0, // 34
  0, // 35
  0, // 36
  0, // 37
  0, // 38
  0, // 39
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
};






///////////////////////////////////////////////////////////////////////////////////////////////////
///////////////////////////////////////////////////////////////////////////////////////////////////
///////////////////////////////////////////////////////////////////////////////////////////////////
/*
   Helper Functions
*/
///////////////////////////////////////////////////////////////////////////////////////////////////
///////////////////////////////////////////////////////////////////////////////////////////////////
///////////////////////////////////////////////////////////////////////////////////////////////////

void chunkedDelay(int ms = 1000, int chunkSize = 10) {
  ////https://github.com/esp8266/Arduino/issues/34
  int chunks = ms / chunkSize;
  for (int i = 0; i < chunks; i++) {
    delay(chunkSize);
  }
}
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

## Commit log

2017-02-25 added draft sketch of esp8266 based solution
    [GOLMain_RevA.kicad_pcb, GOLMain_RevA.sch]
2017-02-25 added initial bill of materials mostly consisting of the electronics and power systems with estimated parts list
    [GOL-BOM.xls, GOLMain_RevA.kicad_pcb, _saved_GOLMain_RevA.sch]
2017-02-25 updated schematic and layout for proposed RevA
    [GOLMain_RevA.kicad_pcb, GOLMain_RevA.sch, _saved_GOLMain_RevA.sch]
2017-03-10 updated main board schematic and layout
    [GOL-BOM.xls, GOLMain_RevA.kicad_pcb, GOLMain_RevA.sch]
2017-03-11 updated schematics and part selection for layout
    [GOLMain_RevA.kicad_pcb, GOLMain_RevA.sch]
2017-03-17 near final version of pcb layout
    [GOL-BOM.xls, GOLMain_RevA-outline.dwg, GOLMain_RevA-outline.dxf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]
2017-03-18 updated main pcb to final version
    [GOLMain_RevA-B.Cu.gbl, GOLMain_RevA-B.Mask.gbs, GOLMain_RevA-B.SilkS.gbo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]
2017-03-22 refined main board, shift 4 pin led conn, made more space for gnd and v12 planes; created tcrt5000 module
    [GOLMain_RevA-B.Cu.gbl, GOLMain_RevA-B.Mask.gbs, GOLMain_RevA-B.Paste.gbp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]
2017-03-22 added panelization of 12 units of the GOLReader, to cut pcb fabrication cost in half
    [GOLReader_RevA-B.Cu.gbl, GOLReader_RevA-B.Mask.gbs, GOLReader_RevA-B.SilkS.gbo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]
2017-03-27 Version 1 Lamp Files
    [LampBlock_V1.SLDPRT, LampBlock_V1_Bottom.STL, LampBlock_V1_Bottom.sldprt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]
2017-03-27 Lamp Version 2 files
    [LampBLock_V2_Hook4.STL, LampBLock_V2_Hook4.sldprt, LampBLock_V2_PlateSupport.STL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]
2017-03-27 Lamp Version 3 Files
    [94500A223_TYPE 316 SS BUTTON-HEAD SOCKET CAP SCREW.SLDPRT, GameOfLightLamp_V3 - BottomCap^GameOfLightLamp_V3-1.STL, GameOfLightLamp_V3 - BottomLid^GameOfLightL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]
2017-04-04 added basic station string test firmware
    [GOLMain_RevA-B.Cu.gbl, GOLMain_RevA-B.Mask.gbs, GOLMain_RevA-B.Paste.gbp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]
2017-04-16 added GOLStationSerialEventTest to test serial events through FTDI or RS485 connection. Should send a byte through serial connection and will do a color wipe with that hue value on the color wheel
2017-04-18 corrected led count to 45 in text sketches; added rs485 LOW on pin 13 for listening for stations; added pcb design for a power link to power the rs485 rails for a usb connector
    [GOLRS485PowerLink_RevA.kicad_pcb, GOLRS485PowerLink_RevA.sch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]
2017-04-26 updated samples with pull down on pin 13 for rs485 listen; added coded wheel for 0 and 255 black and white; added FiveSegmentRGB firmware for raw uncompressed byte array of 540 bytes at 57600 baud
    [GOL-BOM.xls]
2017-04-26 fixed a few indexing values in FiveSegmentRGB firmware; created test java processing sketch to send out test colors over serial
    [GOLStationFiveSegmentRGB.ino, GOLStationFiveSegmentRGB_RainbowTest.pde, game_of_light_v3.pde]
2017-04-26 processing and arduino sketches working for id responsive 5 segment strips with 540 byte packets; needs serial double buffer optimization to avoid serial buffer overflow in esp8266 of 128bytes
    [GOLStationFiveSegmentRGB.ino, GOLStationFiveSegmentRGB_RainbowTest.pde]
2017-04-29 added pcb for psu power adapter board
    [GOLPSUPowerAdapter_RevA.kicad_pcb, GOLPSUPowerAdapter_RevA.sch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]
2017-05-01 Added processing base sketch for communicating to stations
    Also added two games, conway and city.
    [station_states.csv]
2017-05-01 modified power board to fit mill better
    [GOLMain_RevA-B.Cu.gbr, GOLMain_RevA-B.Mask.gbr, GOLMain_RevA-B.SilkS.gbr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]
2017-05-01 fixed bugs and included station change animation
    [station_states.csv]
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2017-05-02 firmware update, increased baud to 115200, disabled wifi, added more checks and recovery on errors in serial data received
    [GOLStationFiveSegmentRGB.ino, GOLStationFiveSegmentRGB_RainbowTest.pde]
2017-05-03 added modbus slave and master tests; not working yet
    [GOLModBusTest.ino, GOLStationFiveSegmentRGB_RainbowTest.pde, listports.js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]
2017-05-03 integrated a diff and dediff differencing encoding scheme to deal with zeros in the uart byte array
2017-05-04 Processing game files and image client
    [station_states.csv]
2017-05-16 Processing sketches used at CHI 2017
    [station_states.csv]
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2017-06-14 added more server side socket.io methods for emitting colors to the stations
2017-06-27 implemented byte based implementation of socketio client comms of five segment color transmission per station id; compiles, not tested; node server contains all emit functions;
    [LO_Necklet_RevA.kicad_pcb, LO_Necklet_RevA.sch]
2017-06-28 fixed doStuff interval test function on webserver for testing
    [LOTreeSocket.ino]
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2017-07-07 minor updates to eeprom clearning and station id and hardware reset functions
    [LOTreeEEPROMID.ino, LOTreeWebSocket.ino]
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2017-08-09 firmware updates but udp not yet correct parsing for led bytes
    [LOTreeEEPROMID.ino, LOTreeUDP.ino, LOTreeWebSocket.ino]
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2017-08-15 fixed bug (again) (sorry)
    [LO_mpr121_and_led_test_esp8266_cz.ino]
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2017-09-01 version 1008, added 20 retry skip on mpr121 setup while loop
    [LOTreeBase.ino]
2017-09-02 version 1011; cleaned up variables and naming; added function prototypes; swapped library order of FastLED and Wire; added FASTLED_INTERRUPT_RETRY_COUNT 1 before FastLED.h library include
    [LOTreeBase.ino]
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2017-09-02 version 1013; added wire library and begin calls back in, since rainbow strandtest was working with version 1012
2017-09-02 version 1015; change MPR121 setup while loop to a single begin call
    [GOLMain_RevA.sch]
2017-09-02 version 1016; added FASTLED_ALLOW_INTERRUPTS 0 before FastLED include; changed server to push currently specified version, regardless of greater than sequence
2017-09-02 correct hsv values to be between 0-255
    [LO_mpr121_and_fastLED_test_cz.ino]
2017-09-02 corrected LED index to sets of 9 in 5 layers
    [LO_mpr121_and_fastLED_test_cz.ino]
2017-09-03 version 1017; modified LO_mpr121_and_fastLED_test_cz to match variable format for simpler compatability - needs verification that it still works; modified webserver to use the base0000.bin file based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
    [LOTreeBase.ino, LO_mpr121_and_fastLED_test_cz.ino]
2017-09-04 version 1018; removed FastLED no interrupt options; added a few more serial logging lines; direclty called FastLED.show() instead of setting doRedraw to true;
2017-09-04 version 1020; cut out udp and a few socketio methods; removed 2 minute updatecheck; removed redraw and made all direct calls to FastLed.show(); added eeprom to LO_mpr121_and_fastLED_test_cz.ino
2017-09-06 version 3005; successfully merged code bases for socket io and operation function delegation along with the cap sense painting code
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2017-09-12 added request station info button to manager.html; added five color input sample to test.html
2017-09-12 version 3008; reduced check updates to only explicit; corrected column headers in manager.html; added online to false on station disconnect; began to look into socket id emit method
    [LOTreeBase3.ino]
2017-09-12 version 3009; added capsensetest without emit functions and resorted the operation modes in both firmware, server, and web pages; changed io.to(socketid) to socket.broadcast.to(socketid)
2017-09-12 updated manager.html with onlick instead of onchange for ping and update buttons; added console logging to managerial socketio method events from web browsers
2017-09-13 version 3010; swapped bit shifting order of setStationId inputs
    [LOTreeBase3.ino]
2017-09-13 version 3011; maybe this time corrected the bitshift operators for the stationId
    [LOTreeBase3.ino]
2017-09-13 resolved setStationMode issue on manager by adding command setMode to emit; resolved fiveColor issue on test.html to changing to socket.broadcast.to(socket).emit(...
2017-09-13 replaced socketid with the correct stationid in the setGiveColorsListener method
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2018-03-24 pushed client side emulator
    [station_states.csv]
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2019-03-01 beginning of next gen electronics base for power, but not much
    [LO_Main_RevB-outline.dwg, LO_Main_RevB-outline.dxf, LO_Main_RevB.kicad_pcb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]
2019-03-07 base4002, fixed checkUpdate ip address in firmware; need to go back to old wifi for at least 10 minutes to receive update
    [LOTreeBase4.ino]
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
